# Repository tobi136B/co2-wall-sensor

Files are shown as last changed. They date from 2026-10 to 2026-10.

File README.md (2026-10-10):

<div align="center">

# CO2 Wall Sensor

**A compact CO2, temperature and humidity monitor for Home Assistant.<br>
It covers a flush wall box or stands on your desk.**










**English** | [Deutsch](README.de.md) | [Project page and browser installer](https://tobi136b.github.io/co2-wall-sensor/)

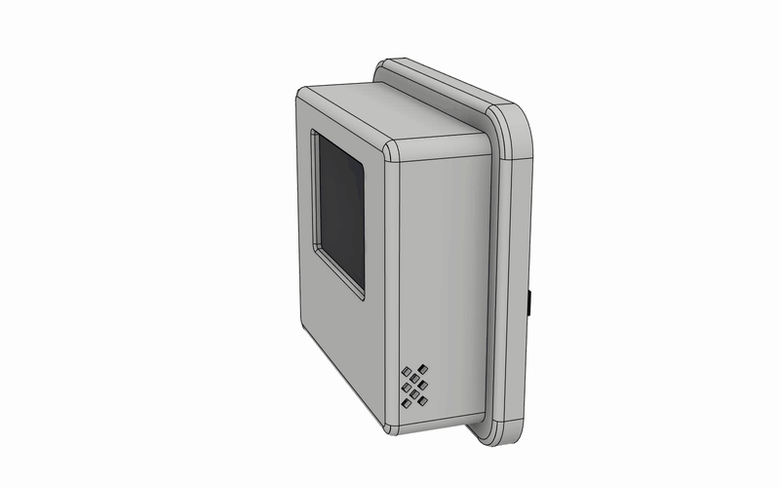
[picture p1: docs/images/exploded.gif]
The CO2 Wall Sensor takes itself apart part by part and assembles itself again


</div>

---

## Highlights

* **Flash it from your browser.** Connect the ESP32-C3 via USB, click *Install* on the [project page](https://tobi136b.github.io/co2-wall-sensor/), enter your WiFi. Home Assistant finds the device and offers new releases as a firmware update.
* **Real CO2 measurement** with the Sensirion SCD41 (photoacoustic NDIR), plus temperature and humidity.
* **2" IPS colour display** with everything at a glance: traffic light status, large CO2 value, 3 hour trend, clock, indoor and outdoor temperature and humidity.
* **Window hint.** The display tells you when opening the window cools the room or dries the air, using an outdoor sensor or simply your Home Assistant weather forecast.
* **Everything adjustable in Home Assistant.** Night schedule (dim or off), night brightness, warnings at night, temperature correction, altitude and hint thresholds, no reflashing needed.
* **One device, two mounts.** A dovetail rail slides onto the **wall plate** (two M4 screws with wall plugs, or the screws of a 68 mm flush wall box) or the **desk stand**.
* **Cable from the back or from below** with the same parts: a 90° USB-C adapter leads the cable straight into the wall, or a straight cable leaves through the window in the bottom.
* **One screw type, nothing glued.** 10 heat-set inserts M2 × 3 and 10 button head screws M2 × 4. The SCD41 and the ESP32-C3 slide into rails and click behind spring hooks, the display cable stays plugged in and runs under a printed bridge.
* **Thought-through thermals.** The sensor lives in its own chamber below the electronics, fresh air enters from below, the front stays closed.
* **Fully parametric CAD.** Every dimension is a Fusion user parameter. Change a value, run the script, get new STL, STEP, print plates and drawing.
* **Bilingual.** Firmware, documentation, drawings and project page in English and German.

<div align="center">
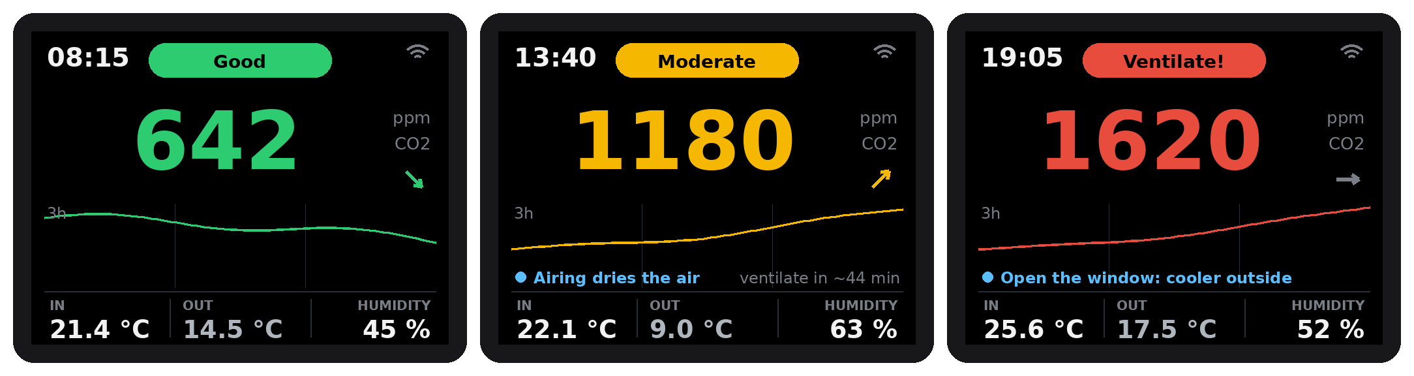
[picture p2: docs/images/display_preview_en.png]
Display layout in the three air quality states

<br><sub>Display layout in the three states (mock-up generated by <code>tools/display_preview.py</code>)</sub>
</div>

## How it works

```mermaid
flowchart LR
    SCD41["SCD41<br>CO2 / temp / humidity"] -- I2C --> ESP["ESP32-C3 SuperMini<br>ESPHome"]
    ESP -- SPI --> LCD["2&quot; IPS display<br>320 x 240"]
    ESP <-- "WiFi, native API" --> HA["Home Assistant"]
    USB["USB-C 5 V<br>(wall box or surface cable)"] --> ESP
    GH["GitHub releases"] -. "firmware update" .-> HA
```

Every 30 seconds the SCD41 delivers a new reading. The ESP32-C3 updates the display, classifies the air quality against two thresholds (default 1000 and 1400 ppm) and reports everything to Home Assistant.

## Specifications

| | |
|---|---|
| Device | 77 × 69.8 × 24 mm (+ 3 mm rail) |
| Wall plate | 89.2 × 82 × 7 mm, slots for M4 screws 60 mm apart, also fits flush wall boxes Ø 68 mm |
| Display window | 41.8 × 31.6 mm, 320 × 240 px IPS |
| Sensor | Sensirion SCD41, 400 to 5000 ppm, ±(50 ppm + 5 % of reading) |
| Room size | one sensor per room; in open spaces up to about 500 m² ([FAQ](docs/faq.md#how-large-a-room-can-one-sensor-monitor)) |
| Power | 5 V via USB-C, about 0.5 W |
| Cable exit | back (90° USB-C adapter) or bottom (straight plug), same parts |
| Fasteners | 10 heat-set inserts M2 × 3 (OD 3.0 to 3.2), 10 screws M2 × 4 ISO 7380, 2 screws M4 for the wall |
| Print material | PETG (PLA possible), about 120 g |

Technical drawing (A3, ISO first angle): [English PDF](docs/drawing/co2_wall_sensor_drawing_en.pdf) | [German PDF](docs/drawing/co2_wall_sensor_drawing_de.pdf)

<div align="center">
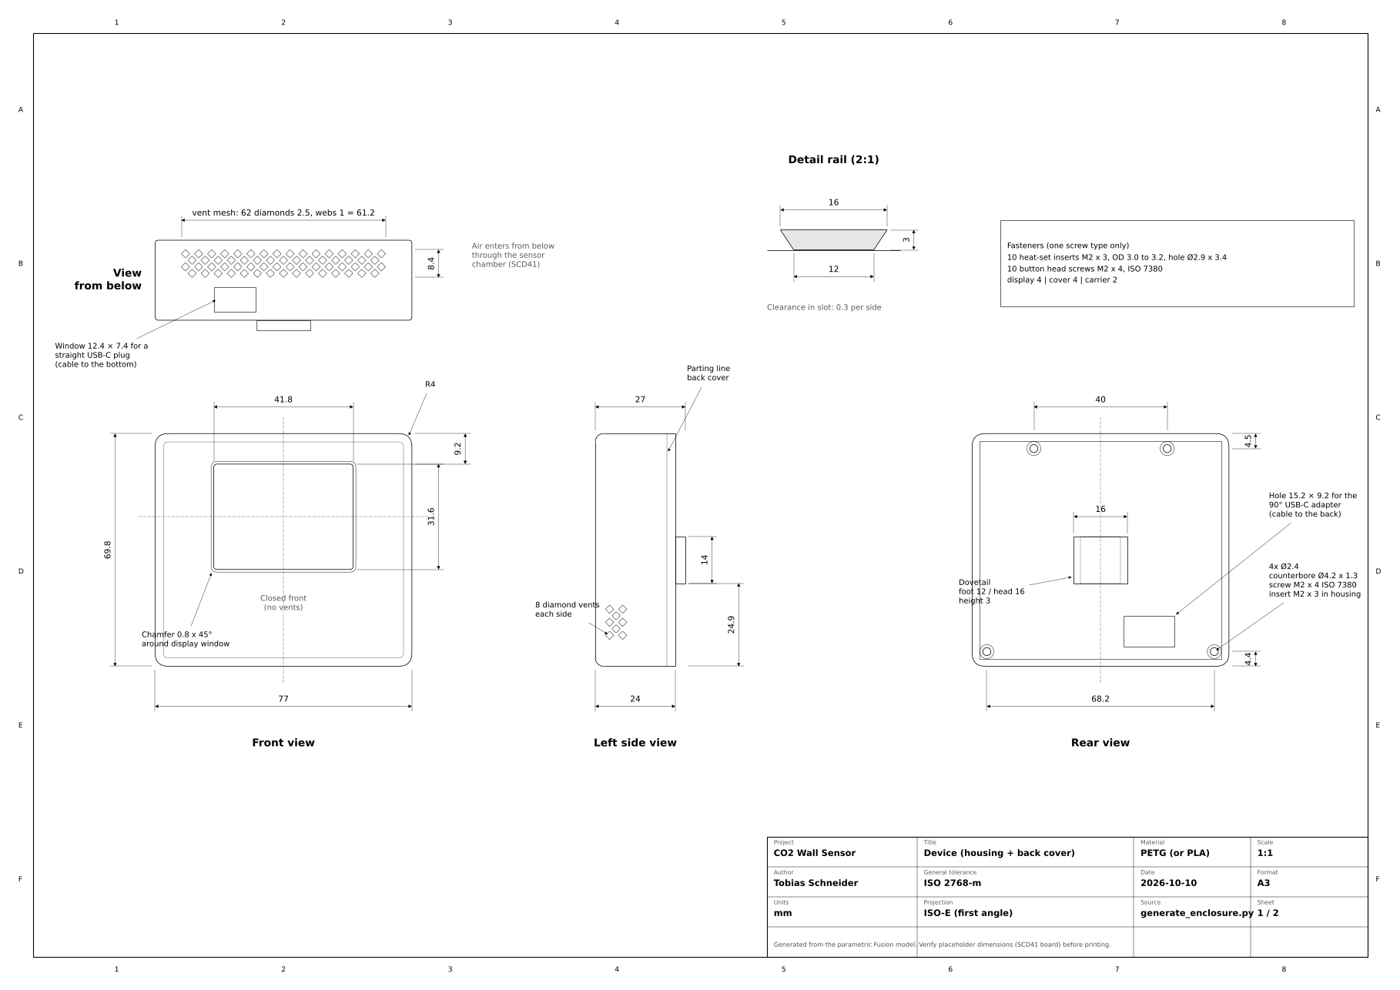
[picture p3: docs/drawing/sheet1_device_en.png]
Drawing sheet 1

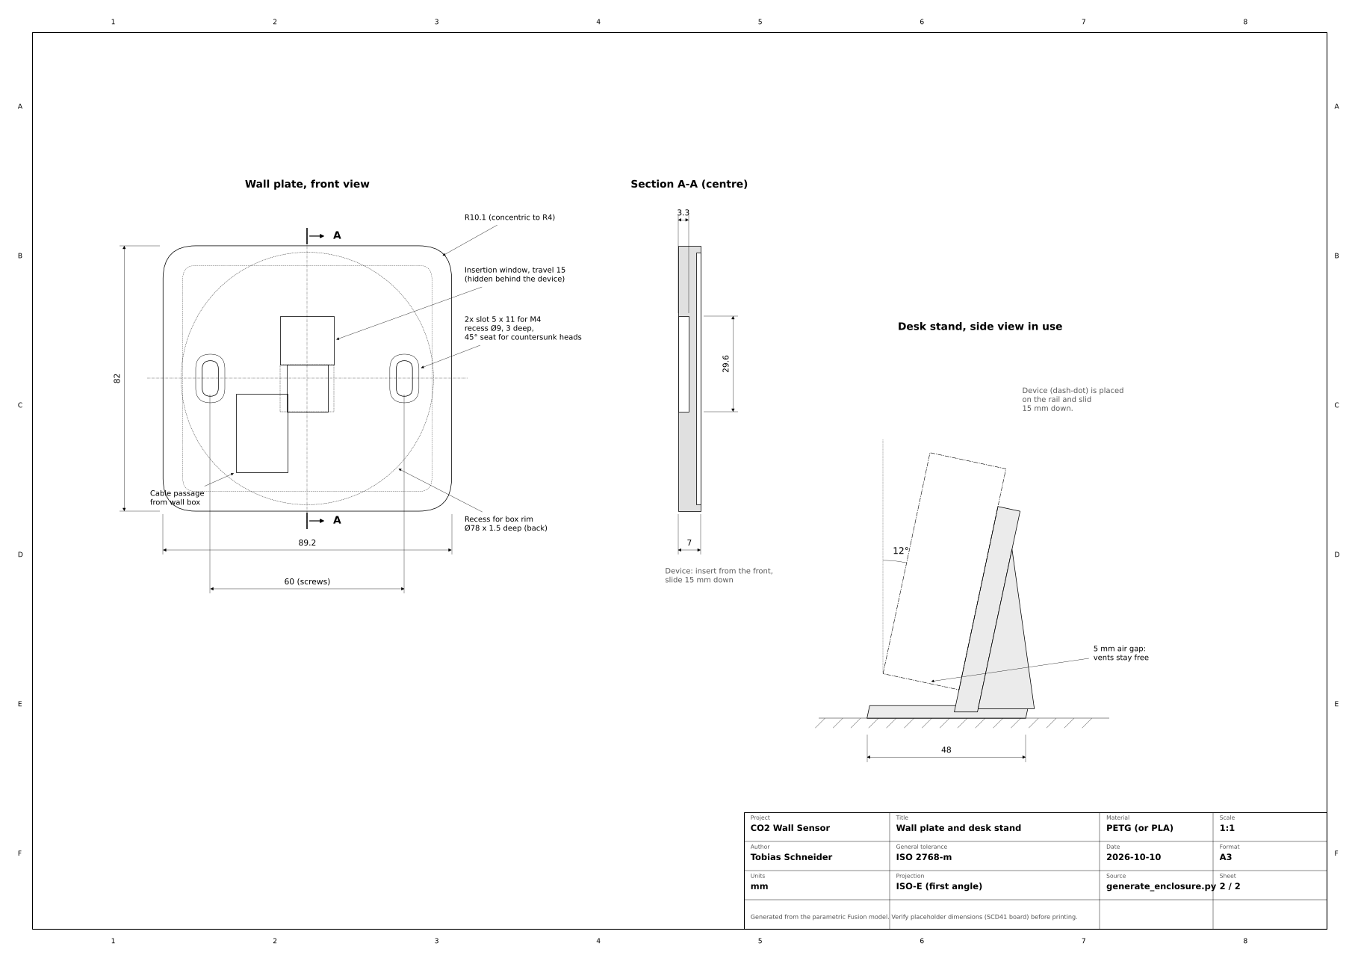
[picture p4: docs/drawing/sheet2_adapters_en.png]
Drawing sheet 2

</div>

## Bill of materials

The total for one device is in the last row of the table. The links are suggestions, checked in October 2026; prices change often.

<!-- bom:start (generated from hardware/bom.yaml) -->
| Qty | Part | AliExpress | Amazon.de |
|----:|---|---:|---:|
| 1 | Sensirion **SCD41** breakout, **13.5 × 21.75 mm** or **15 × 20 mm** ² | [21.19 €](https://de.aliexpress.com/item/1005009740863220.html) | *AliExpress only* |
| 1 | **ESP32-C3 SuperMini** | [2.79 €](https://de.aliexpress.com/item/1005007479144456.html) | [4.30 € (2 pcs: 8.59 €)](https://www.amazon.de/dp/B0HDCHXHMT) |
| 1 | **Waveshare 2inch LCD Module** (ST7789V, 240 × 320) | [12.49 €](https://de.aliexpress.com/item/1005008772378337.html) | [16.31 €](https://www.amazon.de/dp/B081Q79X2F) |
| 10 | Heat-set insert **M2 × 3**, outer diameter 3.0 or 3.2 mm, length 3 mm | [2.39 € (50 pcs, OD 3.2)](https://de.aliexpress.com/item/1005008575446687.html) | [4.69 € (205 pcs, OD 3.0)](https://www.amazon.de/dp/B0GYPH7X6W) |
| 10 | Button head screw **M2 × 4**, ISO 7380 | *Amazon only* | [4.79 € (60 pcs)](https://www.amazon.de/dp/B0FVT11R5L) |
| 1 | **USB-C 90° adapter** (plug to socket) for the cable to the back | *Amazon only* | [4.49 €](https://www.amazon.de/dp/B0CVQ8LV5W) |
| 1 | USB power module for the flush wall box (installation by a qualified electrician), or any USB charger | *Amazon only* | [4.80 € (2 pcs: 9.59 €)](https://www.amazon.de/dp/B0GVWPHKJM) |
|  | Silicone wire AWG 30 | *Amazon only* | [15.49 € (8 colours)](https://www.amazon.de/dp/B0DH2FBWH7) |
| | **Total** (one device, each part from this shop if it has it, otherwise from the other; without wire and filament) | **52.94 €** | **60.57 €** |
<!-- bom:end -->

² Shops often show a different board than the one they send. Measure it on arrival and print the matching carrier.
SCD41 boards come in different sizes. Only the small sensor carrier depends on the board: there is one for the **13.5 × 21.75 mm** and one for the **15 × 20 mm** board, for others enter six measurements in the [online configurator](https://tobi136b.github.io/co2-wall-sensor/configurator.html) and download the carrier. See [measure your sensor](docs/measure-sensor.md).
Machine-readable: [`hardware/bom.yaml`](hardware/bom.yaml). This file is the only place for parts, prices and shop links; the table above and the project page are generated from it.

## Quick start

1. **Print** the two ready plates [`co2_wall_sensor_device.3mf`](cad/3mf/co2_wall_sensor_device.3mf) and [`co2_wall_sensor_mounts.3mf`](cad/3mf/co2_wall_sensor_mounts.3mf) (every part already in its print orientation, the device plate includes the desk stand: delete it for a wall mount) or the single files from [`cad/stl`](cad/stl). Settings: [docs/assembly.md](docs/assembly.md).
2. **Wire** the modules according to [docs/wiring.md](docs/wiring.md) and **assemble** them as described in [docs/assembly.md](docs/assembly.md). The [3D assembly guide](https://tobi136b.github.io/co2-wall-sensor/assembly.html) shows every step: turn the device, take it apart and see which part comes next.

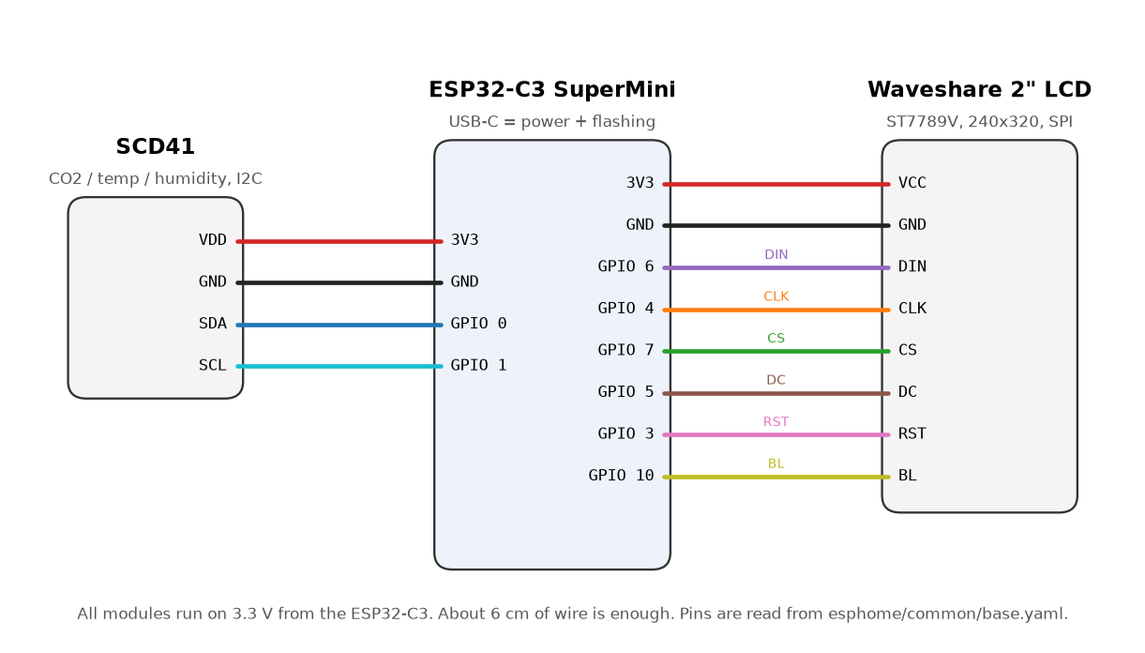
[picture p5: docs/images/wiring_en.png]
Wiring diagram
   

3. **Flash** the firmware from your browser on the [project page](https://tobi136b.github.io/co2-wall-sensor/). To build it yourself: copy `esphome/secrets.yaml.example` to `secrets.yaml`, fill it in and install [`esphome/co2-wall-sensor.yaml`](esphome/co2-wall-sensor.yaml) with the ESPHome Builder (German interface: [`co2-wall-sensor-de.yaml`](esphome/co2-wall-sensor-de.yaml)).
4. **Home Assistant** discovers the device automatically.

<div align="center">
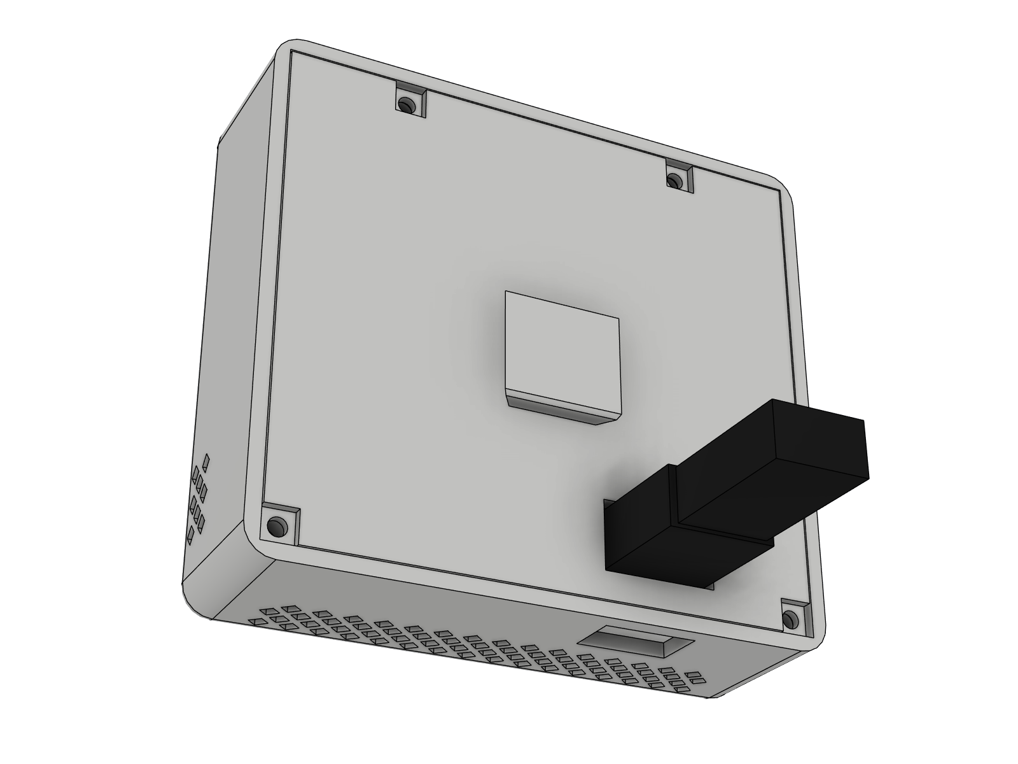
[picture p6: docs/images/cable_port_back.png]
Cable to the back

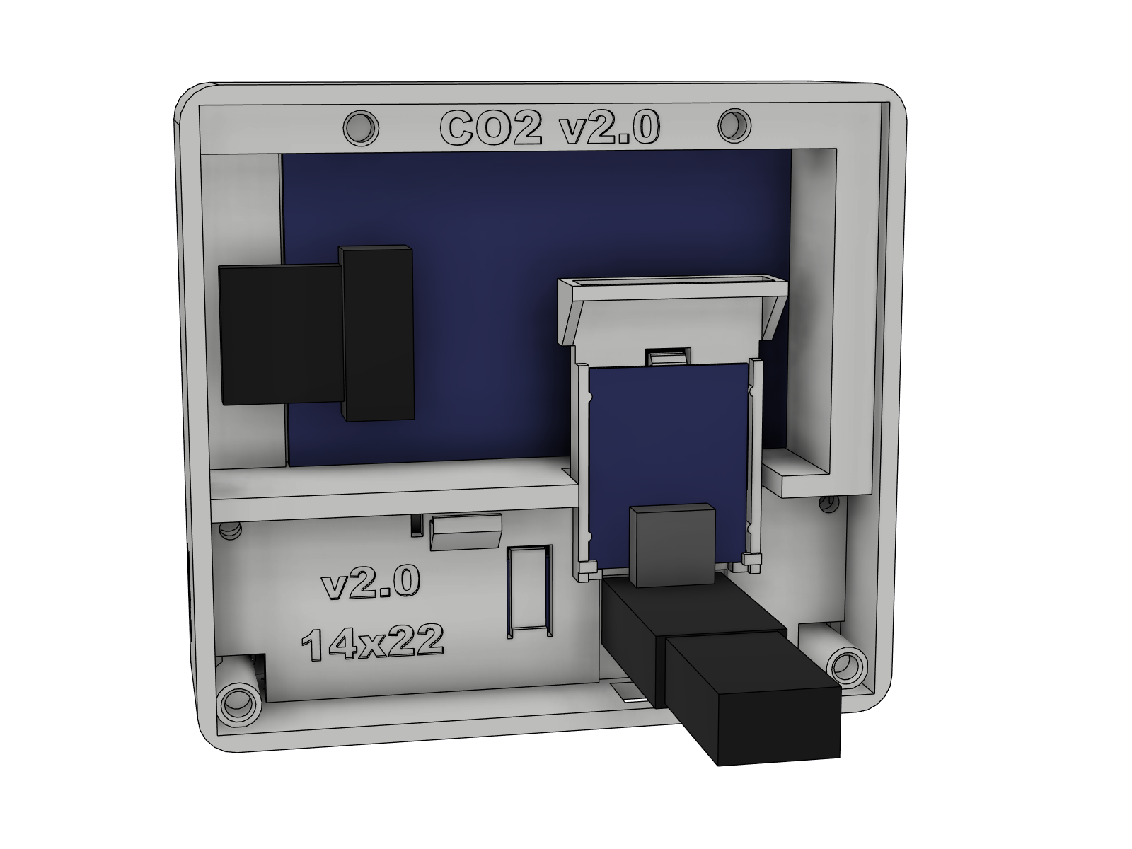
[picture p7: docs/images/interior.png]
Interior

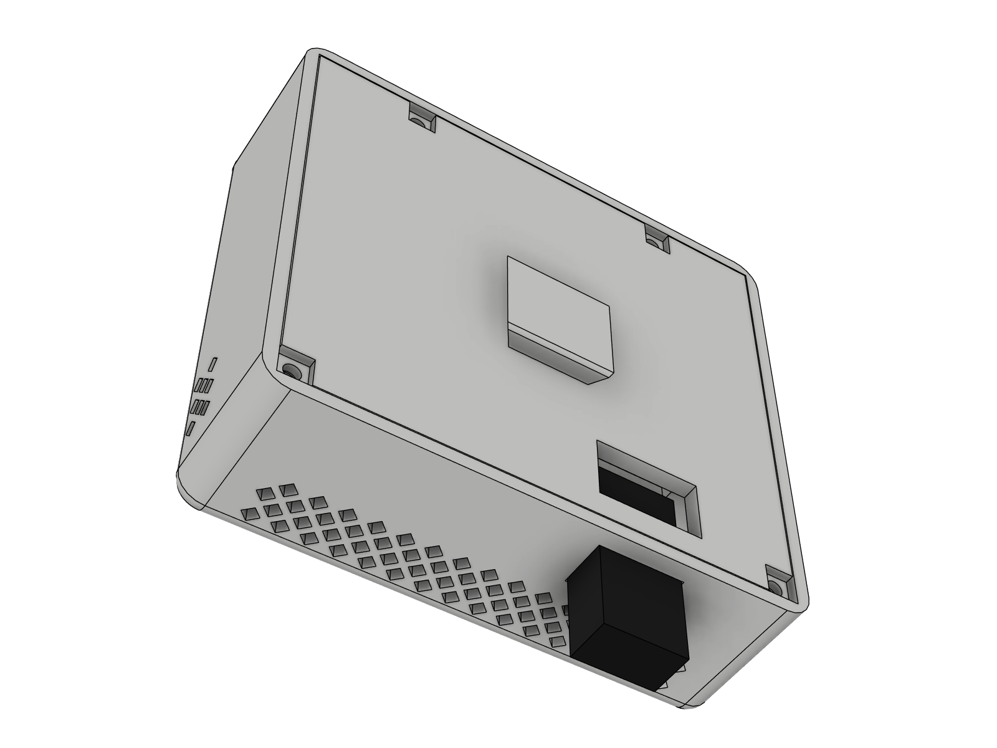
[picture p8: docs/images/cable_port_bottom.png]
Cable to the bottom

<br><sub>Cable to the back, the interior, cable to the bottom</sub>
</div>

## Home Assistant

| Entity | Type | Purpose |
|---|---|---|
| CO2, Temperature, Humidity | sensor | measurements every 30 s |
| CO2 trend, Ventilate in | sensor | ppm per hour, minutes until the red level |
| Air quality | text | Good, Moderate, Ventilate! |
| Outdoor temperature, Outdoor humidity | sensor | from Home Assistant, see [outdoor values](#outdoor-values) |
| Window hint | text | Open the window, Airing dries the air, Keep it shut, None |
| CO2 threshold yellow / red | number | traffic light limits (default 1000 / 1400 ppm) |
| Display brightness | light | dim or switch off the display by hand |
| Night mode, Night from, Night until | switch, time | night schedule (default 22:00 to 06:00) |
| Display at night, Night brightness | select, number | dim (default 8 %) or switch off |
| Red warning at night | switch | the display wakes up while the CO2 level is red |
| Window hint on the display, Outdoor value on the display | switch | show or hide them |
| Display upside down | switch | turns the picture by 180° if it stands on its head |
| Window hint from indoor temperature, Window hint: cooler outside by | number | default 24 °C and 3 °C |
| Temperature correction | number | self-heating at your wall: compare with a reference thermometer |
| Altitude above sea level | number | pressure compensation of the CO2 value (default 300 m) |
| Calibrate SCD41 (fresh air 420 ppm) | button | forced recalibration in fresh air |
| Firmware | update | new releases (browser installer firmware) |
| WiFi signal, Uptime, Restart | diagnostic | |

All settings are kept after a power cut. Nothing has to be built yourself: the browser installer firmware has every setting.

### Outdoor values

The display shows the outdoor temperature under **OUT**, and the window hint compares inside and outside.

* **Without anything to set up** the device takes `weather.forecast_home`, the weather entity Home Assistant creates for your home location (integration *Meteorologisk institutt (Met.no)*).
* **A real outdoor sensor wins.** Pair it as usual (Zigbee, Homematic IP, Shelly, ...), open it under *Settings > Devices & services > Entities*, click the gear and set the **entity ID** to `sensor.outdoor_temperature` (humidity: `sensor.outdoor_humidity`). A few seconds later the display shows it. No new firmware needed.

**Ventilation reminder:** a ready blueprint notifies your phone when the CO2 level stays high and again when the air is good.



More examples (automations, dashboard card) are in [`homeassistant/`](homeassistant).

## Repository structure

```text
co2-wall-sensor/
├── cad/
│   ├── fusion/generate_enclosure/   Fusion script, the single source of truth for all geometry
│   ├── fusion/co2_wall_sensor.f3d   Fusion archive of the assembly (with slider joint)
│   ├── 3mf/                         print-ready plates
│   ├── step/                        STEP of the full assembly
│   ├── stl/                         single print files
│   └── build_info.json              fingerprint of the parameters the print files were made from
├── docs/                            assembly, wiring, design notes, FAQ (German in docs/de)
│   ├── drawing/                     technical drawing, PDF + PNG, EN and DE
│   └── images/                      renders, animation, wiring diagram, display preview
├── esphome/
│   ├── co2-wall-sensor*.yaml        device files: own build and browser installer, EN and DE
│   └── common/                      shared firmware logic and network variants
├── hardware/bom.yaml                bill of materials with shop links
├── homeassistant/                   blueprint, automations and dashboard card (German in homeassistant/de)
├── site/                            template of the project page
└── tools/                           generators for drawing, wiring, preview, print plates, project page, checks
```

## Customising the enclosure

Every dimension is a **Fusion user parameter**.

1. In Fusion open *Utilities > Scripts and Add-Ins*, click **+** and add the folder `cad/fusion/generate_enclosure`. Run the script once.
2. Open *Modify > Change Parameters* and adjust values, for example `FIT` for tighter or looser fits, the `SCD_*` values for a different sensor board ([measure your sensor](docs/measure-sensor.md)) or `INSERT_HOLE_D` for other inserts.
3. Run the script again. It takes over your parameters, rebuilds every part and checks wall and desk assembly for interference. With `EXPORT = True` it writes new STL and STEP files and `cad/build_info.json`.
4. Regenerate drawing, print plates and the other generated files:

```bash
pip install -r requirements.txt
python tools/drawing.py && python tools/build_3mf.py
python tools/wiring.py && python tools/display_preview.py
python tools/check_repo.py
```

The CI repeats all of this, compiles four firmware variants and checks that the print files belong to the committed parameters. More background: [design notes](docs/design.md) and [FAQ](docs/faq.md).

## Before your first print

* **Versions:** the release number (e.g. 1.9.0) counts every change, firmware and docs included. The **enclosure version** (badge at the top, engraved on every printed part) only changes when the printed parts change. Parts with the same enclosure version fit together, whatever release they came from.
* **SCD41 board:** measure it and print the matching sensor carrier, see [measure your sensor](docs/measure-sensor.md). Other boards: [online configurator](https://tobi136b.github.io/co2-wall-sensor/configurator.html).
* **Display:** all dimensions of the Waveshare 2inch LCD Module are measured with a caliper (PCB 58.2 × 35.3 × 1.62 mm, glass 47.7 × 34.6 mm, PCB and glass 4.43 mm thick). Other batches may differ slightly: check `LCD_*` and `GLASS_*`.
* **Hardware status:** enclosure 2.0 contains the lessons of the first printed device and is verified in CAD and CI. The 90° USB-C adapter is not measured yet, its hole is generous. Photos and measurements of a printed device are welcome.

## Roadmap

* [x] Sensor carrier profiles for different SCD41 boards ([#7](https://github.com/tobi136B/co2-wall-sensor/issues/7), v1.4)
* [x] Interactive 3D assembly guide ([open it](https://tobi136b.github.io/co2-wall-sensor/assembly.html), v1.6)
* [x] ESP32-C3 holder from the measured board, tolerant to other batches (v1.7)
* [x] Collision check of every assembly path in the CI (v1.7)
* [x] Outdoor temperature on the display, with a hint when opening the window helps (v1.8)
* [x] Clean cable routing without glue: wire slot and wire clip on the sensor carrier, free cable path behind the display (v1.9)
* [x] [Online configurator](https://tobi136b.github.io/co2-wall-sensor/configurator.html): sensor carrier STL from the dimensions of the board ([#8](https://github.com/tobi136B/co2-wall-sensor/issues/8), v1.9)
* [x] Enclosure 2.0 after the first print: display cable stays plugged, ESP32-C3 on a sled with a spring hook, 90° adapter instead of the loose port module, wall plate for M4 screws (v2.0)
* [ ] Verify display layout and thermals on real hardware, add photos

## Contributing

Issues, ideas and pull requests are welcome, see [CONTRIBUTING.md](CONTRIBUTING.md). Questions and photos of your build go to [Discussions](https://github.com/tobi136B/co2-wall-sensor/discussions). Security issues: [SECURITY.md](SECURITY.md).

## License

Software and firmware: [MIT](LICENSE). Hardware (enclosure, print files, drawing, bill of materials): [CERN-OHL-P-2.0](LICENSE-HARDWARE). © 2026 Tobias Schneider. Build it, adapt it, share it.

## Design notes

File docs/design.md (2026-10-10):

# Design notes

**English** | [Deutsch](de/design.md)

This page explains why the device looks and works the way it does.

## Goals

1. Show air quality, temperature, humidity and time **on one screen**, readable from across the room.
2. **No visible cable** on the wall, but also usable on a desk.
3. Measurements that are **trustworthy**, not distorted by the device itself.
4. Everything reproducible and adjustable: **parametric CAD, generated documentation**.

## Why a SCD41?

Cheap "CO2" sensors such as the SGP30 or CCS811 only estimate an equivalent CO2 value from volatile organic compounds. The SCD41 measures CO2 directly (photoacoustic NDIR) with ±(50 ppm + 5 % of reading) and also provides temperature and humidity. It needs free air exchange, which drives the whole enclosure layout.

## Thermal concept

Every electronic device heats itself up. An ESP32 with WiFi and an LCD backlight easily lift an internal sensor by several kelvin. Countermeasures:

* **Separate sensor chamber** in the chin of the housing, closed towards the display bay by a divider and towards the ESP bay by the screwed sensor carrier. The carrier is a separate part, so the SCD41 is easy to mount and to replace.
* **Air enters from below** through a diamond mesh in the bottom and on both sides of the sensor chamber. Warm air from the electronics rises upwards behind the display, away from the sensor.
* **ESP32-C3 instead of a classic ESP32:** single core, no USB-UART chip, no charger. Less waste heat.
* **Narrow wire slot instead of a notch:** the four SCD41 wires lie side by side in the 1.3 mm slot and fill it. So no warm air is drawn from the ESP bay into the chamber, without glue. On the back a printed wire clip holds them.
* **Night mode** dims the backlight, which also reduces heat.
* The remaining offset is compensated by `temperature_offset` in the firmware (default 2.0 °C, verify against a reference).

## Closed front

The front has no openings. Dust settles mostly on openings that face up or forward, and an unbroken front simply looks calmer. All vents face down or sideways.

## Mounting: dovetail rail

A short dovetail rail on the back cover fits two adapters:

* **Wall plate 89.2 × 82 mm.** It is 6.1 mm larger than the device on every side and has corners concentric to the device, which creates an even frame like a light switch. Two M4 screws with wall plugs hold it, 60 mm apart in slots with 3 mm play up and down and a 45° seat for countersunk heads. The same slots take the screws of a German flush wall box (68 mm hole, rim about 75 mm), which the plate covers.
* **Desk stand.** Same rail, device leans back by 12° for better readability, with a 5 mm air gap below so the vents stay free.

The insertion window above the slot is hidden behind the device. You insert the device from the front and slide it 15 mm down. Nothing is visible from outside and the device can be removed without tools.

## Fastening: one screw type, all metal threads

Plastic threads wear out after a few cycles and self-tapping screws crack thin bosses. Every screw connection therefore uses a brass heat-set insert, and all of them use the same parts:

* **10 × heat-set insert M2 × 3** (outer diameter 3.0 or 3.2 mm, hole Ø 2.9 × 3.4 mm fits both): 4 for the display, 4 for the back cover, 2 for the sensor carrier.
* **10 × button head screw M2 × 4, ISO 7380.** One hex key for the whole device.
* **2 × screw M4** with wall plugs for the wall plate, the only other screws.

The back cover is held at four points: two bosses in the bottom corners and two inserts in a solid 5 mm band above the display bay. The button heads sit in 1.3 mm counterbores, so the cover surface stays flat and slides cleanly onto the wall plate and desk stand. The cover has no pins or hooks on its inside and prints flat without supports.

## Nothing is glued

* **SCD41:** the breakout has no mounting holes. It slides from the top into two rails with a groove on the front of the sensor carrier and stands on an end stop. A tongue cut out of the carrier carries a 45° hook that springs over the upper edge and presses the board onto the stop, so tolerances of ±0.4 mm are taken up without play. Only this carrier depends on the board: there is one per board profile, see [measure your sensor](measure-sensor.md).
* **ESP32-C3:** it has no mounting holes either. It slides down on a sled that carries it over its whole length, between side guides with crush ribs, until it stands on two end stops and slips into a short groove at its lower edge. Then a hook on a spring tongue clicks behind its upper edge, with a straight face, so the plug force cannot push the board up. The sled reaches over the divider into the display bay, 0.3 mm above the display connector. The groove sits where the board has no solder pads, so wires can be soldered along both edges.
* **Display cable:** it stays plugged into the display. The display bay is longer on one side, so the display only fits with its connector there and the electronics strip of the glass always sits behind the frame; the device is 77 mm wide for this, the window stays centred. The flat cable runs under a printed bridge on the sled, the back cover closes it from behind.
* **Sensor carrier:** two screws. It is the removable floor of the sensor chamber, so the sensor can be replaced without touching the display.

## Cable exit: the same parts for both ways

The ESP32-C3 sits with its USB-C socket pointing **down**, with 12.5 mm of free space below it.

* **To the back:** a 90° USB-C adapter (plug to socket) in the socket, its body points to the wall. It leaves through a hole in the back cover, and any USB-C cable goes straight into the flush wall box or through the desk stand. The carrier is open below the socket, so the adapter goes in with the board, before the carrier.
* **To the bottom:** a straight plug in the window of the bottom wall, which holds its overmould with 0.2 mm play.

Up to version 1.8 a small loose port module closed the opening, in two versions. It was hard to insert and fell out before the cover was on, and right-angle plugs differ in which way they bend. The adapter fixes the direction, and the window and the hole need no extra part. Thin knock-out membranes were tried before (v1.2), but they cannot be closed again once broken out.

## Printing details

* **45° foot on bed edges.** A fillet that starts tangent to the print bed prints badly: the lowest layers are almost horizontal and the first layer squeezes out (elephant foot). The soft front edge therefore ends in a short 45° chamfer that is tangent to the fillet. It looks round, but prints clean.
* **Entry chamfers** on all insert holes centre the insert and give the displaced plastic room.
* **Fillets at the root of the bosses** make them stronger, they do not crack while pressing inserts.
* **Lead-in chamfer** on the rail, so the device finds the slot easily.
* **Engraved labels** on hidden faces: the enclosure version in heavy letters, 0.6 mm deep and at least 2.4 mm high, so every stroke prints as at least one clean line of a 0.4 mm nozzle. The generator shrinks each text until it fits its field.
* **One fit value** (`FIT`) for every sliding or plugged fit.
* **Made for a 0.4 mm nozzle.** No wall is thinner than `MIN_WALL` (0.8 mm, two lines). Where a screw head recess would leave a thinner skin at the edge of a part, the recess is opened towards the edge; the housing wall closes it from outside. The CI measures the wall thickness of every STL file all over (`tools/print_check.py`) and fails below 0.8 mm.
* **Diamond vent mesh** instead of slots: the 45° edges print on the vertical walls without support, the webs are 1 mm wide and the open area is about 40 % larger than with the old slots.

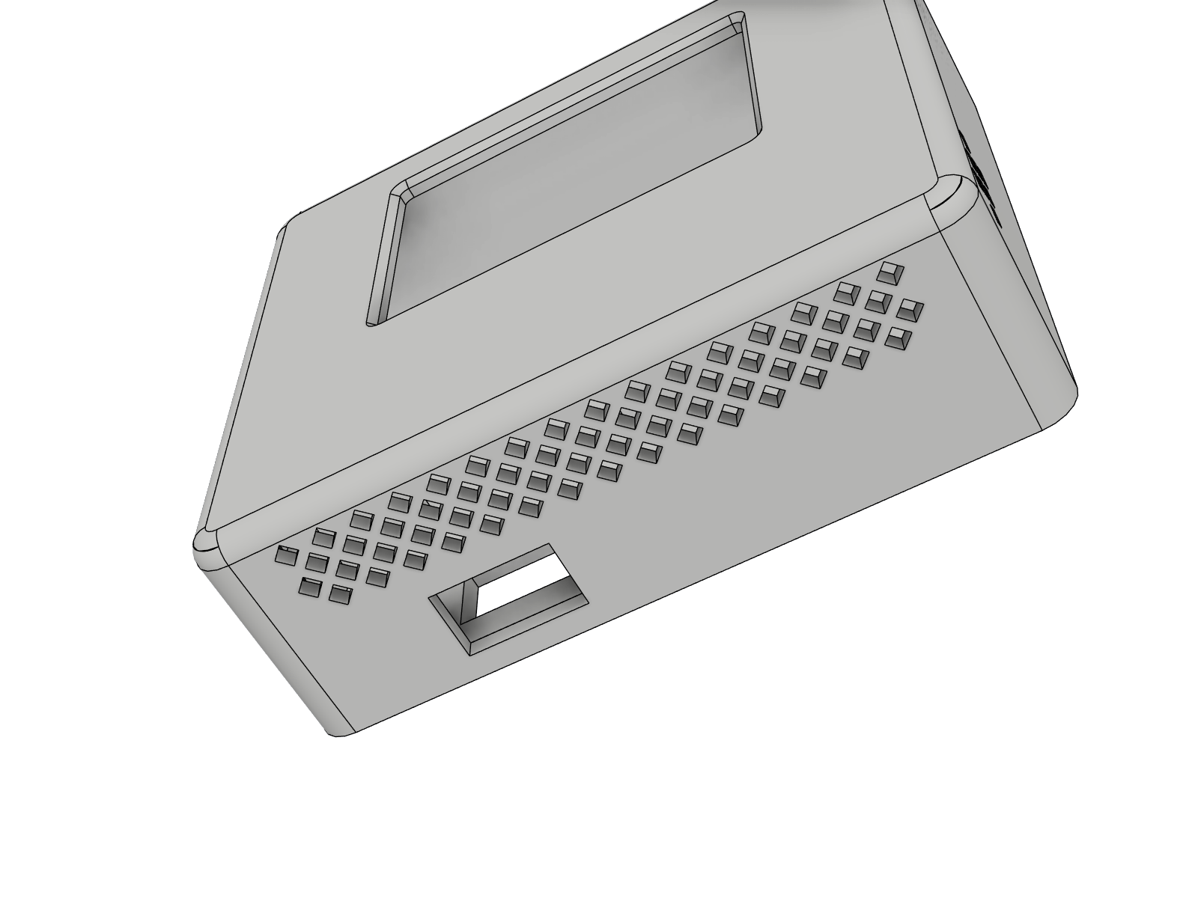
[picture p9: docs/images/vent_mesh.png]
Vent mesh in the bottom of the housing
  

## Parameters in Fusion

Every value of the parameter block becomes a Fusion user parameter (*Modify > Change Parameters*), with its explanation as comment. To change the enclosure, edit the values there and run the script again: it reads the parameters of the open design and rebuilds every part with them, including the interference check. The model is generated by a script and is not a hand-built history, so a changed value takes effect when the script runs, not live in the timeline.

The assembly has a slider joint ("RailSlider"): the device can be pushed up the rail by 15 mm, exactly as it is removed from the wall plate.

## Power

The device is permanently powered via USB-C (about 0.5 W, roughly 4 to 5 kWh per year). A battery version was considered and rejected: a colour display needs constant power, and lithium cells inside a closed housing on the wall are an unnecessary risk.

## Parametric CAD and generated documentation

The enclosure is not modelled by hand. [`generate_enclosure.py`](../cad/fusion/generate_enclosure/generate_enclosure.py) builds every part from a single block of parameters, checks wall and desk assembly for interference and can export STL and STEP files. The [technical drawing](../tools/drawing.py), the [wiring diagram](../tools/wiring.py) and the [display preview](../tools/display_preview.py) are generated from the same sources. Changing one dimension keeps model, drawing and documentation consistent.

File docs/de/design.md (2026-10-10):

# Designnotizen

[English](../design.md) | **Deutsch**

Hier steht, warum das Gerät so aussieht und so funktioniert, wie es ist.

## Ziele

1. Luftqualität, Temperatur, Luftfeuchte und Uhrzeit **auf einem Bildschirm**, lesbar quer durch den Raum.
2. **Kein sichtbares Kabel** an der Wand, aber auch auf dem Schreibtisch nutzbar.
3. **Vertrauenswürdige Messwerte**, die nicht vom Gerät selbst verfälscht werden.
4. Alles nachbaubar und anpassbar: **parametrisches CAD, generierte Doku**.

## Warum ein SCD41?

Günstige „CO2“-Sensoren wie SGP30 oder CCS811 schätzen nur einen CO2-Äquivalenzwert aus flüchtigen organischen Verbindungen. Der SCD41 misst CO2 direkt (photoakustisch, NDIR) mit ±(50 ppm + 5 % vom Messwert) und liefert dazu Temperatur und Luftfeuchte. Er braucht freien Luftaustausch, und genau das bestimmt den Aufbau des Gehäuses.

## Thermik

Jedes elektronische Gerät heizt sich selbst auf. Ein ESP32 mit WLAN und ein Display-Hintergrundlicht heben einen eingebauten Sensor schnell um mehrere Kelvin an. Gegenmaßnahmen:

* **Eigene Sensorkammer** im Kinn des Gehäuses, zum Display durch eine Trennwand und zum ESP durch den verschraubten Sensorträger abgeschlossen. Der Träger ist ein eigenes Teil, dadurch lässt sich der SCD41 leicht einbauen und tauschen.
* **Luft kommt von unten** durch ein Rautengitter im Boden und an beiden Seiten der Sensorkammer. Warme Luft der Elektronik steigt hinter dem Display nach oben, weg vom Sensor.
* **ESP32-C3 statt klassischem ESP32:** ein Kern, kein USB-UART-Chip, kein Laderegler. Weniger Abwärme.
* **Schmaler Kabelschlitz statt Kerbe:** Die vier SCD41-Litzen liegen nebeneinander im 1,3 mm breiten Schlitz und füllen ihn aus. So wird ohne Kleber keine warme Luft vom ESP in die Kammer gezogen. Auf der Rückseite hält ein mitgedruckter Kabelclip die Litzen.
* **Nachtmodus** dimmt das Hintergrundlicht und reduziert dabei auch die Wärme.
* Der Rest wird mit `temperature_offset` in der Firmware ausgeglichen (Standard 2,0 °C, mit Referenz prüfen).

## Geschlossene Front

Die Front hat keine Öffnungen. Staub setzt sich vor allem auf Öffnungen, die nach oben oder vorne zeigen, und eine durchgehende Front wirkt einfach ruhiger. Alle Lüftungsschlitze zeigen nach unten oder zur Seite.

## Montage: Schwalbenschwanzschiene

Eine kurze Schwalbenschwanzschiene am Rückdeckel passt in zwei Adapter:

* **Wandplatte 89,2 × 82 mm.** Sie ist rundum 6,1 mm größer als das Gerät und hat zum Gerät konzentrische Ecken. So entsteht ein gleichmäßiger Rahmen wie bei einem Lichtschalter. Zwei Schrauben M4 mit Dübeln halten sie, 60 mm auseinander in Langlöchern mit 3 mm Spiel nach oben und unten und einer 45°-Senkung für Senkköpfe. Dieselben Langlöcher nehmen die Schrauben einer Hohlwanddose (68 mm Bohrung, Rand ca. 75 mm), die die Platte verdeckt.
* **Tischständer.** Gleiche Schiene, das Gerät lehnt für bessere Lesbarkeit 12° nach hinten, mit 5 mm Luftspalt unten, damit die Lüftung frei bleibt.

Das Einsetzfenster über der Nut liegt verdeckt hinter dem Gerät. Gerät von vorne einsetzen und 15 mm nach unten schieben. Von außen ist nichts zu sehen, abnehmen geht ohne Werkzeug.

## Verschraubung: eine Schraubensorte, nur Metallgewinde

Kunststoffgewinde nutzen sich nach wenigen Zyklen ab, und selbstschneidende Schrauben sprengen dünne Dome. Deshalb sitzt an jeder Schraubstelle eine Einschmelzmutter aus Messing, überall mit denselben Teilen:

* **10 × Einschmelzmutter M2 × 3** (Außendurchmesser 3,0 oder 3,2 mm, Bohrung Ø 2,9 × 3,4 mm passt für beide): 4 für das Display, 4 für den Rückdeckel, 2 für den Sensorträger.
* **10 × Linsenkopfschraube (Halbrundkopf) M2 × 4, ISO 7380.** Ein Innensechskantschlüssel für das ganze Gerät.
* **2 × Schraube M4** mit Dübeln für die Wandplatte, die einzigen anderen Schrauben.

Der Rückdeckel wird an vier Punkten gehalten: zwei Dome in den unteren Ecken und zwei Einschmelzmuttern in einem massiven 5 mm Band über dem Displayschacht. Die Linsenköpfe sitzen in 1,3 mm tiefen Senkungen, die Deckelfläche bleibt plan und gleitet sauber auf Wandplatte und Tischständer. Der Deckel hat innen weder Stifte noch Haken und druckt flach ohne Stützmaterial.

## Nichts ist geklebt

* **SCD41:** Die Platine hat keine Befestigungslöcher. Sie wird von oben in zwei Schienen mit Nut auf der Frontseite des Sensorträgers geschoben und steht auf einem Anschlag. Eine aus dem Träger ausgeschnittene Zunge trägt einen 45° Haken, der über die Oberkante schnappt und die Platine auf den Anschlag drückt. So werden Toleranzen von ±0,4 mm spielfrei ausgeglichen. Nur dieser Träger hängt von der Platine ab: Es gibt einen pro Platinenprofil, siehe [Sensor ausmessen](sensor-ausmessen.md).
* **ESP32-C3:** Auch er hat keine Befestigungslöcher. Er gleitet auf einem Schlitten, der ihn auf ganzer Länge trägt, zwischen Seitenführungen mit Quetschrippen nach unten, bis er auf zwei Anschlägen steht und in eine kurze Nut an seiner Unterkante rutscht. Dann schnappt ein Haken auf einer Federzunge hinter seine Oberkante, mit gerader Fläche, damit die Steckkraft die Platine nicht nach oben drückt. Der Schlitten reicht über die Trennwand in den Displayschacht, 0,3 mm über dem Displaystecker. Die Nut sitzt dort, wo die Platine keine Lötpunkte hat, an beiden Längsseiten können also Litzen angelötet werden.
* **Displaykabel:** Es bleibt im Display stecken. Der Displayschacht ist auf einer Seite länger, das Display passt also nur mit dem Stecker dort hinein, und der Elektronikstreifen des Glases liegt immer hinter dem Rahmen; dafür ist das Gerät 77 mm breit, das Fenster bleibt mittig. Das Flachkabel läuft unter einer mitgedruckten Brücke auf dem Schlitten, der Rückdeckel schließt sie von hinten.
* **Sensorträger:** zwei Schrauben. Er ist der herausnehmbare Boden der Sensorkammer, der Sensor lässt sich tauschen, ohne das Display anzufassen.

## Kabelaustritt: dieselben Teile für beide Wege

Der ESP32-C3 sitzt mit der USB-C-Buchse **nach unten**, darunter sind 12,5 mm frei.

* **Nach hinten:** ein USB-C-Winkeladapter 90° (Stecker auf Buchse) in der Buchse, sein Körper zeigt zur Wand. Er geht durch ein Loch im Rückdeckel, und ein beliebiges USB-C-Kabel läuft gerade in die Hohlwanddose oder durch den Tischständer. Der Träger ist unter der Buchse offen, der Adapter kommt also mit der Platine, vor dem Träger.
* **Nach unten:** ein gerader Stecker im Fenster der Bodenwand, das seinen Steckerkörper mit 0,2 mm Spiel hält.

Bis Version 1.8 schloss ein kleines loses Port-Modul in zwei Versionen die Öffnung. Es ließ sich schlecht einsetzen und fiel heraus, bevor der Deckel drauf war, und Winkelstecker unterscheiden sich darin, in welche Richtung sie abknicken. Der Adapter legt die Richtung fest, und Fenster und Loch brauchen kein Zusatzteil. Dünne Ausbrechmembranen wurden vorher ausprobiert (v1.2), lassen sich nach dem Ausbrechen aber nicht wieder schließen.

## Details für den Druck

* **45° Fuß an Kanten auf dem Druckbett.** Eine Rundung, die tangential auf dem Druckbett beginnt, druckt schlecht: Die untersten Schichten sind fast waagrecht, und die erste Schicht quillt seitlich heraus (Elefantenfuß). Die weiche Frontkante endet deshalb in einer kurzen 45° Schräge, die tangential in die Rundung übergeht. Sie sieht rund aus, druckt aber sauber.
* **Einführschrägen** an allen Mutterlöchern zentrieren die Mutter und geben dem verdrängten Kunststoff Platz.
* **Verrundungen am Fuß der Dome** machen sie stabiler, sie brechen beim Eindrücken der Muttern nicht ab.
* **Einführschräge an der Schiene**, damit das Gerät die Nut leicht findet.
* **Eingeprägte Beschriftung** auf verdeckten Flächen: die Gehäuseversion in kräftiger Schrift, 0,6 mm tief und mindestens 2,4 mm hoch, damit jeder Strich mindestens eine saubere Linie einer 0,4 mm Düse ergibt. Der Generator verkleinert jeden Text, bis er in sein Feld passt.
* **Ein Passungswert** (`FIT`) für alle Schiebe- und Steckpassungen.
* **Ausgelegt für eine 0,4 mm Düse.** Keine Wand ist dünner als `MIN_WALL` (0,8 mm, zwei Linien). Wo eine Senkung für einen Schraubenkopf am Rand eines Teils eine dünnere Haut lassen würde, ist die Senkung zum Rand hin offen; die Gehäusewand schließt sie von außen. Die CI misst die Wandstärke jeder STL-Datei flächendeckend (`tools/print_check.py`) und schlägt unter 0,8 mm fehl.
* **Rautengitter** statt Schlitzen: Die 45° Kanten drucken an den senkrechten Wänden ohne Stützmaterial, die Stege sind 1 mm breit und die offene Fläche ist rund 40 % größer als mit den alten Schlitzen.

  Rautengitter im Boden des Gehäuses

## Parameter in Fusion

Jeder Wert des Parameterblocks wird ein Fusion-Benutzerparameter (*Ändern > Parameter ändern*), mit seiner Erklärung als Kommentar. Zum Ändern die Werte dort anpassen und das Skript erneut starten: Es liest die Parameter der offenen Konstruktion und baut alle Teile damit neu, inklusive Kollisionsprüfung. Das Modell entsteht per Skript und hat keine von Hand aufgebaute Zeitleiste, ein geänderter Wert wirkt also beim Skriptlauf und nicht sofort in der Zeitleiste.

Die Baugruppe hat ein Schiebegelenk ("RailSlider"): Das Gerät lässt sich 15 mm auf der Schiene nach oben schieben, genau wie beim Abnehmen von der Wandplatte.

## Stromversorgung

Das Gerät hängt dauerhaft an USB-C (ca. 0,5 W, grob 4 bis 5 kWh im Jahr). Eine Akkuversion wurde geprüft und verworfen: Ein Farbdisplay braucht dauerhaft Strom, und Lithiumzellen in einem geschlossenen Gehäuse an der Wand sind ein unnötiges Risiko.

## Parametrisches CAD und generierte Doku

Das Gehäuse wird nicht von Hand modelliert. [`generate_enclosure.py`](../../cad/fusion/generate_enclosure/generate_enclosure.py) baut alle Teile aus einem einzigen Parameterblock, prüft Wand- und Tischaufbau auf Kollisionen und exportiert auf Wunsch STL und STEP. [Technische Zeichnung](../../tools/drawing.py), [Verdrahtungsplan](../../tools/wiring.py) und [Displayvorschau](../../tools/display_preview.py) entstehen aus denselben Quellen. Wer ein Maß ändert, hält Modell, Zeichnung und Doku automatisch gleich.

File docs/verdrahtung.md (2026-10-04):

# Verdrahtung

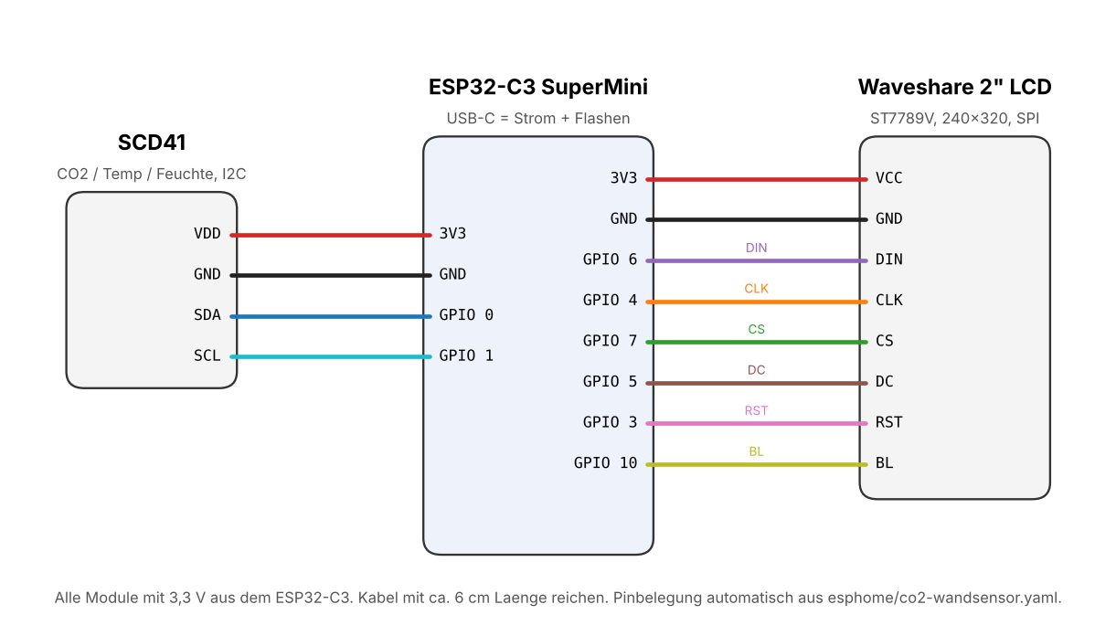
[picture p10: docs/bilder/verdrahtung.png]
Verdrahtungsplan


Alle Module laufen mit 3,3 V direkt aus dem ESP32-C3 SuperMini. Strom kommt über die USB-C-Buchse des ESP.

## ESP32-C3 SuperMini zu Waveshare 2inch LCD (SPI)

| LCD | ESP32-C3 | Funktion |
|-----|---|---|
| VCC | 3V3 | Versorgung 3,3 V |
| GND | GND | Masse |
| DIN | GPIO6 | SPI MOSI |
| CLK | GPIO4 | SPI Takt |
| CS  | GPIO7 | Chip Select |
| DC  | GPIO5 | Daten/Kommando |
| RST | GPIO3 | Reset |
| BL  | GPIO10 | Hintergrundlicht (PWM, dimmbar) |

## ESP32-C3 SuperMini zu SCD41 (I²C)

| SCD41 | ESP32-C3 | Funktion |
|---|---|---|
| VDD | 3V3 | Versorgung 3,3 V |
| GND | GND | Masse |
| SDA | GPIO0 | I²C Daten |
| SCL | GPIO1 | I²C Takt |

## Warum genau diese Pins?

* **GPIO2, GPIO8 und GPIO9** sind Strapping-Pins des ESP32-C3 (GPIO8 hängt zusätzlich an der blauen LED, GPIO9 am BOOT-Taster). Sie bleiben frei, damit das Board immer sauber startet.
* **GPIO18 und GPIO19** sind die USB-Datenleitungen und bleiben ebenfalls frei.
* **GPIO10** ist PWM-fähig und steuert die Displayhelligkeit, damit der Nachtmodus funktioniert.

Der Verdrahtungsplan wird mit `python tools/verdrahtung.py` direkt aus `esphome/co2-wandsensor.yaml` erzeugt. Wer Pins in der YAML ändert, erzeugt den Plan einfach neu.

## Tipps

* Kabellänge etwa 6 cm, dünne Litze (AWG 28 bis 30) passt gut durch die Kabeldurchführungen.
* Die SCD41-Leitungen durch die Kerbe im Zwischenboden führen und die Kerbe danach mit etwas Heißkleber abdichten. So zieht keine warme Luft vom ESP in die Sensorkammer.
* Vor dem Einbau einmal komplett auf dem Tisch testen.

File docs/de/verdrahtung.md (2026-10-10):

# Verdrahtung

[English](../wiring.md) | **Deutsch**

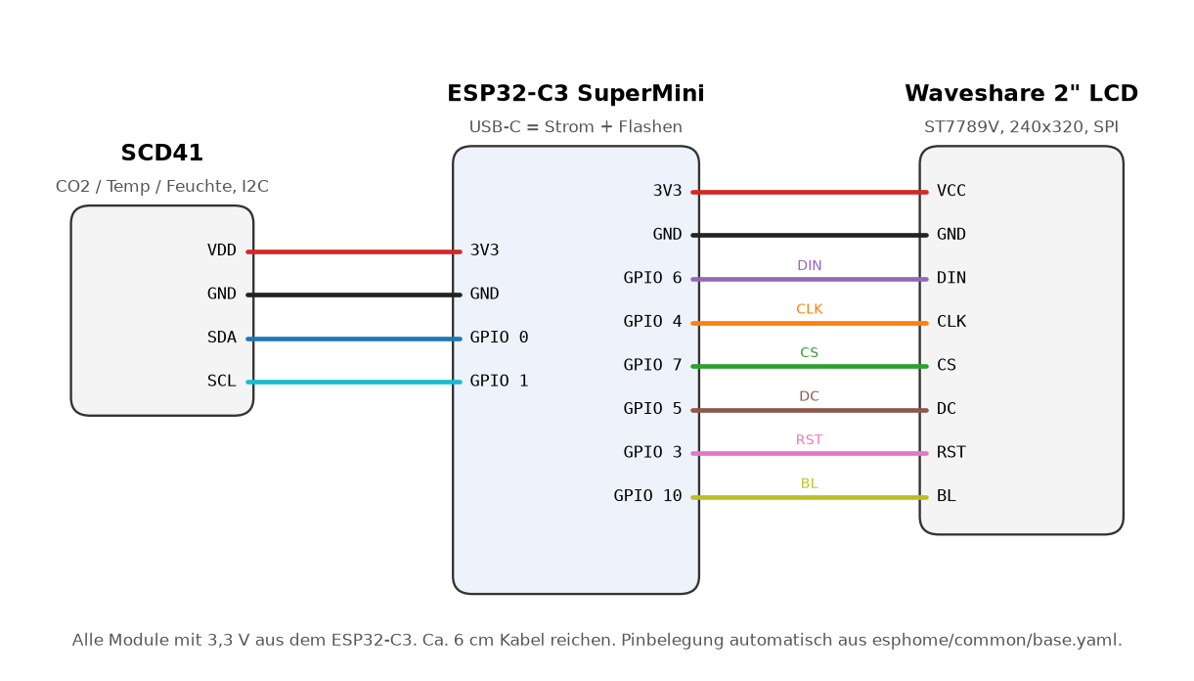
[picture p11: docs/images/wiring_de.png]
Verdrahtungsplan


Alle Module laufen mit 3,3 V direkt aus dem ESP32-C3 SuperMini. Strom kommt über die USB-C-Buchse des ESP.

## ESP32-C3 SuperMini zu Waveshare 2inch LCD (SPI)

| LCD | ESP32-C3 | Funktion |
|-----|---|---|
| VCC | 3V3 | Versorgung 3,3 V |
| GND | GND | Masse |
| DIN | GPIO6 | SPI MOSI |
| CLK | GPIO4 | SPI Takt |
| CS  | GPIO7 | Chip Select |
| DC  | GPIO5 | Daten / Kommando |
| RST | GPIO3 | Reset |
| BL  | GPIO10 | Hintergrundlicht (PWM, dimmbar) |

## ESP32-C3 SuperMini zu SCD41 (I2C)

| SCD41 | ESP32-C3 | Funktion |
|---|---|---|
| VDD | 3V3 | Versorgung 3,3 V |
| GND | GND | Masse |
| SDA | GPIO0 | I2C Daten |
| SCL | GPIO1 | I2C Takt |

## Warum genau diese Pins?

* **GPIO2, GPIO8 und GPIO9** sind Strapping-Pins des ESP32-C3 (GPIO8 hängt zusätzlich an der blauen LED, GPIO9 am BOOT-Taster). Sie bleiben frei, damit das Board immer sauber startet.
* **GPIO18 und GPIO19** sind die USB-Datenleitungen und bleiben ebenfalls frei.
* **GPIO10** ist PWM-fähig und dimmt das Hintergrundlicht, damit funktioniert der Nachtmodus.

Der Plan wird mit `python tools/wiring.py` direkt aus `esphome/common/base.yaml` erzeugt. Wer Pins in der YAML ändert, erzeugt den Plan einfach neu.

## Tipps

* **Display:** Das beiliegende PH2.0-Kabel bleibt im Display stecken. Es faltet sich an der linken Wand zurück (von hinten gesehen) und läuft hinter dem Display hinüber zum Schlitten und unter der Brücke durch, dann geht jede Ader zu ihrem Lötpunkt am ESP32-C3. Zuerst einlegen, die Längen an den Lötpunkten anzeichnen, dann kürzen und löten. Zum Ausbauen des Displays nur den Stecker ziehen.
* **SCD41:** 4 Litzen AWG 30 von ca. 8 cm. Sie liegen nebeneinander im schmalen Kabelschlitz des Sensorträgers und auf der Rückseite unter der Lippe des Kabelclips. Kleber ist nicht nötig.
* Der SCD41 zieht für wenige Millisekunden bis ca. 200 mA. Der 3,3-V-Regler des SuperMini schafft das, die Versorgungsleitungen trotzdem kurz halten.
* Alles zuerst auf dem Tisch testen, dann einbauen.

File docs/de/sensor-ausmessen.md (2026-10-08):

# SCD41-Platine ausmessen

[English](../measure-sensor.md) | **Deutsch**

SCD41-Platinen gibt es in mehreren Größen, und das Foto im Shop zeigt oft eine andere Platine als die, die ankommt. Das Gehäuse löst das mit **einem kleinen Teil**: dem Sensorträger. Gehäuse, Rückdeckel, Kabelports, Wandplatte und Tischständer sind für jede Platine gleich.

## 1. Mit den bekannten Platinen vergleichen

Länge und Breite der Platine ohne Bauteile mit dem Messschieber messen.

| Platine | Größe | Träger | Hinweise |
|---|---|---|---|
| **14x22** | 13,5 × 21,75 mm, Platine 1,5 mm | [`sensor_carrier_14x22.stl`](../../cad/stl/sensor_carrier_14x22.stl) | Lötpunkte GND, VDD, SCL, SDA an einer kurzen Kante. Liegt quer im Träger. 2026 die häufigste Platine. |
| **15x20** | 15 × 20 mm, Platine 1,6 mm | [`sensor_carrier_15x20.stl`](../../cad/stl/sensor_carrier_15x20.stl) | Steht hochkant im Träger. |

Abweichungen von ein paar Zehnteln sind kein Problem: Die **Federzunge** drückt die Platine auf ihren Anschlag und gleicht ±0,4 mm in Schieberichtung aus. Passt deine Platine, druckst du diesen Träger und bist fertig.

## 2. Andere Platine: sechs Werte messen

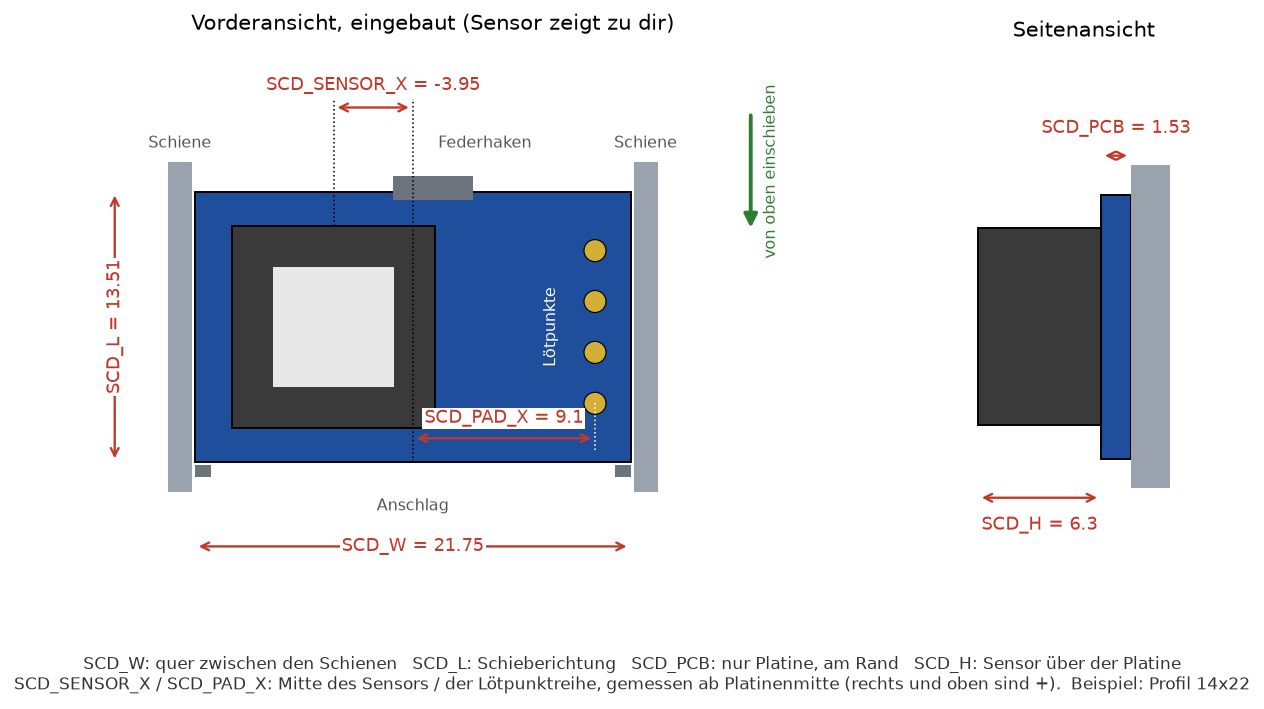
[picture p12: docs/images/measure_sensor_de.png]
Messskizze


Die Platine so halten, **wie sie eingebaut wird**: Sensor zeigt zu dir, Lötpunkte auf der Seite des Kabelschlitzes (von vorne gesehen oben rechts).

| Parameter | Was messen |
|---|---|
| `SCD_W` | Breite quer zwischen den Schienen, von Kante zu Kante |
| `SCD_L` | Länge in Schieberichtung |
| `SCD_PCB` | Dicke der Platine am Rand, ohne Bauteile |
| `SCD_H` | Gesamthöhe mit Sensor minus `SCD_PCB` |
| `SCD_SENSOR_X` | Mitte des Sensors ab Platinenmitte, rechts ist positiv |
| `SCD_PAD_X` | Mitte der Lötpunktreihe ab Platinenmitte, rechts ist positiv. `0`, wenn die Lötpunkte nicht an einer Schiene liegen |

In die Kammer passen Platinen bis 20 mm in Schieberichtung und rund 40 mm quer, fast jede Platine passt also in der einen oder anderen Lage.

## 3. Träger erzeugen

**Im Browser (am einfachsten):** den [Sensorträger-Konfigurator](https://tobi136b.github.io/co2-wall-sensor/de/configurator.html) öffnen, die sechs Werte eintragen und die STL herunterladen. Er erzeugt denselben Träger wie Fusion, die CI vergleicht beide für jede bekannte Platine.

**In Fusion:**

1. Das Skript in Fusion einmal ausführen (siehe [Gehäuse anpassen](../../README.de.md#gehäuse-anpassen)).
2. Die sechs Werte unter *Ändern > Parameter ändern* eintragen.
3. Das Skript mit `EXPORT = True` erneut ausführen. Es schreibt `cad/stl/sensor_carrier_custom.stl` und prüft, dass nichts kollidiert.
4. Nur den Träger drucken.

Bitte [ein Issue anlegen](https://github.com/tobi136B/co2-wall-sensor/issues/new/choose) mit deinen Werten und einem Foto der Platine. Sie wird als Profil aufgenommen, dann kann der Nächste den Träger einfach herunterladen.

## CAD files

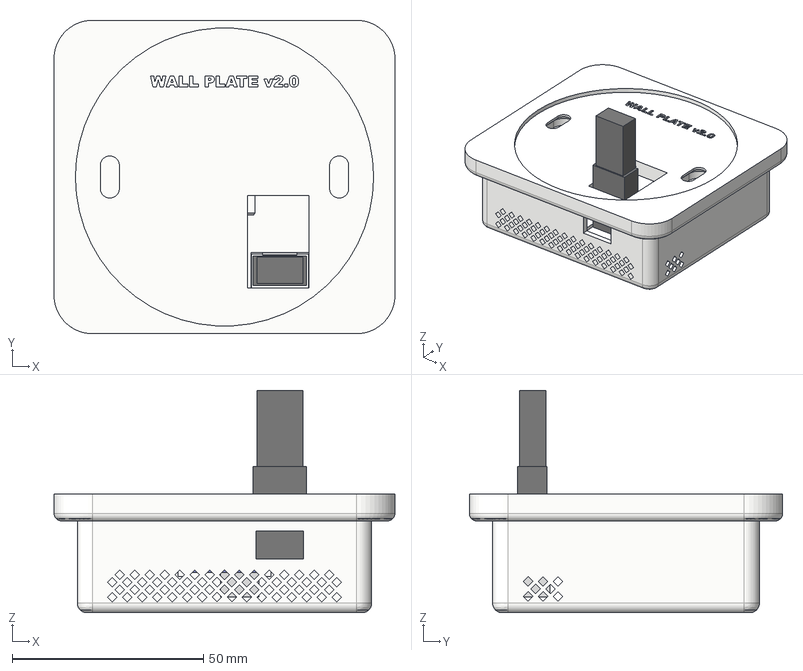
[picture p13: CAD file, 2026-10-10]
cad/step/co2_wall_sensor_assembly.step
89.2 x 82.0 x 58.2 mm

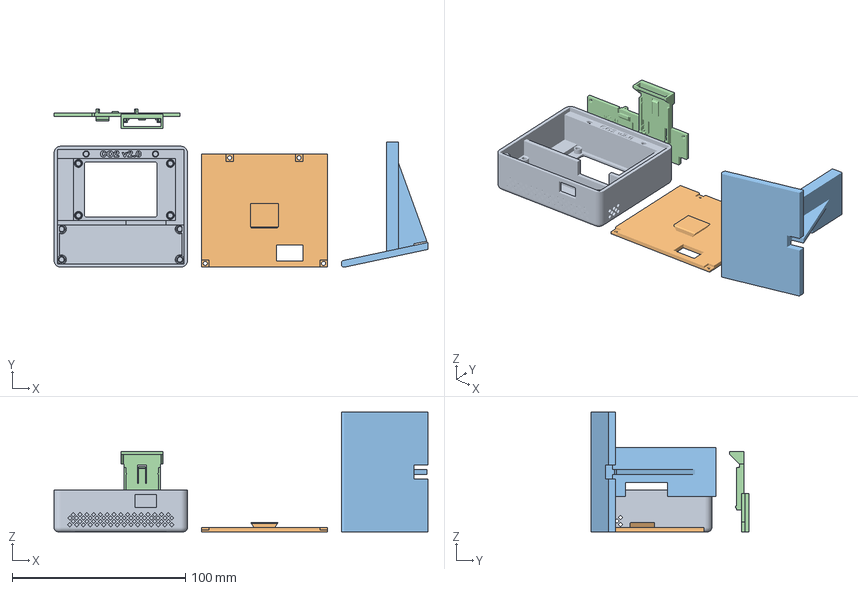
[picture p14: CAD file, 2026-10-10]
cad/3mf/co2_wall_sensor_device.3mf
215.6 x 91.4 x 69.0 mm
housing
back_cover
desk_stand
sensor_carrier_14x22

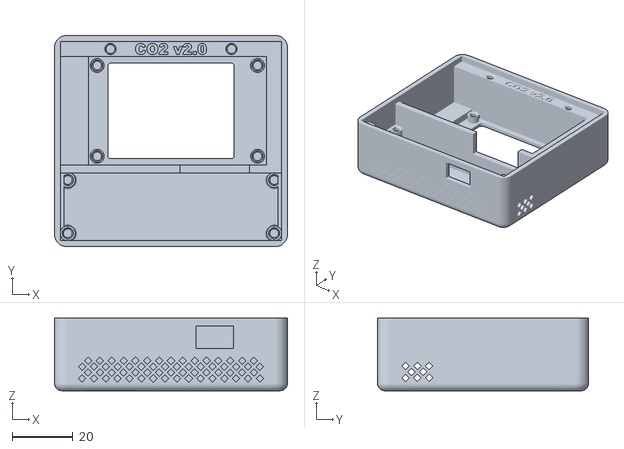
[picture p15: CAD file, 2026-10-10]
cad/stl/housing.stl
77.0 x 69.8 x 24.0

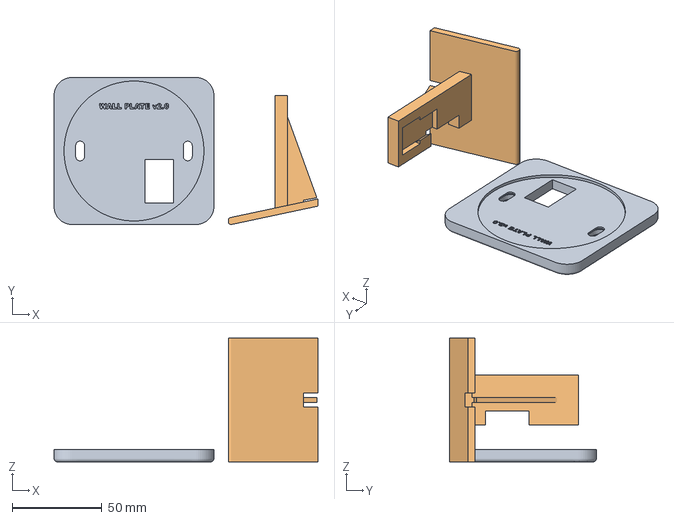
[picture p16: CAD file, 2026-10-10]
cad/3mf/co2_wall_sensor_mounts.3mf
147.2 x 82.0 x 69.0 mm
wall_plate
desk_stand

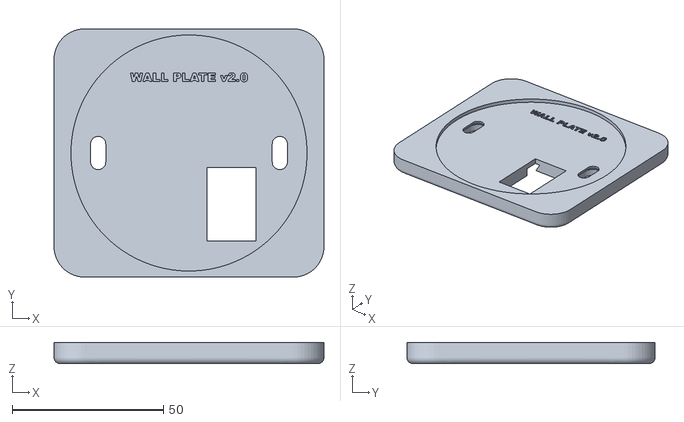
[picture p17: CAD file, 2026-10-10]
cad/stl/wall_plate.stl
89.2 x 82.0 x 7.00

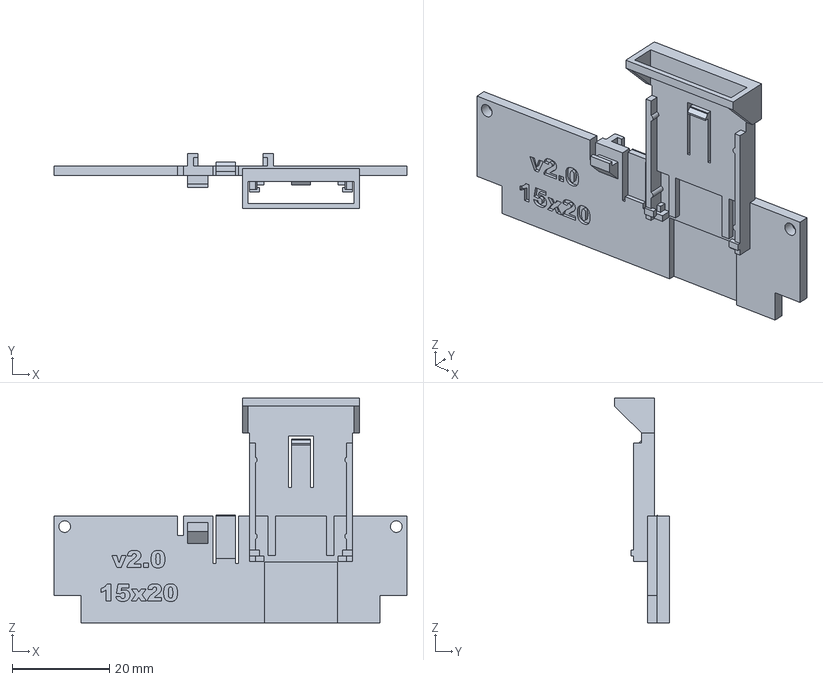
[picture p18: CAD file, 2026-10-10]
cad/3mf/sensor_carrier_15x20.3mf
72.6 x 11.3 x 46.2 mm

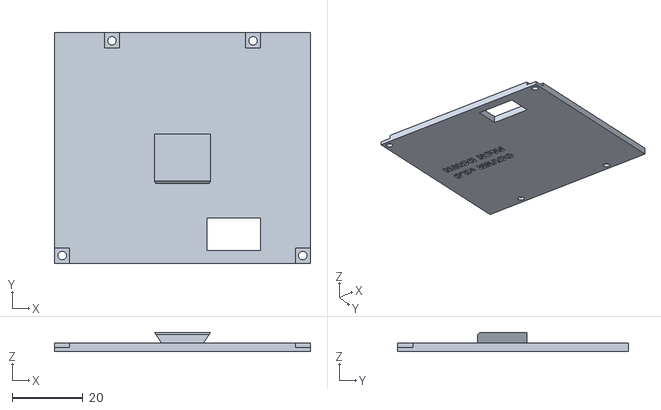
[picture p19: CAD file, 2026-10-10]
cad/stl/back_cover.stl
72.6 x 65.4 x 5.50

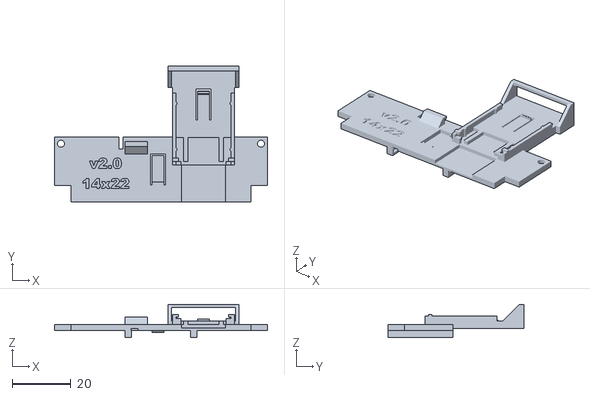
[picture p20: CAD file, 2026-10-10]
cad/stl/sensor_carrier_14x22.stl
72.6 x 46.2 x 11.3

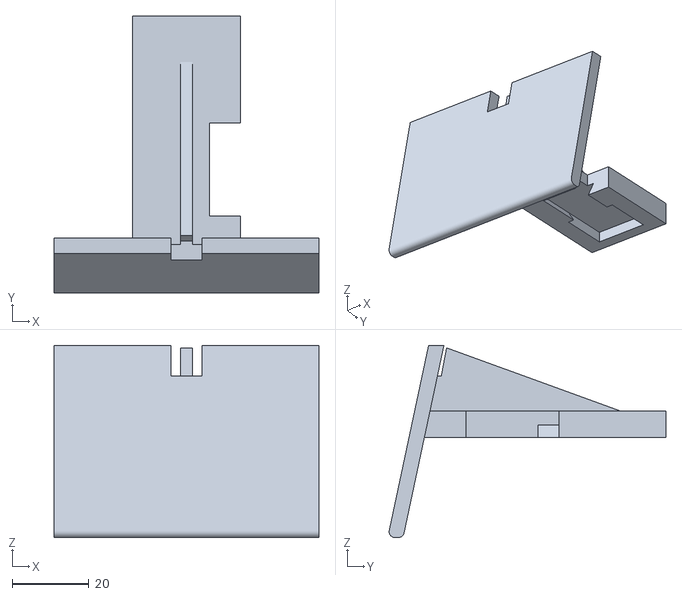
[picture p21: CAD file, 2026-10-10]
cad/stl/desk_stand.stl
69.0 x 72.1 x 50.0

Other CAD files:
cad/fusion/co2_wall_sensor.f3d
cad/stl/sensor_carrier_15x20.stl

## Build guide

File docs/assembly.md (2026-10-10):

# Printing and assembly

**English** | [Deutsch](de/aufbau.md)

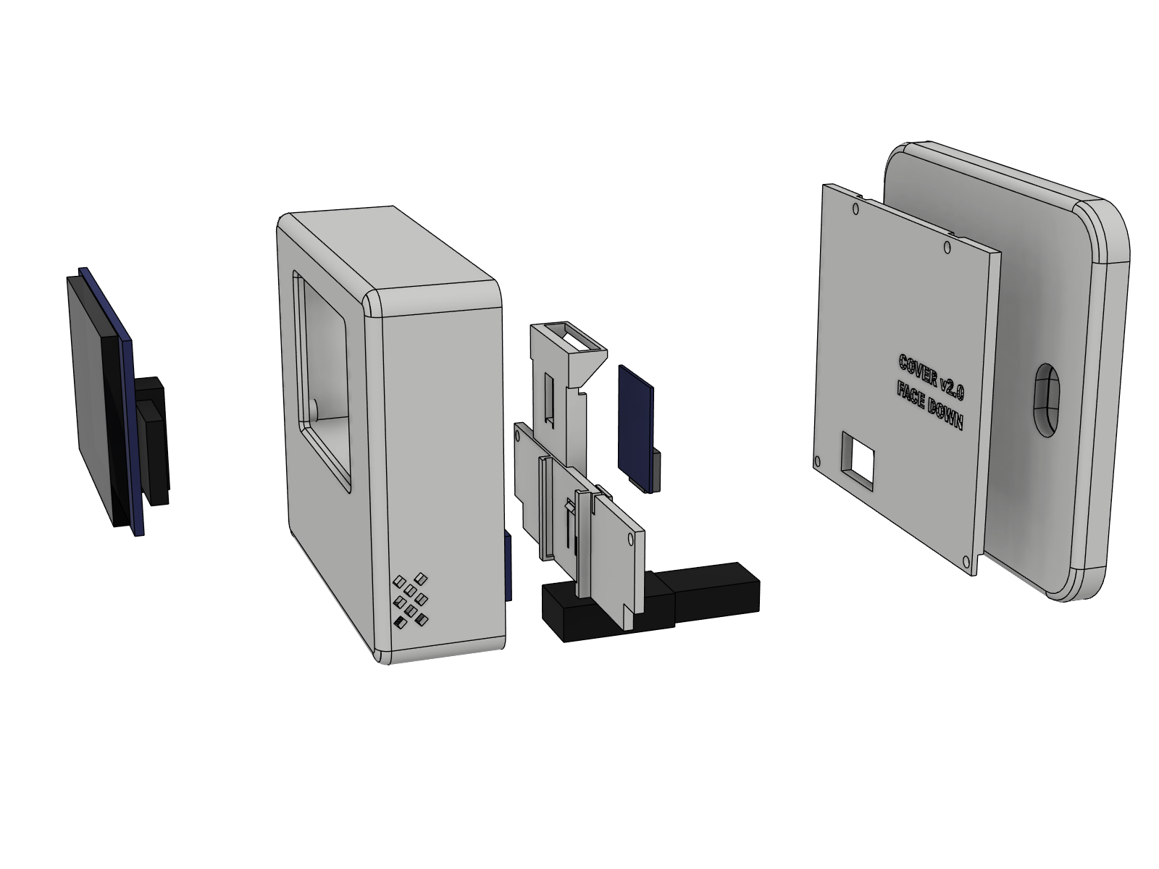
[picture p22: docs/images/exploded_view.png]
Exploded view


**Prefer it in 3D?** The [interactive assembly guide](https://tobi136b.github.io/co2-wall-sensor/assembly.html) walks through all 12 steps. Turn the device, take it apart with the slider, look through the housing and see which part comes next.

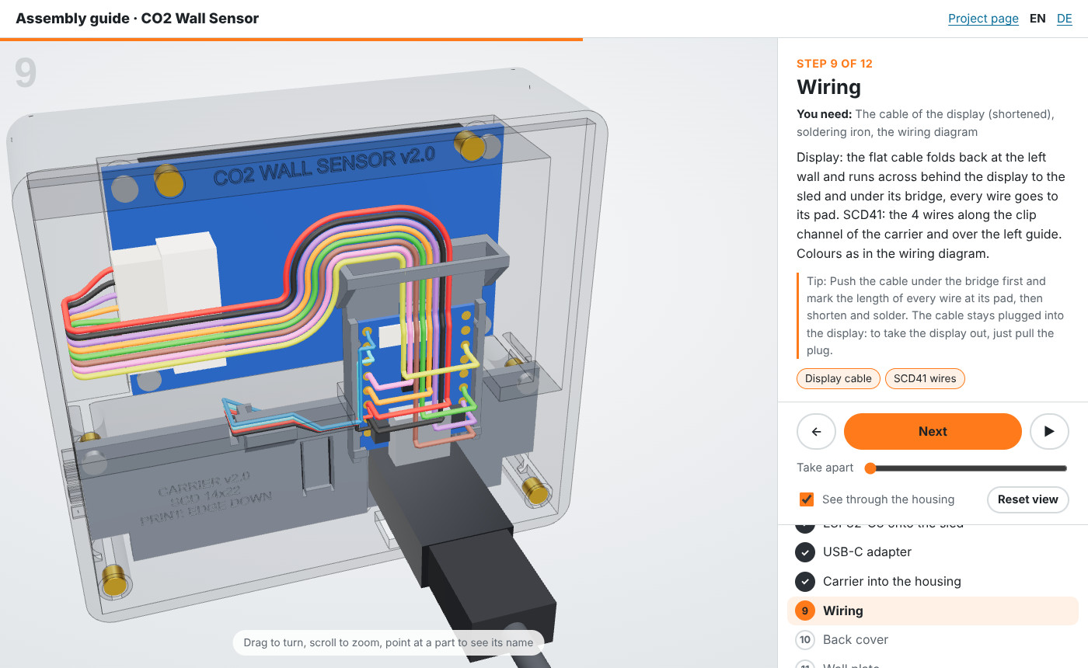
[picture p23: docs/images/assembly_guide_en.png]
3D assembly guide


## 1. 3D printing

Every part carries the enclosure version as a bold engraved label on a hidden face (the carrier also its sensor profile), large enough to print cleanly with a 0.4 mm nozzle.

| Part | File | Orientation | Notes |
|---|---|---|---|
| Housing | [`housing.stl`](../cad/stl/housing.stl) | front face down | The front lies on the bed (a textured PEI sheet looks great). A 45° foot on the front edge prevents elephant foot. No supports. |
| Sensor carrier | [`sensor_carrier_14x22.stl`](../cad/stl/sensor_carrier_14x22.stl) or [`sensor_carrier_15x20.stl`](../cad/stl/sensor_carrier_15x20.stl) | standing on its lower edge | **Matching your SCD41 board**, see [measure your sensor](measure-sensor.md). Printed on edge the rails become vertical channels, both spring tongues grow upwards and the cable bridge prints without support. Use a 5 mm brim. |
| Back cover | [`back_cover.stl`](../cad/stl/back_cover.stl) | inside face down | Label "FACE DOWN". Rail points up, no supports. The same cover for both cable exits. |
| Wall plate | [`wall_plate.stl`](../cad/stl/wall_plate.stl) | **front face down** | The front gets the bed surface. Printed the other way round, the 78 mm recess for the box rim would have to be bridged. |
| Desk stand | [`desk_stand.stl`](../cad/stl/desk_stand.stl) | on its side | Printed on its side the rail is strongest. |

**Recommended settings:** PETG, 0.2 mm layers, 3 walls, 20 % gyroid infill, seam position "rear" or "aligned". PLA works too but may soften in summer behind a sunny window.

**Two colours:** housing in matte black or anthracite, wall plate in the colour of your light switches (usually pure white). The result looks like a switch insert in its frame.

**Fit too tight or too loose?** All sliding and plugged fits depend on one value, `FIT` (0.3 mm per side). Change it in Fusion under *Modify > Change Parameters*, run the script again and print the affected part. See [design notes](design.md#parameters-in-fusion).

## 2. Fasteners: one screw type for everything

| Qty | Part | Where |
|----:|---|---|
| 10 | Heat-set insert **M2 × 3**, outer diameter 3.0 or 3.2 mm (hole Ø 2.9 × 3.4 mm fits both) | 4 display, 4 back cover, 2 sensor carrier |
| 10 | Button head screw **M2 × 4**, ISO 7380, hex socket 1.3 mm | same positions |
| 2 | Screw **M4** with 6 mm wall plug, pan head or countersunk | wall plate |

The wall plate has slots 5 mm wide with 3 mm play up and down and a 45° seat, so pan heads and countersunk heads both sit below its face. The two screws of a flush wall box (60 mm apart) fit the same slots. Nothing in the device is glued.

## 3. Choose the cable exit

Both ways work with the same printed parts:

| Cable | What you need | Use |
|---|---|-----|
| **To the back** | 90° USB-C adapter (plug to socket) in the socket of the ESP32-C3, any USB-C cable plugged into it | flush wall box and **always on the desk stand** |
| **To the bottom** | straight USB-C plug, overmould at most 12 × 7 mm | cable on the wall surface, power bank below the device |

Cable to the back Cable to the bottom

The adapter points to the wall and leaves through the hole in the back cover, the cable goes straight through the passage of the wall plate into the box. A straight plug goes into the window in the bottom wall, which holds it with a snug fit. With the plug at the bottom, the hole in the back cover simply stays empty, it faces the wall.

The hole is generous (adapter body 14 × 8 mm plus 0.6 mm play). For a bulkier adapter change `ADAPTER_W`, `ADAPTER_T` and `ADAPTER_L` in Fusion, see [design notes](design.md#parameters-in-fusion).

## 4. Step by step

**Before you start, have at hand:** soldering iron with a fine tip, hex key 1.3 mm, small flat screwdriver, side cutter. All 12 steps are also in the [3D assembly guide](https://tobi136b.github.io/co2-wall-sensor/assembly.html), where you can turn every step and take the device apart.

<!-- steps:start (generated from site/assembly_steps.yaml) -->

### Step 1 of 12: The housing

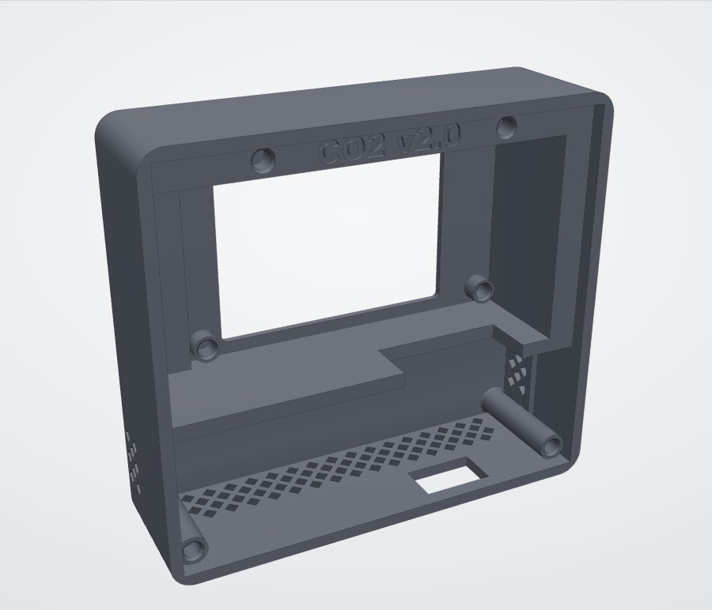
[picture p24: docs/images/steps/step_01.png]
The housing


**You need:** Printed housing

Printed front face down. You look at it from the back, the side that later faces the wall. Right and left in this guide are always seen from the back, like here. ([see it in 3D](https://tobi136b.github.io/co2-wall-sensor/assembly.html#step-1))

> **Tip:** No supports needed. Remove the brim and check that the four cover seats in the corners are clean.

### Step 2 of 12: 10 heat-set inserts

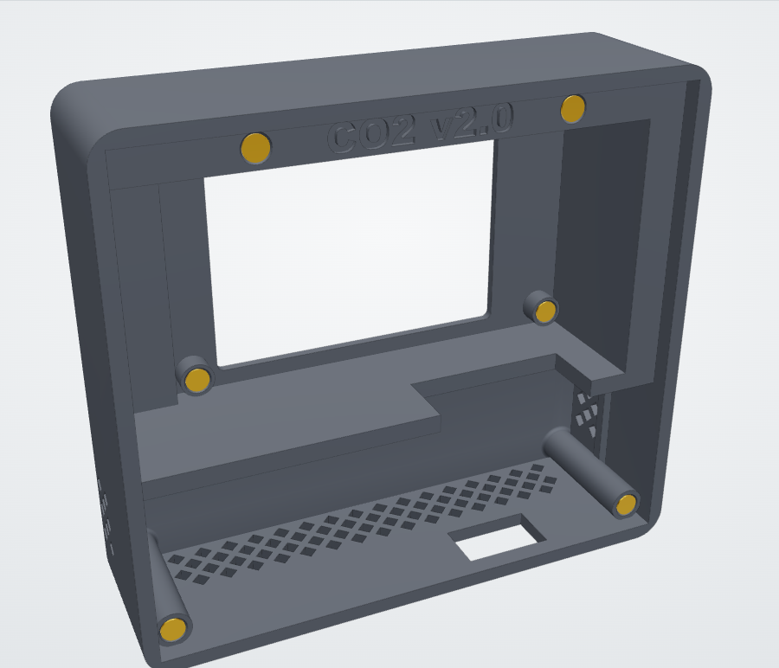
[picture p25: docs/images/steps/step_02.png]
10 heat-set inserts


**You need:** 10 heat-set inserts M2 × 3, soldering iron at 200 to 220 °C

Press the M2 inserts in with the soldering iron (about 200 to 220 °C). 4 around the display bay, 4 for the back cover, 2 for the sensor carrier. The entry chamfer centres them. ([see it in 3D](https://tobi136b.github.io/co2-wall-sensor/assembly.html#step-2))

> **Tip:** Set the insert on the hole, touch it with the iron and let it sink under its own weight until it is flush. Do not push. The front behind the 4 display domes is only 1.1 mm thick: little heat, no pressure.

### Step 3 of 12: Display

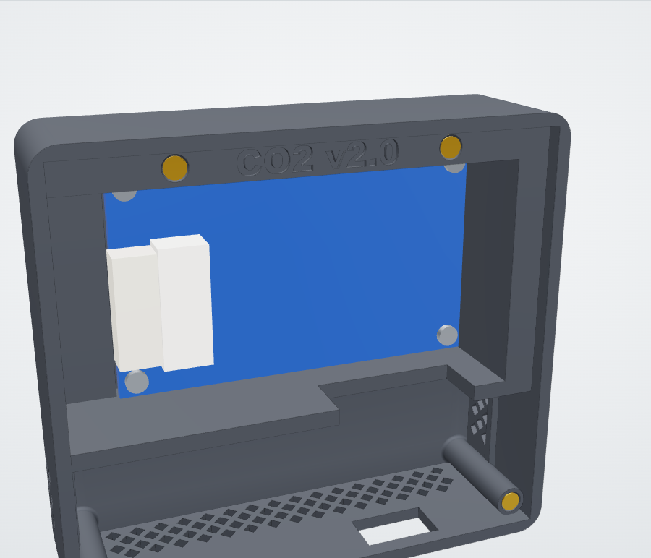
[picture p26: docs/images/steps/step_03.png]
Display


**You need:** Display with its cable plugged in, 4 screws M2 × 4, hex key 1.3 mm

Plug the supplied cable into the display first. Then glass first into the display bay, connector to the left, and 4 screws M2 × 4 through the corner holes. ([see it in 3D](https://tobi136b.github.io/co2-wall-sensor/assembly.html#step-3))

> **Tip:** It fits only one way: the connector on the left, where the bay is longer. Then the picture stands upright and the strip with the electronics hides behind the frame. Keep the protective film on the glass until the end.

### Step 4 of 12: Sensor carrier

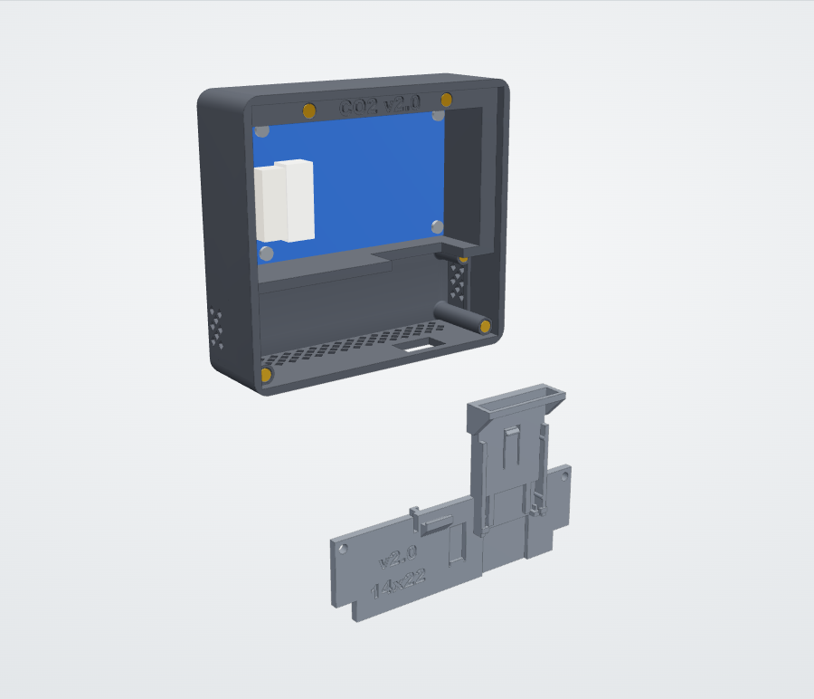
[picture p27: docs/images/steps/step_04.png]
Sensor carrier


**You need:** Sensor carrier for your SCD41 board

The carrier is the removable floor of the sensor chamber and holds the ESP32-C3 on its back. Print the one that matches your SCD41 board, here the 13.5 × 21.75 mm version. ([see it in 3D](https://tobi136b.github.io/co2-wall-sensor/assembly.html#step-4))

> **Tip:** Not sure which board you have? See [measure your sensor](measure-sensor.md).

### Step 5 of 12: SCD41 into the rails

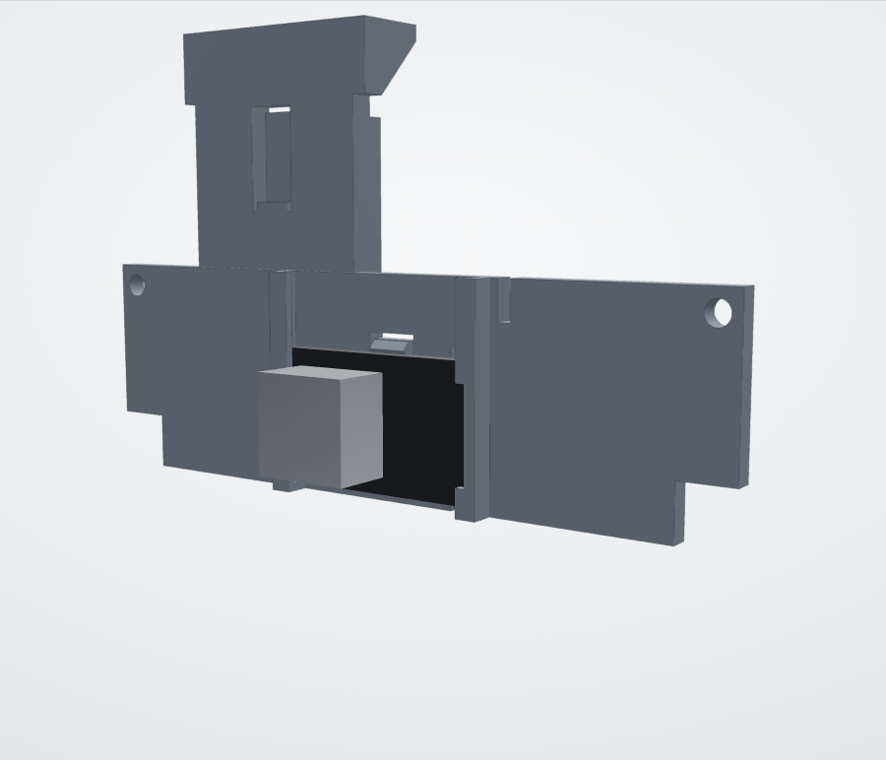
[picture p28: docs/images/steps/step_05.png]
SCD41 into the rails


**You need:** SCD41, 4 wires of about 8 cm, soldering iron

Solder four wires of about 8 cm to the pads first. Then slide the board in from the top, sensor towards you, pads towards the wire slot, until the spring tongue clicks over the upper edge. ([see it in 3D](https://tobi136b.github.io/co2-wall-sensor/assembly.html#step-5))

> **Tip:** To take the board out again, push the spring tongue back with a small screwdriver.

### Step 6 of 12: ESP32-C3 onto the sled

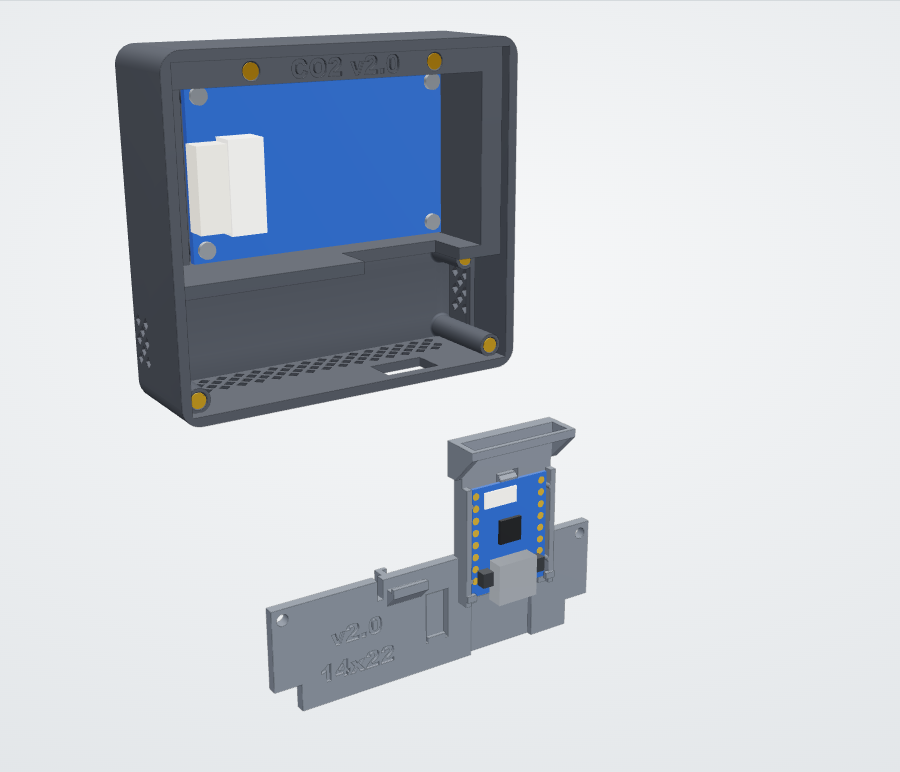
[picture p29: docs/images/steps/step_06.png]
ESP32-C3 onto the sled


**You need:** ESP32-C3 SuperMini

Chip side up, USB-C socket down. Put it on the top of the sled and slide it down between the guides until it stands on the end stops. The hook clicks behind its upper edge. ([see it in 3D](https://tobi136b.github.io/co2-wall-sensor/assembly.html#step-6))

> **Tip:** To take it out again, press the hook down with a small screwdriver and slide the board up.

### Step 7 of 12: USB-C adapter

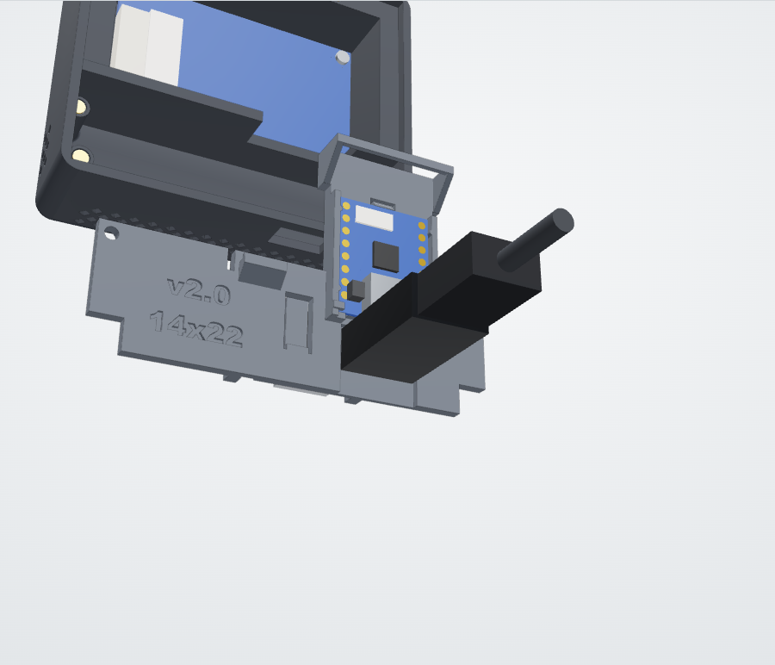
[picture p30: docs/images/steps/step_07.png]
USB-C adapter


**You need:** USB-C 90° adapter (plug to socket)

Push the adapter up into the socket of the ESP32-C3, its body points to the back. The carrier is open below the socket. Later the cable goes straight back into the wall box. ([see it in 3D](https://tobi136b.github.io/co2-wall-sensor/assembly.html#step-7))

> **Tip:** Cable on the wall instead? Leave the adapter out and later plug a straight cable in from below through the window in the bottom of the housing.

### Step 8 of 12: Carrier into the housing

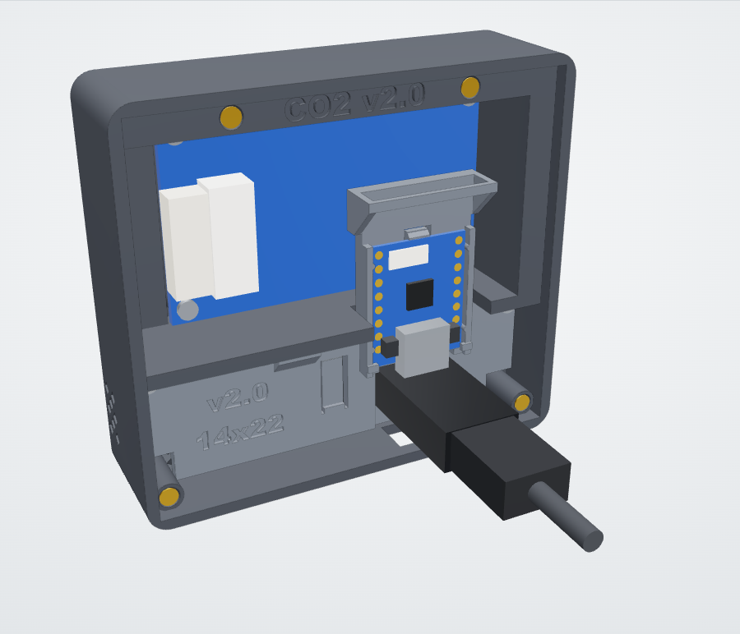
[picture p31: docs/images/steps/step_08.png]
Carrier into the housing


**You need:** 2 screws M2 × 4

Put the carrier onto the ledges in the chin, the sled slides over the display connector. Fix it with 2 screws M2 × 4. ([see it in 3D](https://tobi136b.github.io/co2-wall-sensor/assembly.html#step-8))

> **Tip:** Lay the four SCD41 wires into the narrow wire slot from its open end before, then the sensor chamber stays apart from the warm electronics without glue.

### Step 9 of 12: Wiring

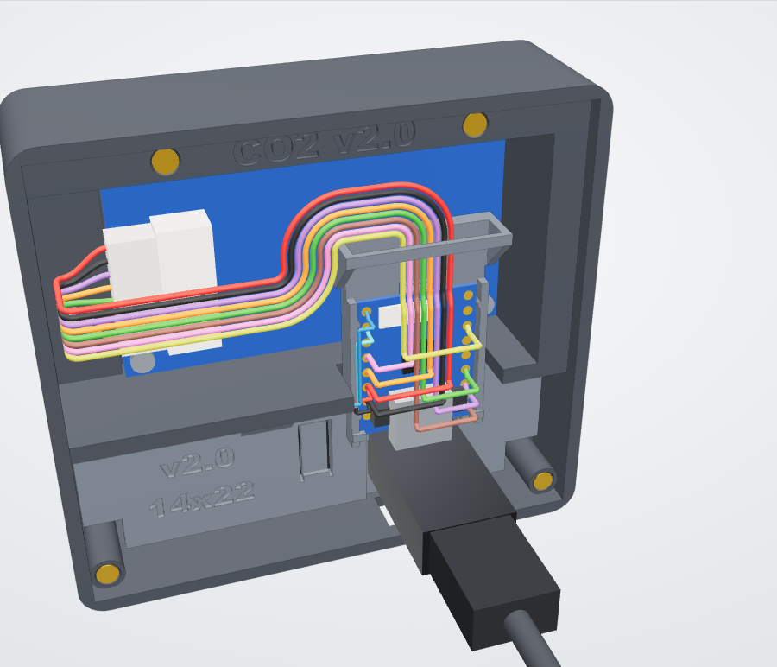
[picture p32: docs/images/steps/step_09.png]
Wiring


**You need:** The cable of the display (shortened), soldering iron, the [wiring diagram](wiring.md)

Display: the flat cable folds back at the left wall and runs across behind the display to the sled and under its bridge, every wire goes to its pad. SCD41: the 4 wires along the clip channel of the carrier and over the left guide. Colours as in the wiring diagram. ([see it in 3D](https://tobi136b.github.io/co2-wall-sensor/assembly.html#step-9))

> **Tip:** Push the cable under the bridge first and mark the length of every wire at its pad, then shorten and solder. The cable stays plugged into the display: to take the display out, just pull the plug.

### Step 10 of 12: Back cover

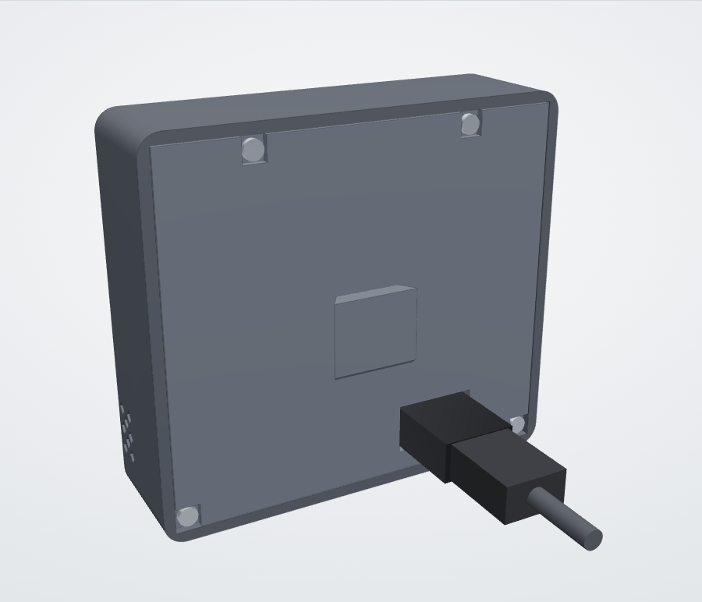
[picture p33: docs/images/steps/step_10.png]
Back cover


**You need:** Back cover, 4 screws M2 × 4

Put the cover into its seat, the adapter passes through its hole. Fix it with 4 screws M2 × 4. ([see it in 3D](https://tobi136b.github.io/co2-wall-sensor/assembly.html#step-10))

> **Tip:** Nothing may stick out of the back except the adapter: the heads sit below the surface, otherwise the device does not slide onto the wall plate.

### Step 11 of 12: Wall plate

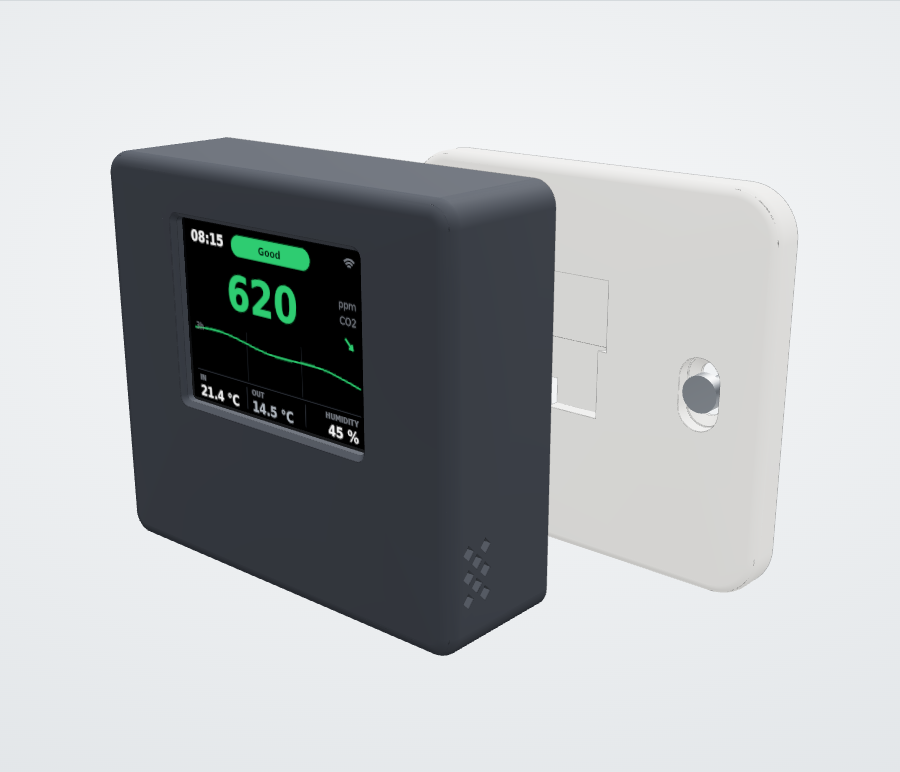
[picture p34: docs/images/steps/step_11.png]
Wall plate


**You need:** Wall plate, 2 screws M4 with 6 mm wall plugs (or the 2 screws of a flush box)

Screw the plate to the wall, label to the wall, 60 mm between the screws. The slots give 3 mm play up and down, the recesses take pan heads and countersunk heads. ([see it in 3D](https://tobi136b.github.io/co2-wall-sensor/assembly.html#step-11))

> **Tip:** Power in a flush box: a USB power module (work on 230 V only by a qualified electrician) or a USB cable in the wall. Lead the cable through the passage of the plate.

### Step 12 of 12: Slide the device on

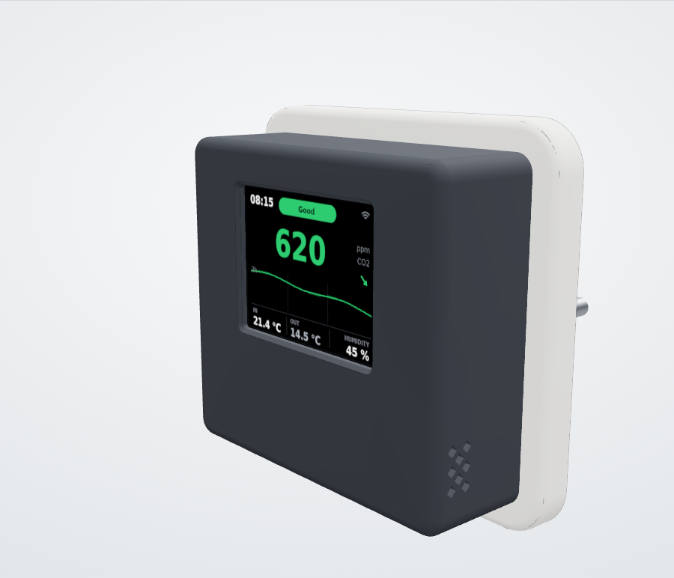
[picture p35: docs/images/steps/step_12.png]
Slide the device on


**You need:** Nothing

Hold the device in front of the plate, put the rail into the hidden window and slide it 15 mm down. Done. To remove it, slide it up and pull it off. ([see it in 3D](https://tobi136b.github.io/co2-wall-sensor/assembly.html#step-12))

> **Tip:** Plug the cable into the adapter before you put the device on the rail.

<!-- steps:end -->

## 5. Desk stand

Use the 90° adapter, the cable leaves to the back. Place the device on the rail from above and slide it down. The device leans back by 12°, a 5 mm air gap below keeps the vents free. The cable runs out through the notch at the back of the foot.

## 6. Commissioning

**The easy way:** flash the firmware from the browser on the [project page](https://tobi136b.github.io/co2-wall-sensor/), enter your WiFi in the same window and adopt the device in Home Assistant. Firmware updates then appear in Home Assistant.

**Build it yourself:**

1. Copy `esphome/secrets.yaml.example` to `esphome/secrets.yaml` and fill it in.
2. Open the ESPHome Builder in Home Assistant and add `esphome/co2-wall-sensor.yaml` (English) or `esphome/co2-wall-sensor-de.yaml` (German) together with the `common` folder.
3. Flash via USB the first time, afterwards updates go over WiFi (OTA).

**After that, in both cases:**

1. **Calibration:** put the device next to an open window for 15 minutes, then press *Calibrate SCD41 (fresh air 420 ppm)* in Home Assistant. Automatic self calibration is enabled in addition.
2. **Temperature:** after 24 hours compare with a reference thermometer and set the difference as *Temperature correction* in Home Assistant. The humidity is corrected with it.
3. **Altitude:** set *Altitude above sea level* for your place, it makes the CO2 value more exact.
4. **Night and outdoor values:** night times, dimming or switching off, the window hint and the outdoor sensor are all set in Home Assistant, see [Home Assistant](../README.md#home-assistant).

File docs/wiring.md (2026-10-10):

# Wiring

**English** | [Deutsch](de/verdrahtung.md)

Wiring diagram

All modules run on 3.3 V directly from the ESP32-C3 SuperMini. Power comes in through the USB-C socket of the ESP.

## ESP32-C3 SuperMini to Waveshare 2inch LCD (SPI)

| LCD | ESP32-C3 | Function |
|-----|---|---|
| VCC | 3V3 | 3.3 V supply |
| GND | GND | ground |
| DIN | GPIO6 | SPI MOSI |
| CLK | GPIO4 | SPI clock |
| CS  | GPIO7 | chip select |
| DC  | GPIO5 | data / command |
| RST | GPIO3 | reset |
| BL  | GPIO10 | backlight (PWM, dimmable) |

## ESP32-C3 SuperMini to SCD41 (I2C)

| SCD41 | ESP32-C3 | Function |
|---|---|---|
| VDD | 3V3 | 3.3 V supply |
| GND | GND | ground |
| SDA | GPIO0 | I2C data |
| SCL | GPIO1 | I2C clock |

## Why these pins?

* **GPIO2, GPIO8 and GPIO9** are strapping pins of the ESP32-C3 (GPIO8 also drives the blue LED, GPIO9 the BOOT button). They stay free so the board always boots cleanly.
* **GPIO18 and GPIO19** are the USB data lines and stay free as well.
* **GPIO10** is PWM capable and dims the backlight, which enables the night mode.

The diagram is generated by `python tools/wiring.py` directly from `esphome/common/base.yaml`. If you change pins in the YAML, regenerate the diagram.

## Tips

* **Display:** the supplied PH2.0 cable stays plugged into the display. It folds back at the left wall (seen from the back) and runs across behind the display to the sled and under the bridge, then every wire goes to its pad on the ESP32-C3. Lay it in first, mark the lengths at the pads, then shorten and solder. To take the display out, just pull the plug.
* **SCD41:** 4 wires AWG 30 of about 8 cm. They lie side by side in the narrow wire slot of the sensor carrier and on the back under the lip of the wire clip. No glue needed.
* Peak current of the SCD41 is about 200 mA for a few milliseconds. The 3.3 V regulator of the SuperMini handles this, keep the supply wires short.
* Test everything on the desk before building it in.

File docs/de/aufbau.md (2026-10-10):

# Druck und Aufbau

[English](../assembly.md) | **Deutsch**

Explosionsansicht

**Lieber in 3D?** Die [interaktive Aufbauanleitung](https://tobi136b.github.io/co2-wall-sensor/de/assembly.html) geht alle 12 Schritte durch. Gerät drehen, mit dem Schieberegler zerlegen, durch das Gehäuse schauen und sehen, welches Teil als Nächstes kommt.

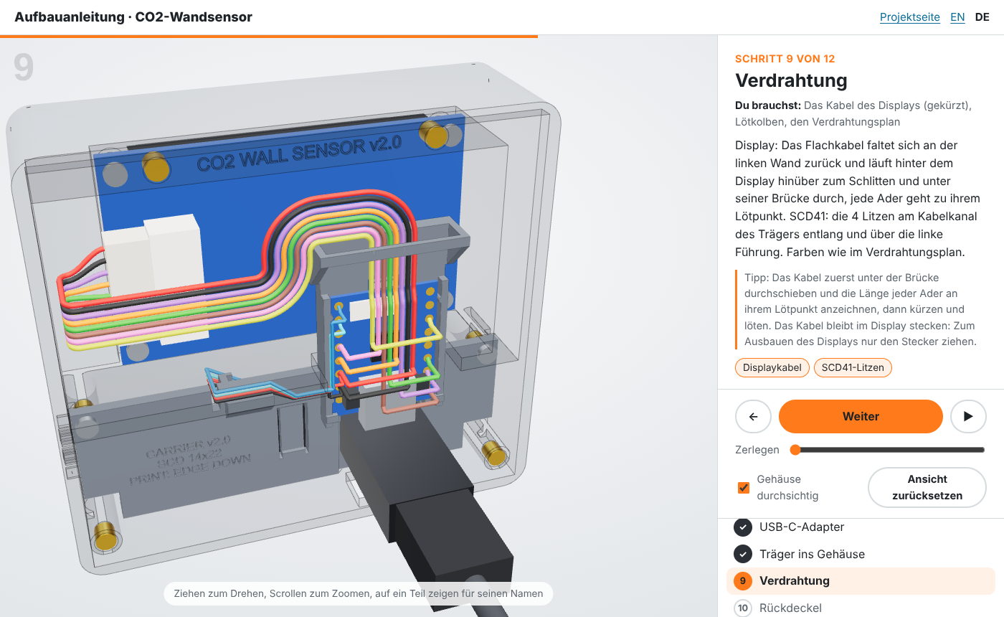
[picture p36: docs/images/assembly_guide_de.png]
3D-Aufbauanleitung


## 1. 3D-Druck

Jedes Teil trägt auf einer verdeckten Fläche die Gehäuseversion als kräftige eingeprägte Beschriftung (der Träger zusätzlich sein Sensorprofil), groß genug für eine saubere Schrift mit 0,4 mm Düse.

| Teil | Datei | Ausrichtung | Hinweise |
|---|---|---|---|
| Gehäuse | [`housing.stl`](../../cad/stl/housing.stl) | Front nach unten | Die Front liegt auf dem Druckbett (eine strukturierte PEI-Platte sieht super aus). Ein 45° Fuß an der Frontkante verhindert den Elefantenfuß. Kein Stützmaterial. |
| Sensorträger | [`sensor_carrier_14x22.stl`](../../cad/stl/sensor_carrier_14x22.stl) oder [`sensor_carrier_15x20.stl`](../../cad/stl/sensor_carrier_15x20.stl) | stehend auf der Unterkante | **Passend zu deiner SCD41-Platine**, siehe [Sensor ausmessen](sensor-ausmessen.md). Stehend gedruckt werden die Schienen zu senkrechten Kanälen, beide Federzungen wachsen nach oben und die Kabelbrücke druckt ohne Stützmaterial. 5 mm Brim verwenden. |
| Rückdeckel | [`back_cover.stl`](../../cad/stl/back_cover.stl) | Innenseite nach unten | Beschriftung "FACE DOWN". Schiene zeigt nach oben, kein Stützmaterial. Derselbe Deckel für beide Kabelausgänge. |
| Wandplatte | [`wall_plate.stl`](../../cad/stl/wall_plate.stl) | **Sichtseite nach unten** | Die Front bekommt die Oberfläche des Druckbetts. Andersherum müsste die 78 mm große Aussparung für den Dosenrand frei überbrückt werden. |
| Tischständer | [`desk_stand.stl`](../../cad/stl/desk_stand.stl) | auf der Seite | Auf der Seite gedruckt ist die Schiene am stabilsten. |

**Empfohlene Einstellungen:** PETG, 0,2 mm Schichthöhe, 3 Wände, 20 % Gyroid, Nahtposition "hinten" oder "ausgerichtet". PLA geht auch, kann aber im Sommer hinter einem sonnigen Fenster weich werden.

**Zwei Farben:** Gehäuse in Mattschwarz oder Anthrazit, Wandplatte in der Farbe der Lichtschalter (meist Reinweiß). Das Ergebnis wirkt wie ein Schaltereinsatz im Rahmen.

**Passung zu stramm oder zu locker?** Alle Schiebe- und Steckpassungen hängen an einem Wert, `FIT` (0,3 mm je Seite). In Fusion unter *Ändern > Parameter ändern* anpassen, Skript erneut starten und das betroffene Teil neu drucken. Siehe [Designnotizen](design.md#parameter-in-fusion).

## 2. Verbindungselemente: eine Schraubensorte für alles

| Anz. | Teil | Wo |
|----:|---|----|
| 10 | Einschmelzmutter **M2 × 3**, Außendurchmesser 3,0 oder 3,2 mm (Bohrung Ø 2,9 × 3,4 mm passt für beide) | 4 Display, 4 Rückdeckel, 2 Sensorträger |
| 10 | Linsenkopfschraube (Halbrundkopf) **M2 × 4**, ISO 7380, Innensechskant 1,3 mm | gleiche Stellen |
| 2 | Schraube **M4** mit 6er Dübel, Linsen- oder Senkkopf | Wandplatte |

Die Wandplatte hat 5 mm breite Langlöcher mit 3 mm Spiel nach oben und unten und einer 45°-Senkung, so liegen Linsen- und Senkköpfe unter ihrer Oberfläche. Die beiden Schrauben einer Hohlwanddose (60 mm Abstand) passen in dieselben Langlöcher. Im Gerät ist nichts geklebt.

## 3. Kabelaustritt wählen

Beide Wege gehen mit denselben gedruckten Teilen:

| Kabel | Was du brauchst | Einsatz |
|---|---|---|
| **Nach hinten** | USB-C-Winkeladapter 90° (Stecker auf Buchse) in der Buchse des ESP32-C3, darin ein beliebiges USB-C-Kabel | Hohlwanddose und **immer auf dem Tischständer** |
| **Nach unten** | gerader USB-C-Stecker, Steckerkörper höchstens 12 × 7 mm | Kabel auf Putz, Powerbank unter dem Gerät |

Kabel nach hinten Kabel nach unten

Der Adapter zeigt zur Wand und geht durch das Loch im Rückdeckel, das Kabel läuft gerade durch den Durchlass der Wandplatte in die Dose. Ein gerader Stecker sitzt im Fenster in der Bodenwand, das ihn stramm hält. Mit dem Stecker unten bleibt das Loch im Rückdeckel einfach leer, es zeigt ja zur Wand.

Das Loch ist großzügig (Adapterkörper 14 × 8 mm plus 0,6 mm Spiel). Für einen größeren Adapter `ADAPTER_W`, `ADAPTER_T` und `ADAPTER_L` in Fusion ändern, siehe [Designnotizen](design.md#parameter-in-fusion).

## 4. Schritt für Schritt

**Bevor du anfängst, leg dir bereit:** Lötkolben mit feiner Spitze, Innensechskant 1,3 mm, kleiner Schlitzschraubendreher, Seitenschneider. Alle 12 Schritte gibt es auch in der [3D-Aufbauanleitung](https://tobi136b.github.io/co2-wall-sensor/de/assembly.html), dort kannst du jeden Schritt drehen und das Gerät zerlegen.

<!-- steps:start (generated from site/assembly_steps.yaml) -->

### Schritt 1 von 12: Das Gehäuse

Das Gehäuse

**Du brauchst:** Gedrucktes Gehäuse

Mit der Front nach unten gedruckt. Du schaust von hinten darauf, auf die Seite, die später zur Wand zeigt. Rechts und links sind in dieser Anleitung immer von hinten gesehen, so wie hier. ([in 3D ansehen](https://tobi136b.github.io/co2-wall-sensor/de/assembly.html#step-1))

> **Tipp:** Kein Stützmaterial nötig. Den Rand (Brim) entfernen und prüfen, dass die vier Deckelsitze in den Ecken sauber sind.

### Schritt 2 von 12: 10 Einschmelzmuttern

10 Einschmelzmuttern

**Du brauchst:** 10 Einschmelzmuttern M2 × 3, Lötkolben auf 200 bis 220 °C

Die M2-Muttern mit dem Lötkolben eindrücken (ca. 200 bis 220 °C). 4 rund um den Displayschacht, 4 für den Rückdeckel, 2 für den Sensorträger. Die Einführschräge zentriert sie. ([in 3D ansehen](https://tobi136b.github.io/co2-wall-sensor/de/assembly.html#step-2))

> **Tipp:** Mutter auf das Loch setzen, mit dem Lötkolben antippen und unter Eigengewicht einsinken lassen, bis sie bündig ist. Nicht drücken. Hinter den 4 Displaydomen ist die Front nur 1,1 mm dick: wenig Hitze, kein Druck.

### Schritt 3 von 12: Display

Display

**Du brauchst:** Display mit eingestecktem Kabel, 4 Schrauben M2 × 4, Innensechskant 1,3 mm

Zuerst das mitgelieferte Kabel ins Display stecken. Dann mit dem Glas voran in den Displayschacht, Stecker nach links, und 4 Schrauben M2 × 4 durch die Ecklöcher. ([in 3D ansehen](https://tobi136b.github.io/co2-wall-sensor/de/assembly.html#step-3))

> **Tipp:** Es passt nur in einer Richtung: Stecker nach links, wo der Schacht länger ist. Dann steht das Bild aufrecht und der Elektronikstreifen verschwindet hinter dem Rahmen. Die Schutzfolie auf dem Glas bis zum Schluss drauflassen.

### Schritt 4 von 12: Sensorträger

Sensorträger

**Du brauchst:** Sensorträger für deine SCD41-Platine

Der Träger ist der herausnehmbare Boden der Sensorkammer und hält auf seiner Rückseite den ESP32-C3. Drucke den, der zu deiner SCD41-Platine passt, hier die Version 13,5 × 21,75 mm. ([in 3D ansehen](https://tobi136b.github.io/co2-wall-sensor/de/assembly.html#step-4))

> **Tipp:** Unsicher, welche Platine du hast? Siehe [Sensor ausmessen](sensor-ausmessen.md).

### Schritt 5 von 12: SCD41 in die Schienen

SCD41 in die Schienen

**Du brauchst:** SCD41, 4 Litzen von ca. 8 cm, Lötkolben

Zuerst vier Litzen von ca. 8 cm an die Lötpunkte löten. Dann die Platine von oben einschieben, Sensor zeigt zu dir, Lötpunkte zum Kabelschlitz, bis die Federzunge über die Oberkante schnappt. ([in 3D ansehen](https://tobi136b.github.io/co2-wall-sensor/de/assembly.html#step-5))

> **Tipp:** Zum Herausnehmen die Federzunge mit einem kleinen Schraubendreher zurückdrücken.

### Schritt 6 von 12: ESP32-C3 auf den Schlitten

ESP32-C3 auf den Schlitten

**Du brauchst:** ESP32-C3 SuperMini

Bauteile nach oben, USB-C-Buchse nach unten. Oben auf den Schlitten legen und zwischen den Führungen nach unten schieben, bis er auf den Anschlägen steht. Der Haken schnappt hinter seine Oberkante. ([in 3D ansehen](https://tobi136b.github.io/co2-wall-sensor/de/assembly.html#step-6))

> **Tipp:** Zum Herausnehmen den Haken mit einem kleinen Schraubendreher nach unten drücken und die Platine nach oben schieben.

### Schritt 7 von 12: USB-C-Adapter

USB-C-Adapter

**Du brauchst:** USB-C-Winkeladapter 90° (Stecker auf Buchse)

Den Adapter von unten in die Buchse des ESP32-C3 stecken, sein Körper zeigt nach hinten. Der Träger ist unter der Buchse offen. Später geht das Kabel gerade nach hinten in die Wanddose. ([in 3D ansehen](https://tobi136b.github.io/co2-wall-sensor/de/assembly.html#step-7))

> **Tipp:** Lieber ein Kabel auf Putz? Den Adapter weglassen und später ein gerades Kabel von unten durch das Fenster im Gehäuseboden einstecken.

### Schritt 8 von 12: Träger ins Gehäuse

Träger ins Gehäuse

**Du brauchst:** 2 Schrauben M2 × 4

Den Träger auf die Leisten im Kinn legen, der Schlitten gleitet über den Displaystecker. Mit 2 Schrauben M2 × 4 festschrauben. ([in 3D ansehen](https://tobi136b.github.io/co2-wall-sensor/de/assembly.html#step-8))

> **Tipp:** Die vier SCD41-Litzen vorher von der offenen Seite in den schmalen Kabelschlitz legen, dann bleibt die Sensorkammer ohne Kleber von der warmen Elektronik getrennt.

### Schritt 9 von 12: Verdrahtung

Verdrahtung

**Du brauchst:** Das Kabel des Displays (gekürzt), Lötkolben, den [Verdrahtungsplan](verdrahtung.md)

Display: Das Flachkabel faltet sich an der linken Wand zurück und läuft hinter dem Display hinüber zum Schlitten und unter seiner Brücke durch, jede Ader geht zu ihrem Lötpunkt. SCD41: die 4 Litzen am Kabelkanal des Trägers entlang und über die linke Führung. Farben wie im Verdrahtungsplan. ([in 3D ansehen](https://tobi136b.github.io/co2-wall-sensor/de/assembly.html#step-9))

> **Tipp:** Das Kabel zuerst unter der Brücke durchschieben und die Länge jeder Ader an ihrem Lötpunkt anzeichnen, dann kürzen und löten. Das Kabel bleibt im Display stecken: Zum Ausbauen des Displays nur den Stecker ziehen.

### Schritt 10 von 12: Rückdeckel

Rückdeckel

**Du brauchst:** Rückdeckel, 4 Schrauben M2 × 4

Den Deckel in seinen Sitz legen, der Adapter geht durch sein Loch. Mit 4 Schrauben M2 × 4 festschrauben. ([in 3D ansehen](https://tobi136b.github.io/co2-wall-sensor/de/assembly.html#step-10))

> **Tipp:** Hinten darf außer dem Adapter nichts überstehen: Die Köpfe liegen versenkt, sonst lässt sich das Gerät nicht auf die Wandplatte schieben.

### Schritt 11 von 12: Wandplatte

Wandplatte

**Du brauchst:** Wandplatte, 2 Schrauben M4 mit 6er Dübeln (oder die 2 Schrauben einer Hohlwanddose)

Die Platte an die Wand schrauben, Beschriftung zur Wand, 60 mm Abstand zwischen den Schrauben. Die Langlöcher geben 3 mm Spiel nach oben und unten, die Senkungen nehmen Linsen- und Senkköpfe. ([in 3D ansehen](https://tobi136b.github.io/co2-wall-sensor/de/assembly.html#step-11))

> **Tipp:** Strom in einer Unterputzdose: ein USB-Netzteil (Arbeiten an 230 V nur durch eine Elektrofachkraft) oder ein USB-Kabel in der Wand. Das Kabel durch den Durchlass der Platte führen.

### Schritt 12 von 12: Gerät aufsetzen

Gerät aufsetzen

**Du brauchst:** Nichts

Gerät vor die Platte halten, die Schiene in das verdeckte Fenster stecken und 15 mm nach unten schieben. Fertig. Zum Abnehmen nach oben schieben und abziehen. ([in 3D ansehen](https://tobi136b.github.io/co2-wall-sensor/de/assembly.html#step-12))

> **Tipp:** Das Kabel in den Adapter stecken, bevor du das Gerät auf die Schiene setzt.

<!-- steps:end -->

## 5. Tischständer

Den Winkeladapter verwenden, das Kabel geht nach hinten. Gerät von oben auf die Schiene setzen und nach unten schieben. Das Gerät lehnt 12° nach hinten, 5 mm Luftspalt unten halten die Lüftung frei. Das Kabel läuft durch die Kerbe hinten am Fuß hinaus.

## 6. Inbetriebnahme

**Der einfache Weg:** Firmware auf der [Projektseite](https://tobi136b.github.io/co2-wall-sensor/) direkt aus dem Browser flashen, im selben Fenster das WLAN eintragen und das Gerät in Home Assistant übernehmen. Firmware-Updates erscheinen danach in Home Assistant.

**Selbst bauen:**

1. `esphome/secrets.yaml.example` nach `esphome/secrets.yaml` kopieren und ausfüllen.
2. Im ESPHome Builder in Home Assistant `esphome/co2-wall-sensor-de.yaml` (deutsche Oberfläche) zusammen mit dem Ordner `common` anlegen.
3. Das erste Mal per USB flashen, danach kommen Updates über WLAN (OTA).

**Danach in beiden Fällen:**

1. **Kalibrierung:** Gerät 15 Minuten neben ein offenes Fenster legen, dann in Home Assistant *SCD41 kalibrieren (Frischluft 420 ppm)* drücken. Die automatische Selbstkalibrierung ist zusätzlich aktiv.
2. **Temperatur:** nach 24 Stunden mit einem Referenzthermometer vergleichen und den Unterschied in Home Assistant als *Temperaturkorrektur* eintragen. Die Luftfeuchte wird damit mitkorrigiert.
3. **Höhe:** *Höhe über dem Meer* für deinen Ort einstellen, das macht den CO2-Wert genauer.
4. **Nacht und Außenwerte:** Nachtzeit, Dimmen oder Ausschalten, Fensterhinweis und Außenfühler stellst du alles in Home Assistant ein, siehe [Home Assistant](../../README.de.md#home-assistant).

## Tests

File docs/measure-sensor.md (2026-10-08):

# Measure your SCD41 board

**English** | [Deutsch](de/sensor-ausmessen.md)

SCD41 breakout boards are sold in several sizes, and the photo in a shop often shows a different board than the one that arrives. The enclosure handles this with **one small part**: the sensor carrier. Housing, back cover, cable ports, wall plate and desk stand are the same for every board.

## 1. Compare with the known boards

Measure length and width of the bare board with a caliper.

| Board | Size | Carrier | Notes |
|---|---|---|---|
| **14x22** | 13.5 × 21.75 mm, board 1.5 mm | [`sensor_carrier_14x22.stl`](../cad/stl/sensor_carrier_14x22.stl) | Pads GND, VDD, SCL, SDA on a short edge. Lies crosswise in the carrier. The most common board in 2026. |
| **15x20** | 15 × 20 mm, board 1.6 mm | [`sensor_carrier_15x20.stl`](../cad/stl/sensor_carrier_15x20.stl) | Stands upright in the carrier. |

Deviations of a few tenths of a millimetre are fine: the **spring tongue** presses the board onto its end stop and takes up ±0.4 mm in the slide direction. If your board matches, print that carrier and you are done.

## 2. Another board: measure six values

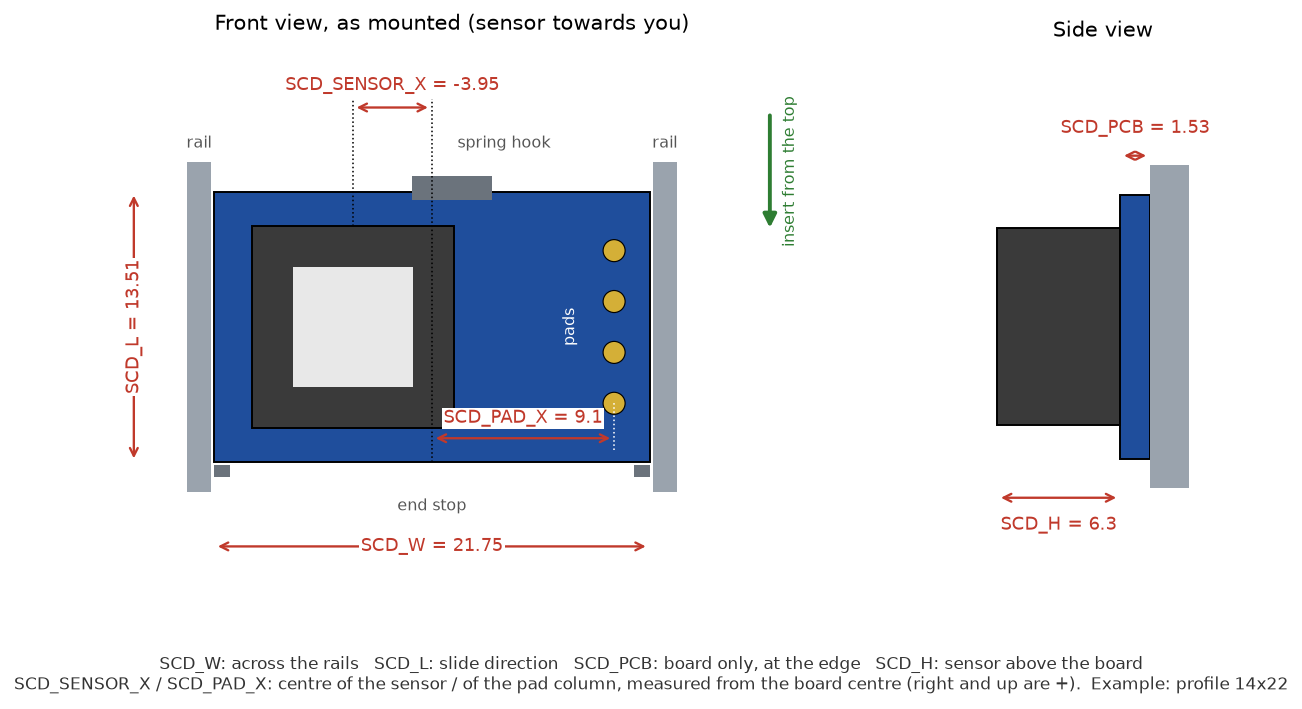
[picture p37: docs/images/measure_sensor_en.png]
Measuring sketch


Hold the board **as it will be mounted**: sensor towards you, the pads on the side where the wire slot is (top right seen from the front).

| Parameter | What to measure |
|---|---|
| `SCD_W` | Width across the rails, from edge to edge |
| `SCD_L` | Length in the slide direction |
| `SCD_PCB` | Thickness of the bare board at the edge, without components |
| `SCD_H` | Total height including the sensor minus `SCD_PCB` |
| `SCD_SENSOR_X` | Centre of the sensor from the centre of the board, right is positive |
| `SCD_PAD_X` | Centre of the pad column from the centre of the board, right is positive. `0` if the pads are not along a rail |

The chamber takes boards up to 20 mm in the slide direction and about 40 mm across, so almost every board fits one way or the other.

## 3. Create the carrier

**In the browser (easiest):** open the [sensor carrier configurator](https://tobi136b.github.io/co2-wall-sensor/configurator.html), enter the six values and download the STL. It builds the same carrier as Fusion, the CI compares both for every known board.

**In Fusion:**

1. Run the generator in Fusion once (see [Customising the enclosure](../README.md#customising-the-enclosure)).
2. Enter your six values under *Modify > Change Parameters*.
3. Run the script again with `EXPORT = True`. It writes `cad/stl/sensor_carrier_custom.stl` and checks that nothing collides.
4. Print only the carrier.

Please [open an issue](https://github.com/tobi136B/co2-wall-sensor/issues/new/choose) with your values and a photo of the board. It will be added as a profile so the next person can simply download the carrier.

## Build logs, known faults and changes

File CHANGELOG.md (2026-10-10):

# Changelog

All notable changes to this project. Format based on [Keep a Changelog](https://keepachangelog.com), versioning follows [SemVer](https://semver.org).

## [2.0.2](https://github.com/tobi136B/co2-wall-sensor/compare/v2.0.1...v2.0.2) (2026-10-10)

### Fixed

* **enclosure:** bold engraved labels that print cleanly ([#31](https://github.com/tobi136B/co2-wall-sensor/issues/31)) ([1c55805](https://github.com/tobi136B/co2-wall-sensor/commit/1c558058be6b3e5ff1c02678ae90e8c0092569f5))

## [2.0.1](https://github.com/tobi136B/co2-wall-sensor/compare/v2.0.0...v2.0.1) (2026-10-10)

### Fixed

* **enclosure:** display upright, connector on the left ([#29](https://github.com/tobi136B/co2-wall-sensor/issues/29)) ([e591637](https://github.com/tobi136B/co2-wall-sensor/commit/e591637dd768fa35e4f41f24d67eabfb728befc0))

## [2.0.0](https://github.com/tobi136B/co2-wall-sensor/compare/v1.9.0...v2.0.0) (2026-10-10)

### ⚠ BREAKING CHANGES

* **enclosure:** enclosure 2.0, the printed parts of 1.x do not fit together with the new ones. Print all parts again.

### Added

* **enclosure:** enclosure 2.0 after the first print ([#27](https://github.com/tobi136B/co2-wall-sensor/issues/27)) ([6cd6e30](https://github.com/tobi136B/co2-wall-sensor/commit/6cd6e30358b1eb852a6e26aa7ea46cfd626e1465))

## [1.9.0](https://github.com/tobi136B/co2-wall-sensor/compare/v1.8.1...v1.9.0) (2026-10-08)

### Added

* cable routing without glue, sensor carrier configurator, smarter window hint ([#25](https://github.com/tobi136B/co2-wall-sensor/issues/25)) ([0bba271](https://github.com/tobi136B/co2-wall-sensor/commit/0bba27104b0521be16eefd1cf8ddc44e6eb2b700))

## [1.8.1](https://github.com/tobi136B/co2-wall-sensor/compare/v1.8.0...v1.8.1) (2026-10-08)

### Fixed

* **cad:** measured display dimensions, enclosure version in README and releases ([#23](https://github.com/tobi136B/co2-wall-sensor/issues/23)) ([1508daf](https://github.com/tobi136B/co2-wall-sensor/commit/1508daf660b60382c9f27564ec78d0dec3c2818f))

## [1.8.0](https://github.com/tobi136B/co2-wall-sensor/compare/v1.7.2...v1.8.0) (2026-10-07)

### Added

* **firmware:** outdoor values, window hint and settings in Home Assistant ([#21](https://github.com/tobi136B/co2-wall-sensor/issues/21)) ([9c6789e](https://github.com/tobi136B/co2-wall-sensor/commit/9c6789ecc3ec2cc87e6c7034e68d26a26aef3755))

## [1.7.2](https://github.com/tobi136B/co2-wall-sensor/compare/v1.7.1...v1.7.2) (2026-10-07)

### Fixed

* shop links, prices and pictures match the current state ([#18](https://github.com/tobi136B/co2-wall-sensor/issues/18)) ([16f6d1d](https://github.com/tobi136B/co2-wall-sensor/commit/16f6d1dd997285e862691753d4c995153b6d7b4e))

## [1.7.1](https://github.com/tobi136B/co2-wall-sensor/compare/v1.7.0...v1.7.1) (2026-10-07)

### Fixed

* **cad:** measured right-angle plug and inserts of both diameters ([#16](https://github.com/tobi136B/co2-wall-sensor/issues/16)) ([be7c70b](https://github.com/tobi136B/co2-wall-sensor/commit/be7c70b7b6148175292aeee8a550067edc6a8dce))

## [1.7.0](https://github.com/tobi136B/co2-wall-sensor/compare/v1.6.0...v1.7.0) (2026-10-07)

### Added

* measured ESP32-C3 holder, collision-free assembly and new animation ([#14](https://github.com/tobi136B/co2-wall-sensor/issues/14)) ([0e9e9ed](https://github.com/tobi136B/co2-wall-sensor/commit/0e9e9ed84a7108affdd0960e28bb1d37ff0fe281))

## [1.6.0](https://github.com/tobi136B/co2-wall-sensor/compare/v1.5.0...v1.6.0) (2026-10-06)

### Added

* **firmware:** CO2 trend arrow and ventilation forecast ([#11](https://github.com/tobi136B/co2-wall-sensor/issues/11)) ([b7deac4](https://github.com/tobi136B/co2-wall-sensor/commit/b7deac44cd859aff8ef96658c97d00f933d838d5))
* interactive 3D assembly guide and new README animation ([#13](https://github.com/tobi136B/co2-wall-sensor/issues/13)) ([0c56e3d](https://github.com/tobi136B/co2-wall-sensor/commit/0c56e3df885308c8588ff31f40f612a8a9c0e9aa))

## [1.5.0](https://github.com/tobi136B/co2-wall-sensor/compare/v1.4.0...v1.5.0) (2026-10-06)

### Added

* **cad:** printability for 0.4 mm nozzles and diamond vent mesh ([#9](https://github.com/tobi136B/co2-wall-sensor/issues/9)) ([80bae21](https://github.com/tobi136B/co2-wall-sensor/commit/80bae21d80c4b81d086d13308233caf516e13bbc))

### Documentation

* room size and placement of the sensor ([8ed4240](https://github.com/tobi136B/co2-wall-sensor/commit/8ed4240ff7e65f8ec842e42d2965d60d6d796678))

## [1.4.0](https://github.com/tobi136B/co2-wall-sensor/compare/v1.3.0...v1.4.0) (2026-10-05)

### Added

* **cad:** sensor carrier profiles for different SCD41 boards with spring tongue ([4884566](https://github.com/tobi136B/co2-wall-sensor/commit/4884566fa0200700a9ffd2bd03d331de52491c9b)), closes [#7](https://github.com/tobi136B/co2-wall-sensor/issues/7)
* generate shop link tables from hardware/bom.csv ([27f08ae](https://github.com/tobi136B/co2-wall-sensor/commit/27f08ae2e01583154e715adda9edb1a230080099))
* readable bill of materials in hardware/bom.yaml ([4d5691e](https://github.com/tobi136B/co2-wall-sensor/commit/4d5691edf74087e0b451b58f861e5ddc2cf3e3b5))

### Documentation

* add sensor carrier profiles and online configurator to the roadmap ([f5e4023](https://github.com/tobi136B/co2-wall-sensor/commit/f5e4023f99dcf99ea56c6cae3dcb68d4f661ada3))

## [1.3.0] - 2026-10-05

### Added
* **Cable port modules:** a small swappable part at the lower back edge decides the cable exit. `PortBack` for a right-angle plug (the plug body is caught behind the module, strain relief), `PortBottom` for a straight plug. Print both, swap with four screws.
* **SCD41 slides into rails** with end stop and snap bump on the sensor carrier, sized for the common 15 × 20 mm breakout.
* **ESP32-C3 is held by guides, end stops and a short groove**, nothing in the device is glued any more.
* **Optional lock tab** ties the device to the wall plate with two more M2 screws.
* **All dimensions are Fusion user parameters** (*Modify > Change Parameters*); the script takes them over when it runs again.
* Slider joint in the assembly: the device can be pushed up the rail in Fusion.
* Engraved labels with part name, version and print orientation.
* 45° foot on all rounded bed edges, entry chamfers on insert holes, fillets at boss roots, lead-in chamfer on the rail.
* Renders of cable ports, sensor carrier and lock tab.

### Changed
* Device depth 24 mm (was 22) to fit a straight USB-C overmould and to give the SCD41 1.4 mm of air in front of its opening.
* Wall plate is printed front face down (no 78 mm bridge on the wall side any more).
* Sensor carrier is printed standing on its lower edge.
* One fit value `FIT` for all sliding and plugged fits.

### Removed
* Knock-out membranes of v1.2, replaced by the cable port modules.

## [1.2.0] - 2026-10-04

### Added
* **Sensor carrier:** removable, screwed floor of the sensor chamber. Carries the SCD41 on the front and the ESP32-C3 on the back, so the sensor is easy to mount and to replace.
* **Selectable cable exit:** two flush knock-outs (0.6 mm), back cover for a right-angle plug, bottom wall for a straight plug. Decide after printing.
* Renders of the interior and the back view.
* Fastener summary on the technical drawing.

### Changed
* **One fastener type for everything:** 10 heat-set inserts M2 × 3 (OD 3.2) and 10 button head screws M2 × 4, ISO 7380. Display, back cover (4 points) and sensor carrier are all screwed into inserts. M3 inserts, countersunk screws and self-tapping plastic screws are gone.
* Back cover without hooks or pins: four counterbored screws, prints flat without supports.
* ESP32-C3 turned by 180°, USB-C socket now points down with 13 mm of space for the plug.
* Device grows to 69.8 × 69.8 × 22 mm to make room for the insert bosses (wall plate stays 82 × 82 mm).
* Firmware: WiFi transmit power limited to 8.5 dB, a known fix for unstable ESP32-C3 SuperMini boards.
* Drawing, assembly guide, design notes, FAQ and bill of materials updated in English and German.

## [1.1.0] - 2026-10-04

### Added
* English as primary language with full German translation (README, docs, firmware, drawing, wiring diagram).
* Firmware split into `common/base.yaml` plus device files for English and German.
* Display preview generator and rendered previews of all three air quality states.
* Exploded view and coloured renders.
* Design notes, FAQ, machine-readable bill of materials.
* GitHub Actions: firmware compile for both languages, tool checks, release builds with firmware and print files.
* Issue and pull request templates, contributing guide.
* Fusion generator can export STL and STEP directly (`EXPORT = True`).

### Changed
* CAD generator rewritten with English identifiers and component names; file names of STL and STEP are English now.
* Secrets use English keys (`wifi_ssid`, `wifi_password`, `api_encryption_key`, ...).

## [1.0.0] - 2026-10-04

### Added
* First release: compact 66.8 × 66.8 × 20 mm enclosure with dovetail rail.
* Wall plate for German flush wall boxes and desk stand with 12° tilt.
* ESPHome firmware for ESP32-C3 SuperMini, SCD41 and Waveshare 2inch LCD.

---

**Deutsch:** Die Änderungshistorie wird auf Englisch geführt. Kurz zusammengefasst: 1.3.0 bringt tauschbare Kabelport-Module (Kabel hinten oder unten), Schienen für den SCD41, eine optionale Sicherungslasche, alle Maße als Fusion-Parameter und viele Details für einen sauberen Druck; im Gerät ist nichts mehr geklebt. 1.2.0 verschraubt alles mit nur einer Schraubensorte (10 Einschmelzmuttern M2 × 3 und 10 Linsenkopfschrauben M2 × 4), bringt den verschraubten Sensorträger und lässt den Kabelaustritt nach dem Druck wählen (unten oder hinten). 1.1.0 brachte die vollständige Zweisprachigkeit, eine aufgeteilte Firmware, CI mit Firmware-Builds, Displayvorschau und Explosionsansicht.

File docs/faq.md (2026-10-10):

# FAQ

**English** | [Deutsch](de/faq.md)

### How accurate is the CO2 reading?
The SCD41 is specified for ±(50 ppm + 5 % of reading) between 400 and 5000 ppm. Automatic self calibration assumes the device sees fresh air (about 420 ppm) at least once a week, which is normal in ventilated rooms. If the room is never aired properly, disable `automatic_self_calibration` and use the calibration button instead.

### How large a room can one sensor monitor?
**One sensor per room.** CO2 spreads evenly within a room in a few minutes, but walls and closed doors separate the air, so a sensor in the living room says little about the bedroom.

The size of the room is rarely the limit. Building guidelines put one sensor per 500 m² of open floor space ([Arc/GBCI](https://arc.gbci.org/sites/default/files/Arc-CO2Guide.pdf)), the sensor manufacturer BAPI gives at most 725 m² in still air ([BAPI](https://www.bapihvac.com/application_note/air-quality-sensor-coverage-area-and-mounting/)). Every living room, bedroom, office or classroom is therefore covered by one device; only open spaces with several zones need more.

Placement matters more than size:
* **Height 1 to 1.5 m**, the breathing zone of seated people. The wall plate on a flush box at switch height (about 1.05 m) is ideal.
* **At least 1 to 2 m away from people**, so nobody breathes directly at the sensor (not right beside the bed or the desk).
* **Not next to windows, doors, radiators or ventilation outlets**, and not in direct sunlight.

### What is the window in the bottom of the housing for?
It takes a straight USB-C plug when the cable runs down the wall. With the 90° adapter and the cable to the back it stays empty; it lies next to the vent mesh and is only visible from below. See [assembly](assembly.md#3-choose-the-cable-exit).

### Which thresholds are sensible?
The defaults are 1000 ppm (yellow) and 1400 ppm (red). Values below 1000 ppm are generally considered harmless, above 2000 ppm ventilation is clearly needed. Both thresholds can be changed in Home Assistant at any time.

### The temperature reads too high.
Compare with a reference thermometer after 24 hours and adjust `temperature_offset` in the device file. Make sure all four SCD41 wires lie side by side in the wire slot, so it seals the sensor chamber against the ESP bay.

### Can I use a different ESP32 board?
Yes. Any ESP32 supported by ESPHome works, but you must adjust the pins in `esphome/common/base.yaml` and the bay for the board in the generator. The ESP32-C3 SuperMini was chosen for its size, native USB-C and low heat.

### Can I use a different display?
Any ST7789 based 240 × 320 SPI display works with small changes. Different outer dimensions require new values for `LCD_W`, `LCD_H`, `GLASS_*`, `ACTIVE_*` and `LCD_HOLE_*` in the generator.

### Can it run on batteries?
Not in a useful way. The colour display needs constant power. For a battery device an e-paper display and deep sleep would be required, which is a different design.

### Wall plugs or flush wall box?
Both. The wall plate takes two M4 screws with 6 mm wall plugs, 60 mm apart, or the two horizontal screws of a German flush wall box. The slots give 3 mm play up and down. If your box only has vertical screw positions, use wall plugs.

### Browser installer or my own build?
Both are first class. The **browser installer** on the [project page](https://tobi136b.github.io/co2-wall-sensor/) flashes a ready firmware without any WiFi credentials inside. After flashing you enter your WiFi in the same browser window (or via the hotspot "CO2 Wall Sensor" that the device opens when it has no WiFi), Home Assistant discovers it, and new releases appear as firmware updates in Home Assistant. If you want to change the configuration, click "Adopt" in the ESPHome dashboard: it pulls the matching YAML from this repository. The **own build** with your `secrets.yaml` gives you API encryption and full control from the start.

### Does the device phone home?
No. The firmware only checks the release manifest on the project page for updates, and only if you look at the update entity or once per day. Measurements never leave your network.

### Which inserts and screws exactly?
Generic M2 × 3 heat-set inserts with 3.0 or 3.2 mm outer diameter (the common "M2 x 3 x 3" or "M2 x 3 x 3.2" packs) and M2 × 4 button head screws ISO 7380, 10 of each. Inserts with a different size work if you change `INSERT_HOLE_D` and `INSERT_HOLE_L`.

### Cable from below or from the back?
Both, with the same printed parts. To the back: a 90° USB-C adapter (plug to socket) in the ESP32-C3, the cable goes straight into the flush wall box; always use it on the desk stand. To the bottom: a straight cable through the window in the bottom. See [assembly](assembly.md#3-choose-the-cable-exit).

### My straight USB-C plug does not fit.
The window in the bottom takes plugs with an overmould of up to 12 × 7 mm. For bulkier plugs change `PLUG_W` and `PLUG_H` (the device gets deeper if `PLUG_H` grows) or lead the cable to the back with the 90° adapter.

### The picture on the display is upside down.
Switch on *Display upside down* in Home Assistant, the picture turns by 180° at once. The housing decides how the display sits: its connector is on the left, seen from the back, and the picture stands upright. The switch is only a fallback.

### My SCD41 board looks different.
Measure it and compare it with the known profiles. Only the small sensor carrier depends on the board, everything else stays the same. See [measure your sensor](measure-sensor.md).

### My ESP32-C3 SuperMini is a little different.
The holder is designed for boards from other batches. The board lies on a sled over its whole length, crush ribs in the side guides centre it, the guides take boards up to 1.2 mm thick, and a spring hook clicks behind its upper edge. Measured board: 18.2 × 22.71 × 0.74 mm, USB-C socket 9.0 mm wide, 3.5 mm high, 1.5 mm over the lower edge.

| Dimension | fits without a new print |
|---|---|
| Width | 18.0 to 18.6 mm |
| Thickness | up to 1.2 mm |
| Length | 22.0 to 22.8 mm (a shorter board has some play) |
| USB-C socket over the lower edge | 0.5 to 2.5 mm |

Outside these ranges change `C3_W`, `C3_H`, `C3_PCB` or `C3_USB_OUT` in the generator and print a new sensor carrier.

### How do I change a dimension?
Open the generated design in Fusion, go to *Modify > Change Parameters*, change the value and run the script again. It takes over all parameters of the open design, rebuilds every part and checks for interference. With `EXPORT = True` it also writes new STL and STEP files. See [design notes](design.md#parameters-in-fusion).

### Why are the drawing and images generated?
Because they then always match the model. Change a parameter, run the tools, commit. The CI regenerates them, checks that the print files belong to the current parameters and that all links in the documentation work.

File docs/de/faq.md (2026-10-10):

# FAQ

[English](../faq.md) | **Deutsch**

### Wie genau ist der CO2-Wert?
Der SCD41 ist mit ±(50 ppm + 5 % vom Messwert) zwischen 400 und 5000 ppm spezifiziert. Die automatische Selbstkalibrierung geht davon aus, dass das Gerät mindestens einmal pro Woche Frischluft (ca. 420 ppm) sieht, was in gelüfteten Räumen normal ist. Wird der Raum nie richtig gelüftet, `automatic_self_calibration` abschalten und stattdessen die Kalibriertaste nutzen.

### Wie groß darf der Raum für einen Sensor sein?
**Ein Sensor pro Raum.** CO2 verteilt sich innerhalb eines Raumes in wenigen Minuten gleichmäßig, aber Wände und geschlossene Türen trennen die Luft. Ein Sensor im Wohnzimmer sagt also wenig über das Schlafzimmer.

Die Raumgröße ist selten die Grenze. Richtlinien für Gebäude rechnen mit einem Sensor pro 500 m² offener Fläche ([Arc/GBCI](https://arc.gbci.org/sites/default/files/Arc-CO2Guide.pdf)), der Sensorhersteller BAPI nennt höchstens 725 m² bei ruhiger Luft ([BAPI](https://www.bapihvac.com/application_note/air-quality-sensor-coverage-area-and-mounting/)). Jedes Wohnzimmer, Schlafzimmer, Büro oder Klassenzimmer deckt ein Gerät also ab; nur große offene Flächen mit mehreren Zonen brauchen mehr.

Wichtiger als die Größe ist der Platz:
* **Höhe 1 bis 1,5 m**, also im Atembereich sitzender Personen. Die Wandplatte auf einer Hohlwanddose in Schalterhöhe (ca. 1,05 m) ist ideal.
* **Mindestens 1 bis 2 m Abstand zu Personen**, damit niemand den Sensor direkt anatmet (nicht direkt neben Bett oder Schreibtisch).
* **Nicht neben Fenster, Tür, Heizkörper oder Lüftungsauslass** und nicht in direkte Sonne.

### Wofür ist das Fenster unten im Gehäuse?
Dort sitzt ein gerader USB-C-Stecker, wenn das Kabel auf Putz nach unten läuft. Mit dem Winkeladapter und dem Kabel nach hinten bleibt es leer; es liegt neben dem Lüftungsgitter und ist nur von unten sichtbar. Siehe [Aufbau](aufbau.md#3-kabelaustritt-wählen).

### Welche Schwellen sind sinnvoll?
Standard sind 1000 ppm (Gelb) und 1400 ppm (Rot). Werte unter 1000 ppm gelten allgemein als unbedenklich, über 2000 ppm sollte dringend gelüftet werden. Beide Schwellen lassen sich jederzeit in Home Assistant ändern.

### Die Temperatur ist zu hoch.
Nach 24 Stunden mit einem Referenzthermometer vergleichen und `temperature_offset` in der Gerätedatei anpassen. Prüfen, ob alle vier SCD41-Litzen nebeneinander im Kabelschlitz liegen, damit er zwischen ESP-Bereich und Sensorkammer dicht ist.

### Kann ich ein anderes ESP32-Board nehmen?
Ja. Jeder von ESPHome unterstützte ESP32 funktioniert, aber die Pins in `esphome/common/base.yaml` und die Aufnahme im Generator müssen angepasst werden. Der ESP32-C3 SuperMini wurde wegen Größe, USB-C und geringer Abwärme gewählt.

### Kann ich ein anderes Display nehmen?
Jedes ST7789-Display mit 240 × 320 und SPI funktioniert mit kleinen Änderungen. Andere Außenmaße brauchen neue Werte für `LCD_W`, `LCD_H`, `GLASS_*`, `ACTIVE_*` und `LCD_HOLE_*` im Generator.

### Geht Batteriebetrieb?
Nicht sinnvoll. Das Farbdisplay braucht dauerhaft Strom. Ein Akkugerät bräuchte E-Paper und Tiefschlaf, das wäre ein anderes Design.

### Dübel oder Hohlwanddose?
Beides. Die Wandplatte nimmt zwei Schrauben M4 mit 6er Dübeln im Abstand von 60 mm oder die beiden waagrechten Geräteschrauben einer Hohlwanddose. Die Langlöcher geben 3 mm Spiel nach oben und unten. Hat deine Dose nur senkrechte Schraubpositionen, nimm Dübel.

### Browser-Installer oder selbst bauen?
Beides ist vollwertig. Der **Browser-Installer** auf der [Projektseite](https://tobi136b.github.io/co2-wall-sensor/) flasht eine fertige Firmware, in der keine WLAN-Zugangsdaten stecken. Nach dem Flashen trägst du dein WLAN im selben Browserfenster ein (oder über den Hotspot "CO2 Wall Sensor", den das Gerät ohne WLAN öffnet), Home Assistant findet das Gerät, und neue Releases erscheinen in Home Assistant als Firmware-Update. Wer die Konfiguration ändern will, klickt im ESPHome Dashboard auf "Übernehmen": Es holt die passende YAML aus diesem Repository. Der **eigene Build** mit deiner `secrets.yaml` bringt von Anfang an API-Verschlüsselung und volle Kontrolle.

### Telefoniert das Gerät nach Hause?
Nein. Die Firmware prüft nur das Release-Manifest auf der Projektseite auf Updates, und zwar nur, wenn du die Update-Entität aufrufst, oder einmal am Tag. Messwerte verlassen dein Netzwerk nie.

### Welche Einschmelzmuttern und Schrauben genau?
Handelsübliche Einschmelzmuttern M2 × 3 mit 3,0 oder 3,2 mm Außendurchmesser (die verbreiteten Packungen „M2 x 3 x 3“ oder „M2 x 3 x 3,2“) und Linsenkopfschrauben M2 × 4 nach ISO 7380, je 10 Stück. Muttern in anderer Größe gehen, wenn `INSERT_HOLE_D` und `INSERT_HOLE_L` angepasst werden.

### Kabel von unten oder von hinten?
Beides, mit denselben gedruckten Teilen. Nach hinten: ein USB-C-Winkeladapter 90° (Stecker auf Buchse) im ESP32-C3, das Kabel geht gerade in die Hohlwanddose; auf dem Tischständer immer so. Nach unten: ein gerades Kabel durch das Fenster im Boden. Siehe [Aufbau](aufbau.md#3-kabelaustritt-wählen).

### Mein gerader USB-C-Stecker passt nicht.
Das Fenster im Boden nimmt Stecker mit einem Steckerkörper bis 12 × 7 mm. Für dickere Stecker `PLUG_W` und `PLUG_H` anpassen (wird `PLUG_H` größer, wird das Gerät tiefer) oder das Kabel mit dem Winkeladapter nach hinten führen.

### Das Bild auf dem Display steht auf dem Kopf.
In Home Assistant *Display auf dem Kopf* einschalten, das Bild dreht sich sofort um 180°. Wie das Display sitzt, gibt das Gehäuse vor: Sein Stecker ist links, von hinten gesehen, und das Bild steht aufrecht. Der Schalter ist nur eine Reserve.

### Meine SCD41-Platine sieht anders aus.
Ausmessen und mit den bekannten Profilen vergleichen. Nur der kleine Sensorträger hängt von der Platine ab, alles andere bleibt gleich. Siehe [Sensor ausmessen](sensor-ausmessen.md).

### Mein ESP32-C3 SuperMini ist etwas anders.
Der Halter ist für Platinen aus anderen Lieferungen ausgelegt. Die Platine liegt auf ganzer Länge auf einem Schlitten, Quetschrippen in den Seitenführungen zentrieren sie, die Führungen nehmen Platinen bis 1,2 mm Dicke, und ein Federhaken schnappt hinter ihre Oberkante. Gemessene Platine: 18,2 × 22,71 × 0,74 mm, USB-C-Buchse 9,0 mm breit, 3,5 mm hoch, 1,5 mm über der Unterkante.

| Maß | passt ohne neuen Druck |
|-----|---|
| Breite | 18,0 bis 18,6 mm |
| Dicke | bis 1,2 mm |
| Länge | 22,0 bis 22,8 mm (eine kürzere Platine hat etwas Spiel) |
| Überstand der USB-C-Buchse | 0,5 bis 2,5 mm |

Außerhalb davon `C3_W`, `C3_H`, `C3_PCB` oder `C3_USB_OUT` im Generator ändern und einen neuen Sensorträger drucken.

### Wie ändere ich ein Maß?
Die erzeugte Konstruktion in Fusion öffnen, *Ändern > Parameter ändern*, Wert anpassen und das Skript erneut starten. Es übernimmt alle Parameter der offenen Konstruktion, baut alle Teile neu und prüft auf Kollisionen. Mit `EXPORT = True` schreibt es auch neue STL- und STEP-Dateien. Siehe [Designnotizen](design.md#parameter-in-fusion).

### Warum werden Zeichnung und Bilder generiert?
Damit sie immer zum Modell passen. Parameter ändern, Tools starten, committen. Die CI erzeugt sie neu, prüft, ob die Druckdateien zu den aktuellen Parametern gehören und ob alle Links in der Doku funktionieren.

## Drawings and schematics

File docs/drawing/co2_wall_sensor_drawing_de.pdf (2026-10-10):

## Detail Schiene (2:1)

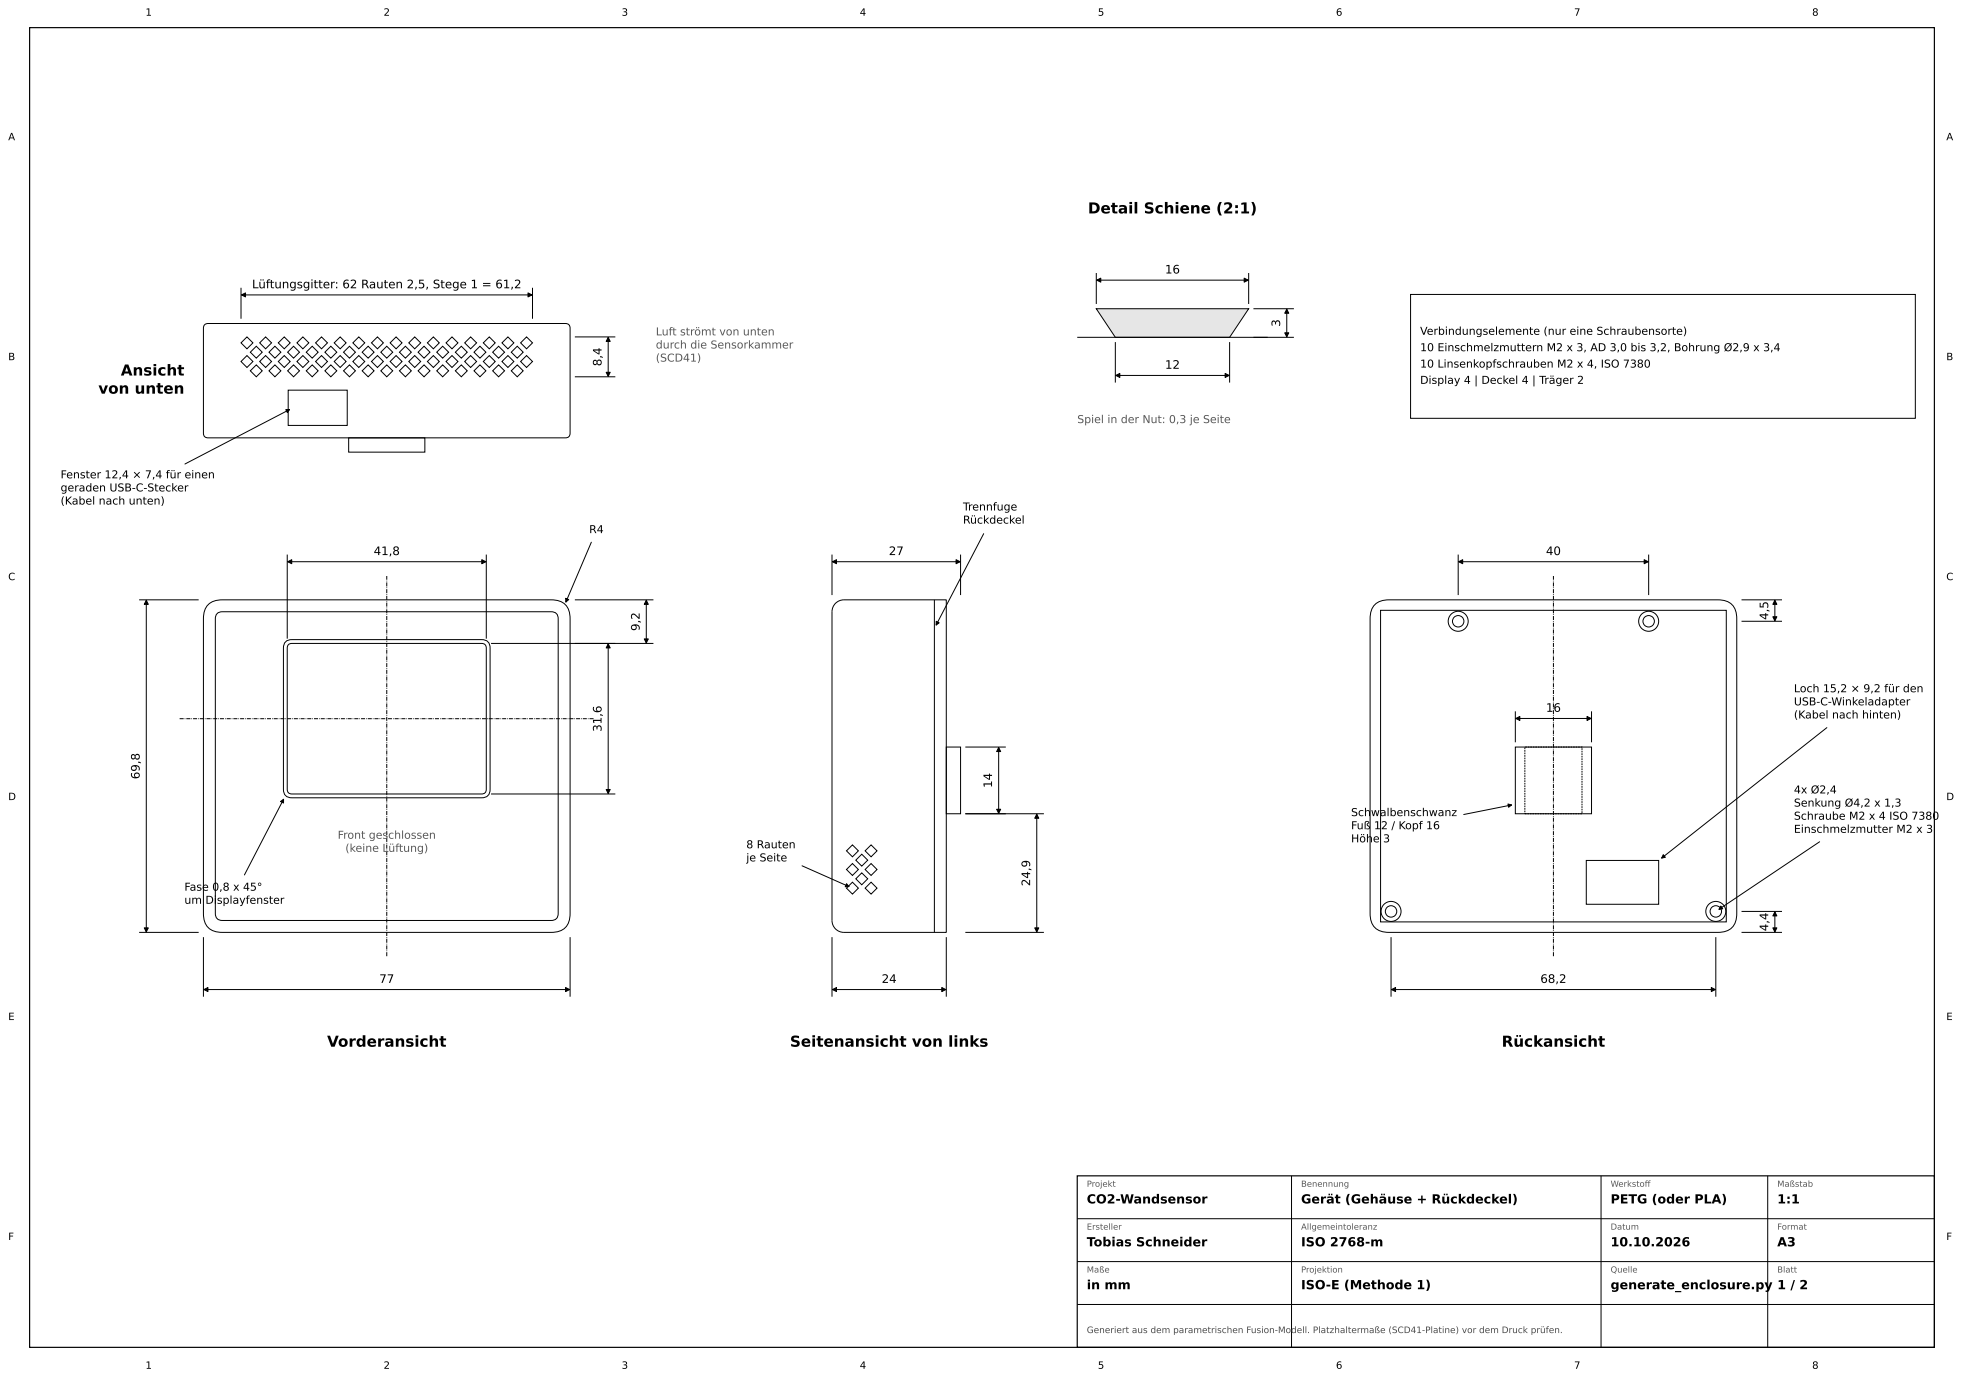
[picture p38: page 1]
Projekt CO2-Wandsensor; Maßstab 1:1; Ersteller Tobias Schneider; Allgemeintoleranz ISO 2768-m; Datum 10.10.2026; Format A3; Maße in mm; Projektion ISO-E (Methode 1); Quelle generate_enclosure.py; Blatt 1 / 2; Vorderansicht; Fase 0,8 x 45° um Displayfenster; Front geschlossen (keine Lüftung); 8 Rauten je Seite; Trennfuge Rückdeckel; Ansicht von unten; Rückansicht; 4x Ø2,4 Senkung Ø4,2 x 1,3 Schraube M2 x 4 ISO 7380 Einschmelzmutter M2 x 3; Schwalbenschwanz Fuß 12 / Kopf 16 Höhe 3

Lüftungsgitter: 62 Rauten 2,5, Stege 1 = 61,2

Luft strömt von unten
durch die Sensorkammer
(SCD41)

Verbindungselemente (nur eine Schraubensorte)
10 Einschmelzmuttern M2 x 3, AD 3,0 bis 3,2, Bohrung Ø2,9 x 3,4
10 Linsenkopfschrauben M2 x 4, ISO 7380
Display 4 | Deckel 4 | Träger 2

Spiel in der Nut: 0,3 je Seite

Fenster 12,4 × 7,4 für einen
geraden USB-C-Stecker
(Kabel nach unten)

Loch 15,2 × 9,2 für den
USB-C-Winkeladapter
(Kabel nach hinten)

Seitenansicht von links

Benennung
Gerät (Gehäuse + Rückdeckel)

Werkstoff
PETG (oder PLA)

Generiert aus dem parametrischen Fusion-Modell. Platzhaltermaße (SCD41-Platine) vor dem Druck prüfen.

## Wandplatte, Vorderansicht

A

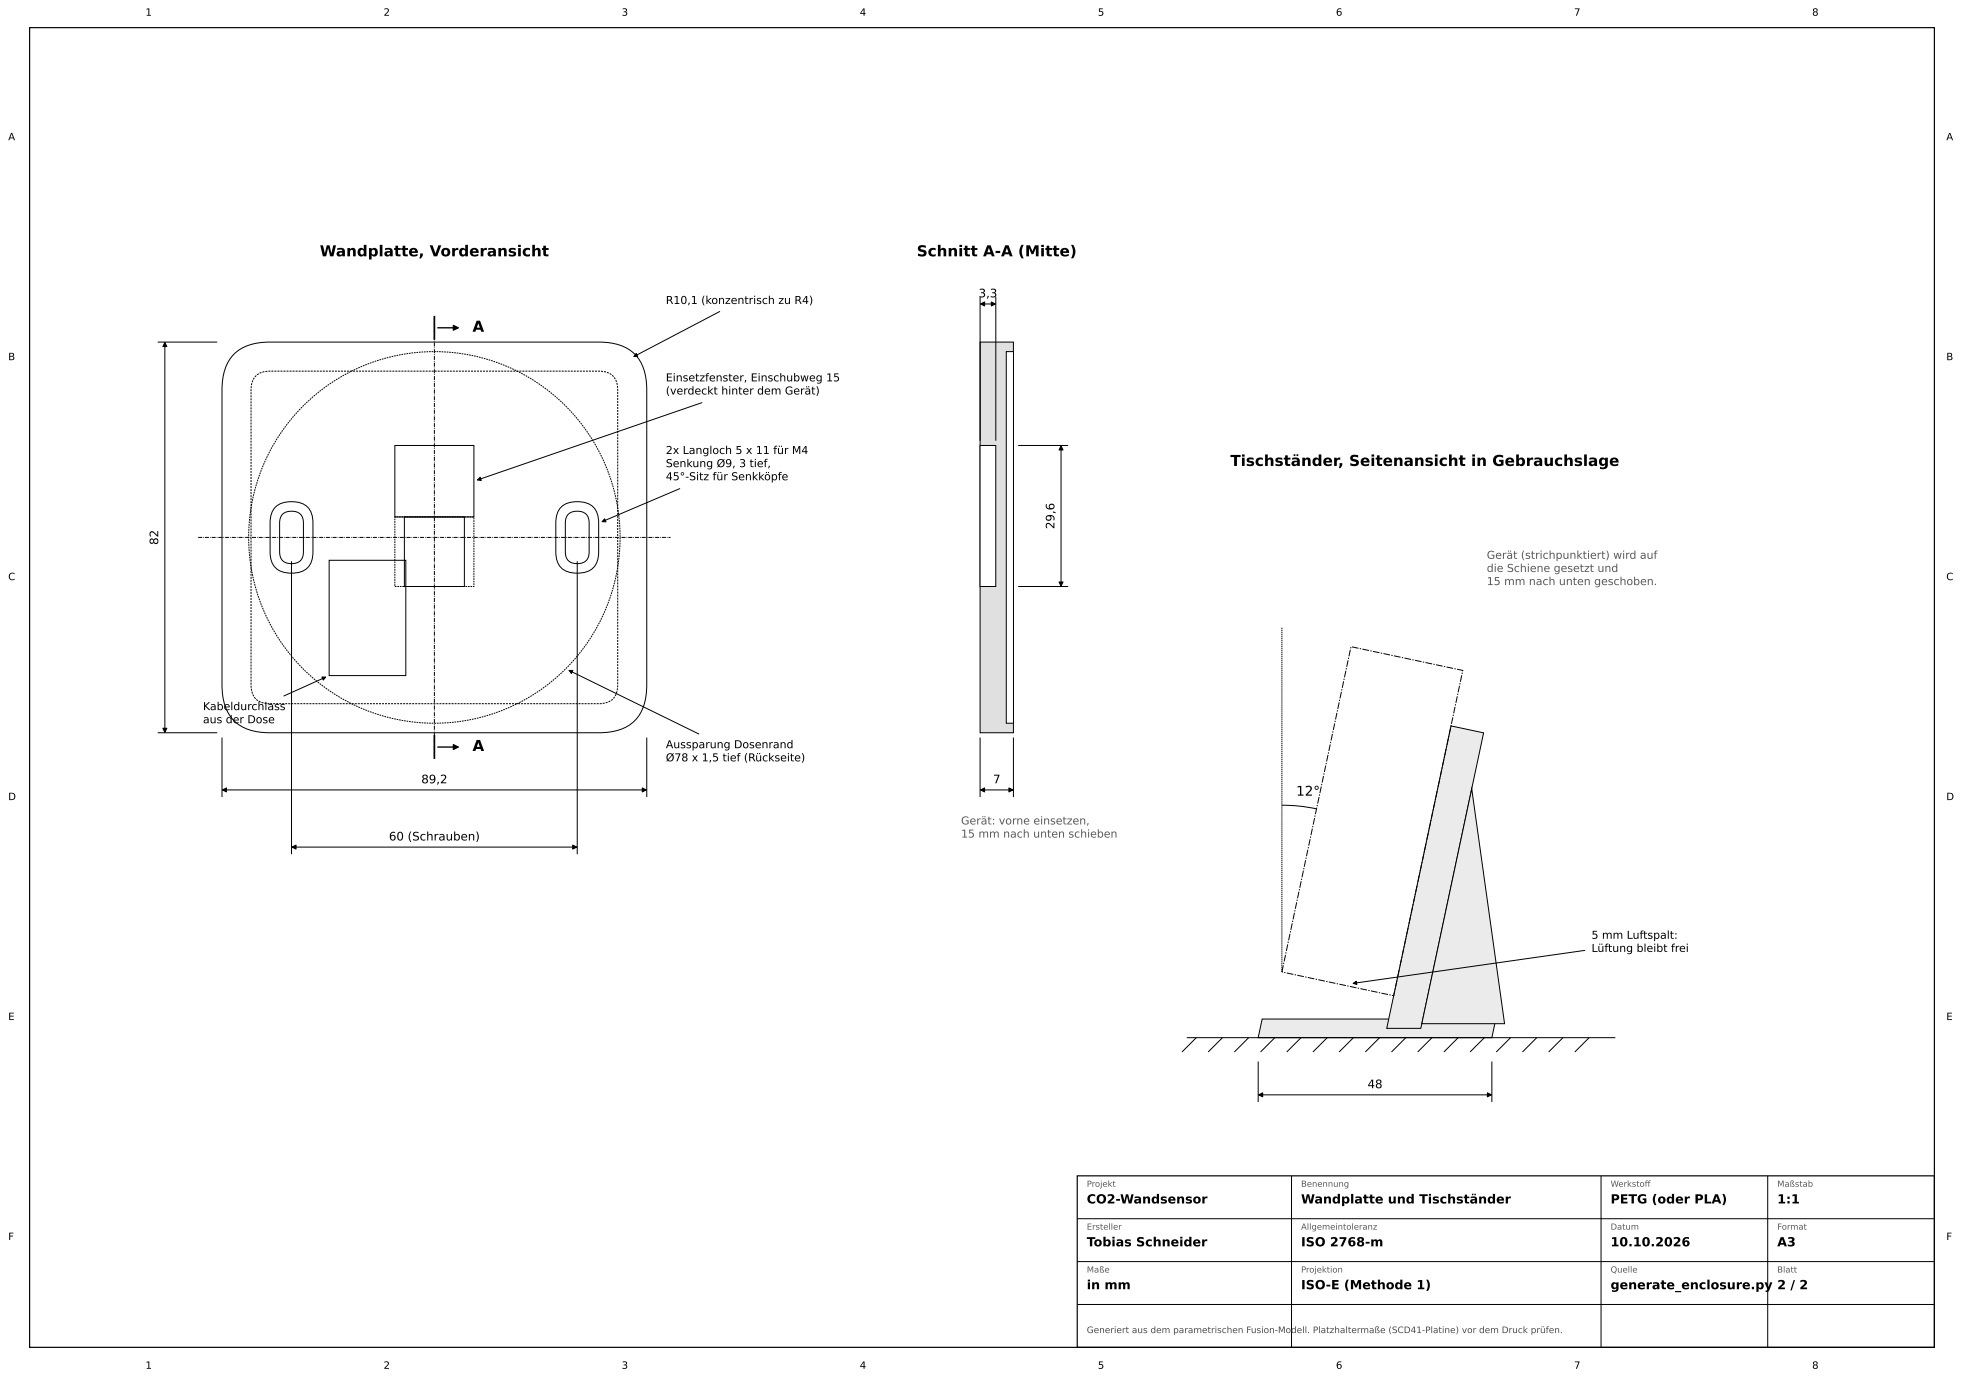
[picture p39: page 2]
Projekt CO2-Wandsensor; Maßstab 1:1; Ersteller Tobias Schneider; Allgemeintoleranz ISO 2768-m; Datum 10.10.2026; Format A3; Maße in mm; Projektion ISO-E (Methode 1); Quelle generate_enclosure.py; Blatt 2 / 2; 60 (Schrauben); R10,1 (konzentrisch zu R4); Aussparung Dosenrand Ø78 x 1,5 tief (Rückseite); Schnitt A-A (Mitte)

Einsetzfenster, Einschubweg 15
(verdeckt hinter dem Gerät)

2x Langloch 5 x 11 für M4
Senkung Ø9, 3 tief,
45°-Sitz für Senkköpfe

Tischständer, Seitenansicht in Gebrauchslage

Gerät (strichpunktiert) wird auf
die Schiene gesetzt und
15 mm nach unten geschoben.

Kabeldurchlass
aus der Dose

Gerät: vorne einsetzen,
15 mm nach unten schieben

5 mm Luftspalt:
Lüftung bleibt frei

Benennung
Wandplatte und Tischständer

Werkstoff
PETG (oder PLA)

Generiert aus dem parametrischen Fusion-Modell. Platzhaltermaße (SCD41-Platine) vor dem Druck prüfen.

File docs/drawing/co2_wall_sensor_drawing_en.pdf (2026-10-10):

## Detail rail (2:1)

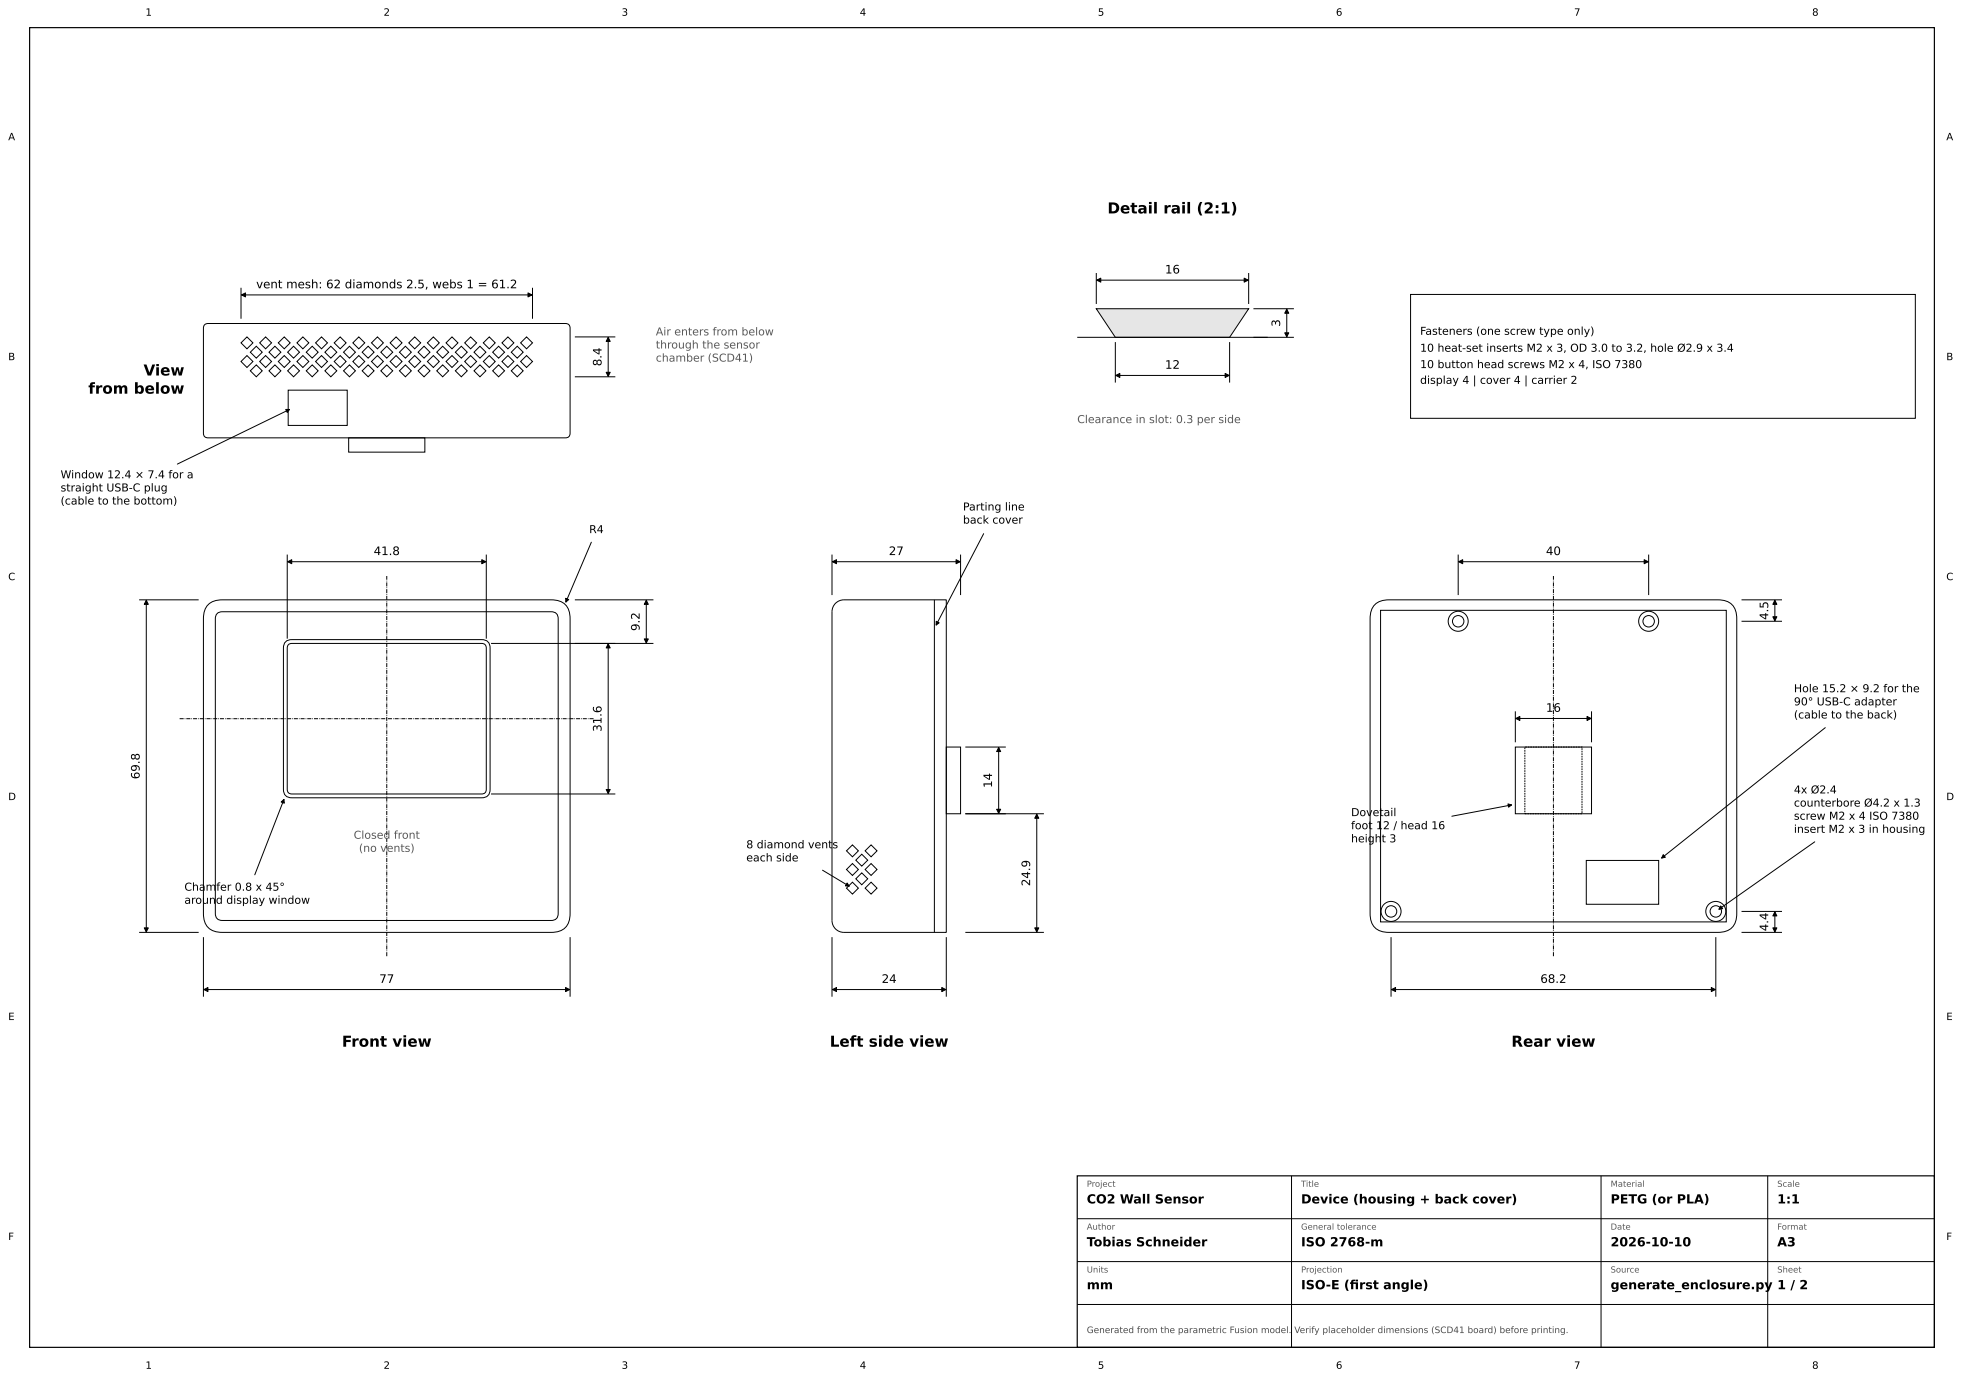
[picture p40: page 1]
Project CO2 Wall Sensor; Scale 1:1; Author Tobias Schneider; General tolerance ISO 2768-m; Date 2026-10-10; Format A3; Units mm; Source generate_enclosure.py; Sheet 1 / 2; Generated from the parametric Fusion model.; Verify placeholder dimensions (SCD41 board) before printing.; Front view; Closed front (no vents); 8 diamond vents each side; Parting line back cover; View from below; Rear view; Dovetail foot 12 / head 16 height 3

vent mesh: 62 diamonds 2.5, webs 1 = 61.2

Air enters from below
through the sensor
chamber (SCD41)

Fasteners (one screw type only)
10 heat-set inserts M2 x 3, OD 3.0 to 3.2, hole Ø2.9 x 3.4
10 button head screws M2 x 4, ISO 7380
display 4 | cover 4 | carrier 2

Clearance in slot: 0.3 per side

Window 12.4 × 7.4 for a
straight USB-C plug
(cable to the bottom)

Hole 15.2 × 9.2 for the
90° USB-C adapter
(cable to the back)

counterbore Ø4.2 x 1.3
screw M2 x 4 ISO 7380
insert M2 x 3 in housing

Chamfer 0.8 x 45°
around display window

Left side view

Title
Device (housing + back cover)

Material
PETG (or PLA)

Projection
ISO-E (first angle)

## Wall plate, front view

A

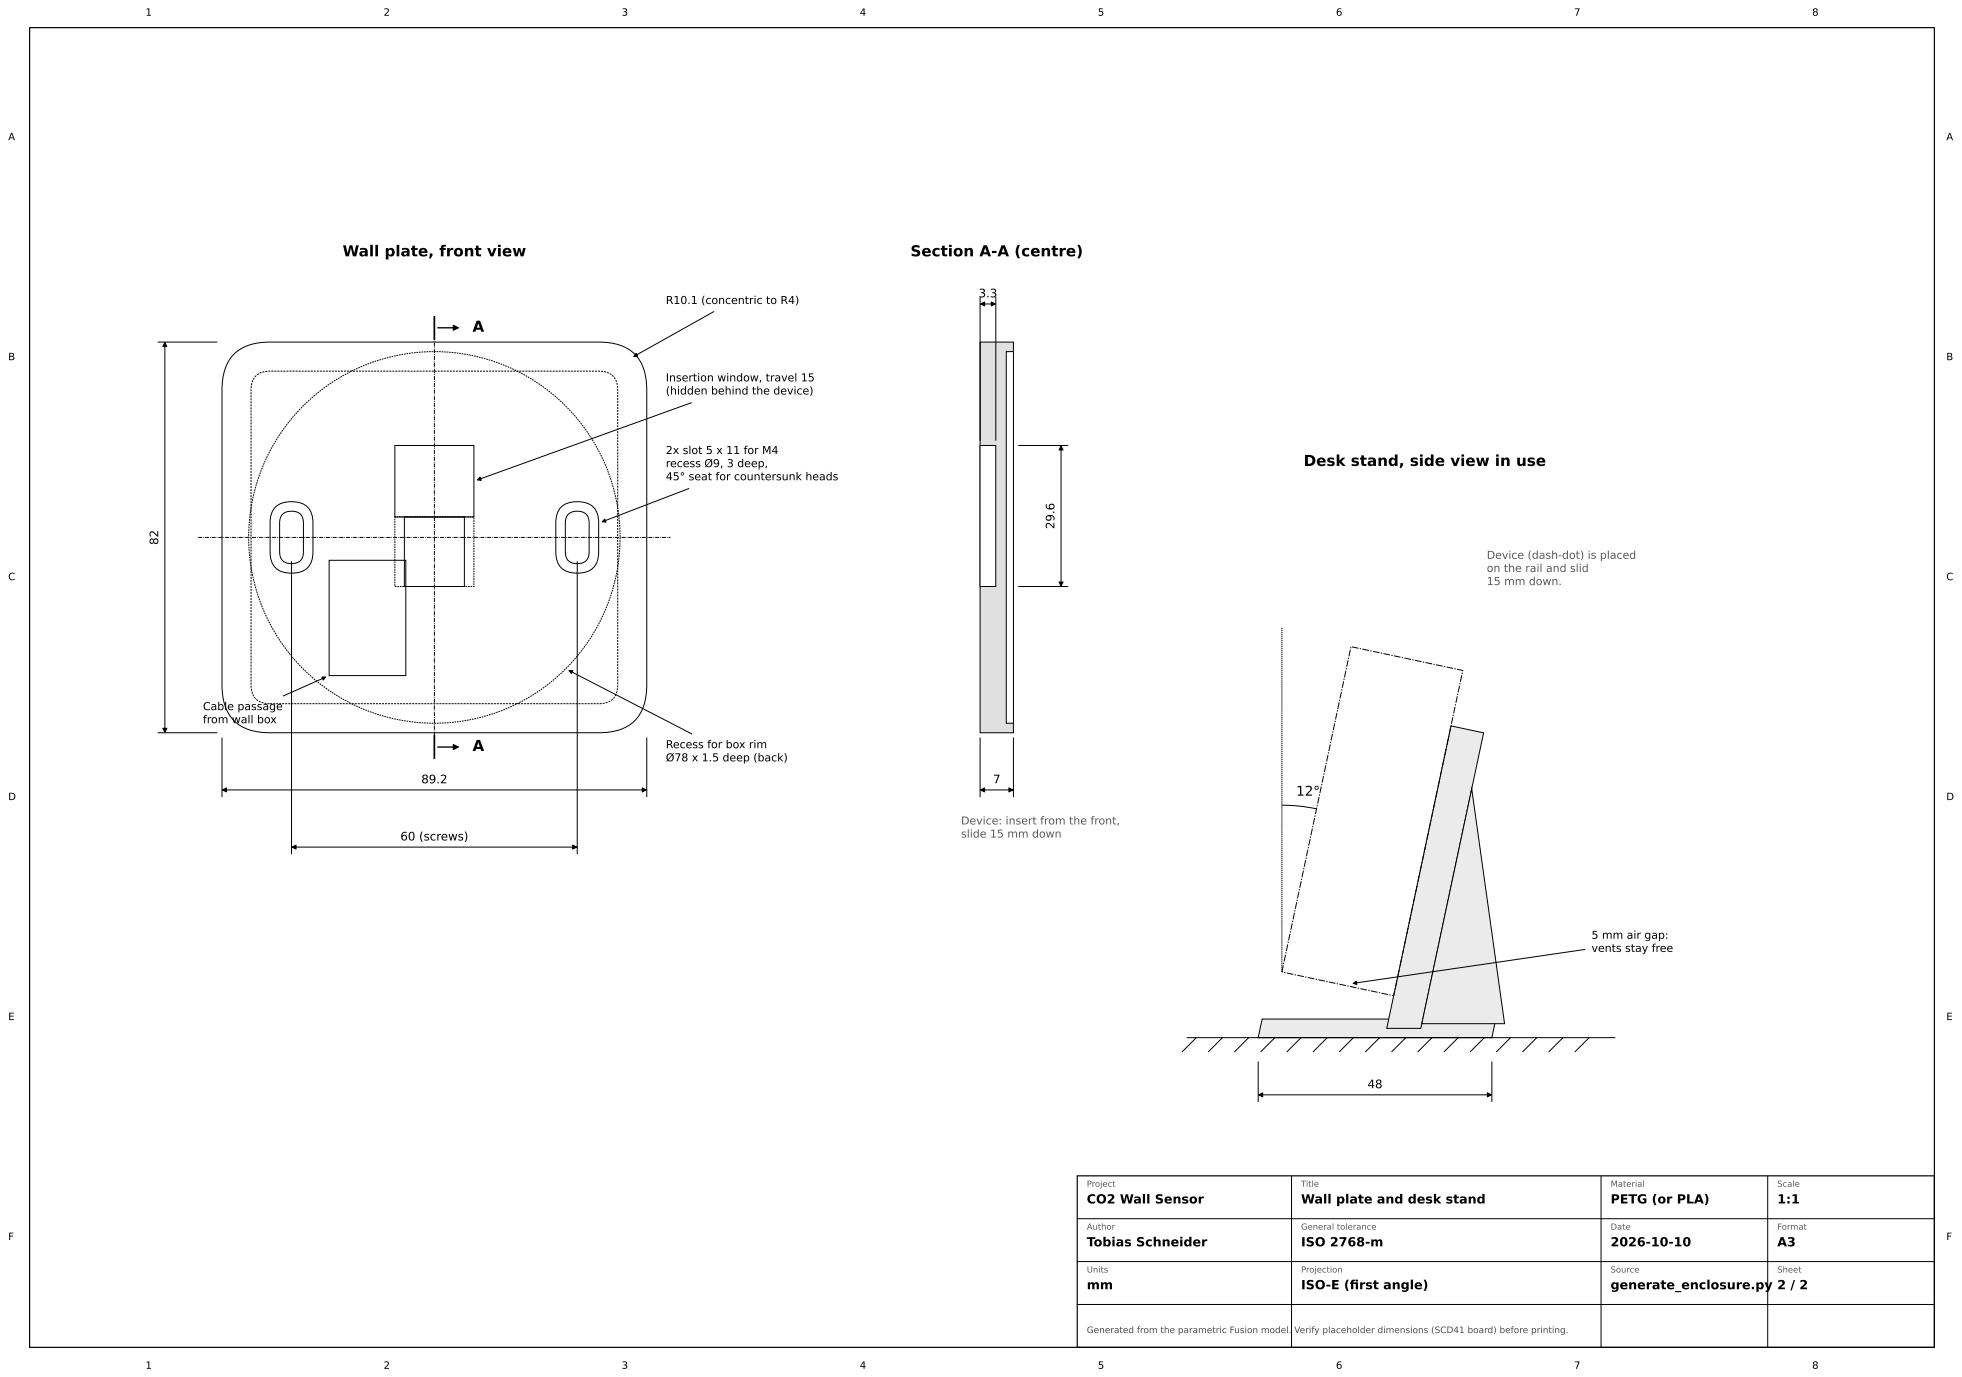
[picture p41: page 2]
Project CO2 Wall Sensor; Scale 1:1; Author Tobias Schneider; General tolerance ISO 2768-m; Date 2026-10-10; Format A3; Units mm; Source generate_enclosure.py; Sheet 2 / 2; Generated from the parametric Fusion model.; Verify placeholder dimensions (SCD41 board) before printing.; 60 (screws); R10.1 (concentric to R4); Section A-A (centre)

Insertion window, travel 15
(hidden behind the device)

2x slot 5 x 11 for M4
recess Ø9, 3 deep,
45° seat for countersunk heads

Desk stand, side view in use

Device (dash-dot) is placed
on the rail and slid
15 mm down.

Cable passage
from wall box

Recess for box rim
Ø78 x 1.5 deep (back)

Device: insert from the front,
slide 15 mm down

5 mm air gap:
vents stay free

Title
Wall plate and desk stand

Material
PETG (or PLA)

Projection
ISO-E (first angle)

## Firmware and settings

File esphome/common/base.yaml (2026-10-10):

# =============================================================================
#  CO2 Wall Sensor  |  shared firmware logic (language independent)
# -----------------------------------------------------------------------------
#  Do not flash this file directly. Use one of the device files:
#    ../co2-wall-sensor.yaml             own build, English interface
#    ../co2-wall-sensor-de.yaml          own build, German interface
#    ../co2-wall-sensor-factory.yaml     browser installer, English interface
#    ../co2-wall-sensor-de-factory.yaml  browser installer, German interface
#  Network settings come from network_secrets.yaml (own build) or
#  network_factory.yaml (browser installer, WiFi set up via Improv or hotspot).
#  All user-visible texts come from substitutions defined in the device files.
#
#  Hardware: ESP32-C3 SuperMini, Sensirion SCD41 (I2C), Waveshare 2inch LCD (ST7789V, SPI)
#  Wiring:   docs/wiring.md
# =============================================================================

substitutions:
  # Defaults, can be overridden in the device file
  co2_yellow_default: "1000"
  co2_red_default: "1400"
  temperature_offset: "2.0"     # self-heating compensation, fine-tune it in Home Assistant (temperature correction)
  altitude: "300"               # altitude above sea level in m (start value, set it in Home Assistant)
  trend_rising: "100"           # ppm per hour: from here the display shows a rising arrow
  day_brightness: "80"          # percent
  # outdoor values: a real sensor (rename its entity ID in Home Assistant) wins over the weather forecast
  outdoor_temperature_entity: sensor.outdoor_temperature
  outdoor_humidity_entity: sensor.outdoor_humidity
  weather_entity: weather.forecast_home

esphome:
  name: ${name}
  friendly_name: ${friendly_name}
  project:
    name: "tobi136b.co2-wall-sensor"
    version: "2.0.2"  # x-release-please-version
  on_boot:
    priority: 600
    then:
      - light.turn_on:
          id: backlight
          brightness: ${day_brightness}%

esp32:
  board: esp32-c3-devkitm-1
  variant: esp32c3
  framework:
    type: esp-idf

logger:
  hardware_uart: USB_SERIAL_JTAG

time:
  - platform: homeassistant
    id: ha_time

# night schedule: applied only when day and night change, so a manual change in Home Assistant stays
interval:
  - interval: 20s
    then:
      - lambda: |-
          static int last = -1;   // 0 day, 1 night dimmed, 2 night off, 3 night off but red warning
          auto now = id(ha_time).now();
          if (!now.is_valid()) return;
          const int m = now.hour * 60 + now.minute;
          const int s = id(night_start).hour * 60 + id(night_start).minute;
          const int e = id(night_end).hour * 60 + id(night_end).minute;
          bool night = s < e ? (m >= s && m < e) : (m >= s || m < e);
          if (!id(night_mode).state || s == e) night = false;
          const bool red = id(co2).has_state() && id(co2).state >= id(threshold_red).state;
          int state = 0;
          if (night) {
            if (id(night_display).active_index() == 1) state = (red && id(night_warning).state) ? 3 : 2;
            else state = 1;
          }
          if (state == last) return;
          last = state;
          if (state == 2) {
            auto call = id(backlight).turn_off();
            call.perform();
          } else {
            auto call = id(backlight).turn_on();
            call.set_brightness(state == 0 ? ${day_brightness} / 100.0f
                                           : id(night_brightness).state / 100.0f);
            call.perform();
          }

# ----------------------------------------------------------------------------- buses
i2c:
  id: i2c_bus
  sda: GPIO0
  scl: GPIO1
  frequency: 100kHz

spi:
  id: spi_bus
  clk_pin: GPIO4
  mosi_pin: GPIO6
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

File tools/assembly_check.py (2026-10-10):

#!/usr/bin/env python3
"""
Collision check of the 3D assembly guide: no part may pass through another one.

Replays every motion of site/assembly.js with the same rules and timing (tools/assembly_model.py):

    enter     the move into every step: groups follow their stage waypoints, then the new parts fly in
    explode   the "take apart" slider, move by move, in every distinct state of the guide

At every sample, all visible parts are tested against each other (triangle intersection, python-fcl).
Parts that touch in the assembled device (a board in its rails, a screw in its insert) may keep
touching while they move apart along a single axis, which is how they are pulled out. Any other
contact is an error. The only exception: the display leaves through the window of the housing.

Usage:   python tools/assembly_check.py          (exit 1 on collisions)
"""

from __future__ import annotations

import json
import sys
from pathlib import Path

import numpy as np
import trimesh

sys.path.insert(0, str(Path(__file__).resolve().parent))
import assembly_model  # noqa: E402
import drawing  # noqa: E402

ROOT = Path(__file__).resolve().parents[1]
HERO = ROOT / "cad" / "fusion" / "hero_motion.json"
STEP_MM = 0.7  # largest distance a part moves between two samples (thinnest wall: 0.8 mm)
# the display leaves through the window to the front, as in the README animation (kept on purpose)
ALLOWED = {frozenset(("display", "housing")), frozenset(("display", "inserts"))}
# the ESP32-C3 slides over the spring hook of its sled: allowed while it moves along its guides only
SLIDING = {frozenset(("carrier", "esp32"))}
WIRE_R = assembly_model.WIRE_R
WIRE_END = 2.0  # mm at both ends of a wire where it may touch its pad, its plug or the other wire on the same pad


def mesh_of(part: dict) -> trimesh.Trimesh | None:
    out = []
    for m in part["meshes"]:
        if m["type"] == "stl":
            out.append(trimesh.load(ROOT / "cad" / "stl" / m["file"], force="mesh"))
        elif m["type"] == "box":
            a, b = np.array(m["min"], float), np.array(m["max"], float)
            out.append(
                trimesh.creation.box(extents=b - a, transform=trimesh.transformations.translation_matrix((a + b) / 2))
            )
        elif m["type"] == "cyl":
            d = np.array(m["d"], float)
            d /= np.linalg.norm(d)
            t = trimesh.geometry.align_vectors([0, 0, 1], d)
            t[:3, 3] = np.array(m["p"], float) + d * m["len"] / 2
            out.append(trimesh.creation.cylinder(radius=m["r"], height=m["len"], transform=t, sections=20))
    return trimesh.util.concatenate(out) if out else None


# ----------------------------------------------------------------------------- motion rules (as in site/assembly.js)
def ease(t: float) -> float:
    return 4 * t**3 if t < 0.5 else 1 - (-2 * t + 2) ** 3 / 2


def stage_waypoints(data: dict, part: dict, stage: str) -> list[np.ndarray]:
    s = data["stages"].get(stage or "", {})
    for g in part["groups"]:
        if g in s:
            return [np.array(w, float) for w in s[g]]
    return []


def stage_path(data: dict, part: dict, a: str, b: str) -> list[np.ndarray]:
    """Waypoints from stage a to stage b: back along the waypoints of a, then out along those of b."""
    wa, wb = stage_waypoints(data, part, a), stage_waypoints(data, part, b)
    if a == b or (not wa and not wb):
        return [wa[-1] if wa else np.zeros(3)]
    pts = [wa[-1] if wa else np.zeros(3)] + wa[-2::-1] + [np.zeros(3)] + wb
    out = [pts[0]]
    for p in pts[1:]:
        if np.linalg.norm(p - out[-1]) > 1e-9:
            out.append(p)
    return out


def length(points: list[np.ndarray]) -> float:
    return float(sum(np.linalg.norm(b - a) for a, b in zip(points, points[1:], strict=False)))


def duration(points: list[np.ndarray], timing: dict) -> float:
    return max(timing["min_time"], length(points) / timing["speed"]) if len(points) > 1 else 0.0


def at(points: list[np.ndarray], u: float) -> np.ndarray:
    """Point at the fraction u of the arc length of the polyline."""
    total = length(points)
    if total == 0:
        return points[-1].copy()
    s = u * total
    for a, b in zip(points, points[1:], strict=False):
        seg = np.linalg.norm(b - a)
        if s <= seg:
            return a + (b - a) * (s / seg if seg else 0)
        s -= seg
    return points[-1].copy()


def enter_motion(data: dict, index: int) -> dict[str, tuple[list[np.ndarray], float, float]]:
    """Path, start time and duration of every visible part while the guide moves from step index-1 to index."""
    timing = data["timing"]
    steps = data["steps"]
    step = steps[index]
    prev = steps[index - 1] if index else {}
    motions = {}
    t_stage = 0.0
    for part in data["parts"]:
        intro = intro_step(data, part["id"])
        if intro < 0 or intro > index or intro == index:
            continue
        path = stage_path(data, part, prev.get("stage", ""), step.get("stage", ""))
        motions[part["id"]] = (path, 0.0, duration(path, timing))
        t_stage = max(t_stage, duration(path, timing))
    start = t_stage + timing["pause"]
    for pid in step.get("new", []):  # one part after the other, each starts when the previous one is in place
        part = part_by_id(data, pid)
        end = stage_path(data, part, step.get("stage", ""), step.get("stage", ""))[-1]
        off = step.get("from_part", {}).get(pid, step.get("from"))
        path = [end + np.array(off, float), end] if off else [end]
        motions[pid] = (path, start, duration(path, timing))
        start += duration(path, timing) + timing["pause"]
    return motions


def intro_step(data: dict, pid: str) -> int:
    for i, s in enumerate(data["steps"]):
        if pid in s.get("new", []):
            return i
    return -1


def part_by_id(data: dict, pid: str) -> dict:
    return next(q for q in data["parts"] if q["id"] == pid)


def explode_moves(data: dict, visible: set[str]) -> list[dict]:
    return [m for m in data["explode"] if set(m) & visible]


# ----------------------------------------------------------------------------- collision test
def eroded(mesh: trimesh.Trimesh, depth: float = 0.15) -> trimesh.Trimesh:
    """The mesh shrunk by about depth: faces that only touch no longer count as a collision."""
    m = mesh.copy()
    m.vertices = m.vertices - m.vertex_normals * depth
    return m


class Scene:
    """
    Three kinds of part pairs:
        touching   faces touch in the assembled device (a board on its ledge): tested shrunk by 0.15 mm,
                   so sliding along each other is fine but running into a boss is not
        nested     overlap even when shrunk (a screw in its insert, a board under spring preload):
                   may only move apart along one axis, the way they are pulled out
        all others tested exactly
    """

    def __init__(self, data: dict):
        self.data = data
        self.meshes = {q["id"]: m for q in data["parts"] if (m := mesh_of(q)) is not None}
        # the desk stand is not part of the guide, it is checked on its own (check_desk_stand)
        self.meshes["desk_stand"] = trimesh.load(ROOT / "cad" / "stl" / "desk_stand.stl", force="mesh")
        self.exact = self._manager(self.meshes)
        self.shrunk = self._manager({pid: eroded(m) for pid, m in self.meshes.items()})
        self.touching = self._pairs(self.exact)
        self.nested = self._pairs(self.shrunk) | SLIDING

    @staticmethod
    def _manager(meshes: dict) -> trimesh.collision.CollisionManager:
        manager = trimesh.collision.CollisionManager()
        for pid, m in meshes.items():
            manager.add_object(pid, m)
        return manager

    @staticmethod
    def _pairs(manager: trimesh.collision.CollisionManager) -> set[frozenset]:
        _, names = manager.in_collision_internal(return_names=True)
        return {frozenset(n) for n in names}

    def _hits(self, manager, offsets: dict[str, np.ndarray]) -> set[frozenset]:
        for k, pid in enumerate(self.meshes):
            # parts that are not shown yet wait far away, each in its own place
            off = offsets.get(pid, np.array([1e5 * (k + 1), 0, 0]))
            manager.set_transform(pid, trimesh.transformations.translation_matrix(off))
        hit, names = manager.in_collision_internal(return_names=True)
        return {frozenset(n) for n in names} if hit else set()

    def collisions(self, offsets: dict[str, np.ndarray]) -> list[tuple[str, str]]:
        exact = self._hits(self.exact, offsets)
        if not exact:
            return []
        shrunk = self._hits(self.shrunk, offsets) if exact & self.touching else set()
        bad = []
        for pair in exact:
            a, b = sorted(pair)
            if pair in ALLOWED:
                continue
            if pair in self.nested:
                if np.count_nonzero(np.abs(offsets[a] - offsets[b]) > 1e-6) <= 1:
                    continue  # pulled out of its seat along one axis
            elif pair in self.touching and pair not in shrunk:
                continue  # only sliding along each other
            bad.append((a, b))
        return bad


def check_enter(scene: Scene, index: int) -> list[str]:
    data = scene.data
    motions = enter_motion(data, index)
    end = max((t0 + d for _, t0, d in motions.values()), default=0.0)
    fastest = max((length(p) / d for p, _, d in motions.values() if d > 0), default=1.0)
    n = max(2, int(np.ceil(end * fastest * 2 / STEP_MM)))  # the eased speed peaks at about twice the mean
    errors = set()
    for t in np.linspace(0, end, n):
        offsets = {}
        for pid, (path, t0, d) in motions.items():
            if t < t0:
                continue  # a new part appears when its move starts
            u = 1.0 if d == 0 else min(1.0, max(0.0, (t - t0) / d))
            offsets[pid] = at(path, ease(u))
        for pair in scene.collisions(offsets):
            errors.add(f"step {index + 1} ({data['steps'][index]['title']['en']}), moving in: {pair[0]} hits {pair[1]}")
    return sorted(errors)


def check_explode(scene: Scene, index: int) -> list[str]:
    data = scene.data
    step = data["steps"][index]
    visible = {q["id"] for q in data["parts"] if 0 <= intro_step(data, q["id"]) <= index}
    base = {
        pid: stage_path(data, part_by_id(data, pid), step.get("stage", ""), step.get("stage", ""))[-1]
        for pid in visible
    }
    errors = set()
    done = {pid: np.zeros(3) for pid in visible}
    for k, move in enumerate(explode_moves(data, visible)):
        dist = max(np.linalg.norm(v) for v in move.values())
        for u in np.linspace(0, 1, max(2, int(np.ceil(dist / STEP_MM)) + 1)):
            offsets = {pid: base[pid] + done[pid] for pid in visible}
            for pid, v in move.items():
                if pid in visible:
                    offsets[pid] = offsets[pid] + np.array(v, float) * u
            for pair in scene.collisions(offsets):
                errors.add(f"step {index + 1}, take apart, move {k + 1} {sorted(move)}: {pair[0]} hits {pair[1]}")
        for pid, v in move.items():
            if pid in visible:
                done[pid] = done[pid] + np.array(v, float)
    return sorted(errors)


def hero_offset(keys: list, t: float) -> np.ndarray:
    """Offset at t of a keyframe track [[t, [x, y, z]], ...], eased between the keyframes (as in render_views.py)."""
    if t <= keys[0][0]:
        return np.array(keys[0][1], float)
    for (t0, a), (t1, b) in zip(keys, keys[1:], strict=False):
        if t <= t1:
            u = ease((t - t0) / (t1 - t0)) if t1 > t0 else 1.0
            return np.array(a, float) + (np.array(b, float) - np.array(a, float)) * u
    return np.array(keys[-1][1], float)


def check_hero(scene: Scene) -> list[str]:
    """The README animation (cad/fusion/hero_motion.json) shows the parts of the Fusion design only."""
    motion = json.loads(HERO.read_text(encoding="utf-8"))
    ids, tracks = motion["ids"], motion["parts"]
    fastest = max(
        np.linalg.norm(np.array(b, float) - np.array(a, float)) / (t1 - t0)
        for keys in tracks.values()
        for (t0, a), (t1, b) in zip(keys, keys[1:], strict=False)
        if t1 > t0
    )
    first: dict[tuple[str, str], float] = {}
    for t in np.linspace(0, 1, int(np.ceil(fastest * 1.5 / STEP_MM)) + 1):  # eased peak speed is 1.5 x the mean
        offsets = {pid: np.zeros(3) for pid in ids.values()}
        for comp, keys in tracks.items():
            offsets[ids[comp]] = hero_offset(keys, t)
        for pair in scene.collisions(offsets):
            first.setdefault(pair, t)
    where = "README animation (cad/fusion/hero_motion.json)"
    return [f"{where} from t = {t:.3f}: {a} hits {b}" for (a, b), t in first.items()]


def check_desk_stand(scene: Scene) -> list[str]:
    """The device slides 15 mm down onto the desk stand, as onto the wall plate."""
    device = [q["id"] for q in scene.data["parts"] if "device" in q["groups"] and not q["id"].startswith("wires")]
    travel = scene.data["stages"]["device_away"]["device"][0][1]
    errors = set()
    for dy in np.linspace(travel, 0, int(np.ceil(travel / STEP_MM)) + 1):
        offsets = {pid: np.array([0, dy, 0]) for pid in device}
        offsets["desk_stand"] = np.zeros(3)
        for a, b in scene.collisions(offsets):
            errors.add(f"desk stand, sliding the device on: {a} hits {b}")
    return sorted(errors)


def _wire_samples(points: list, step: float = 0.3) -> tuple[np.ndarray, np.ndarray]:
    """Points along a wire and their distance from the nearer end."""
    pts = [np.array(points[0], float)]
    for q in points[1:]:
        q = np.array(q, float)
        n = max(1, int(np.ceil(np.linalg.norm(q - pts[-1]) / step)))
        a = pts[-1]
        pts += [a + (q - a) * k / n for k in range(1, n + 1)]
    pts = np.array(pts)
    run = np.concatenate([[0.0], np.cumsum(np.linalg.norm(np.diff(pts, axis=0), axis=1))])
    return pts, np.minimum(run, run[-1] - run)


def check_wires(scene: Scene) -> list[str]:
    """In the assembled device every wire keeps its distance to every other wire and to every part."""
    wires = []
    for q in scene.data["parts"]:
        for m in q["meshes"]:
            if m["type"] == "tube":
                pts, end = _wire_samples(m["points"])
                wires.append((f"{q['id']} {m['label']}", pts[end > WIRE_END], m.get("r", WIRE_R)))
    errors = []
    for i, (na, a, ra) in enumerate(wires):
        for nb, b, rb in wires[i + 1 :]:
            d = np.min(np.linalg.norm(a[:, None, :] - b[None, :, :], axis=2))
            if d < ra + rb - 0.02:
                errors.append(f"wires: {na} and {nb} come {d:.2f} mm close (pass through each other)")
    for pid, mesh in scene.meshes.items():
        if pid == "desk_stand":
            continue
        for name, pts, r in wires:
            inside = trimesh.proximity.signed_distance(mesh, pts)  # positive inside the part
            worst = float(np.max(inside))
            if worst > -(r - 0.05):
                errors.append(f"wires: {name} runs into {pid} ({worst + r:.2f} mm)")
    return errors


def main() -> int:
    data = assembly_model.model(drawing.load_parameters())
    scene = Scene(data)
    errors = check_wires(scene)
    for i in range(len(data["steps"])):
        errors += check_enter(scene, i)
    # the slider in every distinct state: the parts it moves always come in the same order, so a state that
    # shows fewer parts in the same stage cannot collide when the full one does not
    last_of_state = {}
    for i, s in enumerate(data["steps"]):
        last_of_state[s.get("stage", "") or "assembled"] = i
    for i in sorted(set(last_of_state.values())):
        errors += check_explode(scene, i)
    errors += check_hero(scene)
    errors += check_desk_stand(scene)
    for e in errors:
        print(f"::error::{e}")
    print(
        f"assembly guide: {len(data['steps'])} steps, {len(data['explode'])} disassembly moves, "
        f"{'FAIL' if errors else 'no collisions'}"
    )
    return 1 if errors else 0


if __name__ == "__main__":
    sys.exit(main())

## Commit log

2026-10-04 CO2-Wandsensor 1.0.0: Gehaeuse, Wandplatte, Tischstaender, ESPHome-Firmware und Doku
    Claude-Session: https://claude.ai/code/session_015HxB3nZPNGitZsjqH2sYhj
    [co2_wall_sensor.f3d, co2_wall_sensor_baugruppe.step, gehaeuse_front.stl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]
2026-10-04 v1.1.0: English first with full German translation, CI and release builds
    * README, docs, drawing, wiring diagram and firmware in English and German
    * Firmware split into common/base.yaml plus device files (en, de)
    * CAD generator rewritten with English identifiers, direct STL/STEP export
    * Display preview, exploded view and coloured renders
    * Design notes, FAQ, BOM as CSV, contributing guide, issue and PR templates
    * GitHub Actions: firmware compile (en, de), tool checks, release assets
    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
    [back_cover.stl, bom.csv, co2_wall_sensor.f3d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]
2026-10-04 v1.2.0: one screw type, sensor carrier, selectable cable exit
    * All screw connections use M2 x 3 heat-set inserts (OD 3.2) and
    M2 x 4 ISO 7380 button head screws: display 4, back cover 4,
    sensor carrier 2. No plastic screws, no M3 parts.
    * New removable sensor carrier closes the SCD41 chamber and holds
    the ESP32-C3.
    * USB-C socket points down; knock-outs in the bottom wall (straight
    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
    [back_cover.stl, bom.csv, co2_wall_sensor.f3d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]
2026-10-05 feat: v1.3.0 cable port modules, browser installer and release automation
    Enclosure (v1.3)
    * swappable cable port modules (back: right-angle plug with strain relief,
    bottom: straight plug), replacing the knock-outs
    * SCD41 slides into rails, ESP32-C3 held by guides, nothing glued
    * optional lock tab between device and wall plate
    * every dimension is a Fusion user parameter, slider joint in the assembly
    * engraved labels, 45 degree bed foot, insert lead-ins, boss fillets
    * device depth 24 mm, print-ready 3MF plates
    Firmware
    * browser installer variant without credentials (Improv, hotspot,
    ESPHome dashboard import, firmware updates via Home Assistant)
    * network settings split into network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
    [back_cover.stl, bom.csv, cable_port_back.stl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]
2026-10-05 feat: generate shop link tables from hardware/bom.csv
    hardware/bom.csv is now the only place for parts, prices and shop links.
    tools/bom.py writes the tables in README.md and README.de.md, the project
    page reads the same file, and the new Shop links workflow updates the
    README and redeploys the page on every change to bom.csv.
    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
    [bom.csv]
2026-10-05 feat: readable bill of materials in hardware/bom.yaml
    Replace bom.csv with bom.yaml: one block per part, a short explanation at
    the top and clear error messages for typing mistakes. A CSV opened in a
    German Excel ends up in one column and is easily broken on save.
    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
    [bom.csv]
2026-10-05 docs: add sensor carrier profiles and online configurator to the roadmap
    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
2026-10-05 feat(cad): sensor carrier profiles for different SCD41 boards with spring tongue
    Only the sensor carrier depends on the SCD41 breakout. The generator now
    exports one carrier per board profile (14x22 and 15x20, plus a custom one
    from the SCD_* parameters). The board slides in from the top, stands on an
    end stop and a 45 degree hook on a tongue cut out of the carrier presses it
    down, taking up +-0.4 mm without play. Pads on a rail side get an open lip
    and a relief for the solder joints.
    Also: reference parts are see-through and coloured, the generator warns if
    a board does not fit, new docs page and measuring sketch (EN/DE).
    Closes #7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
    [back_cover.stl, cable_port_back.stl, cable_port_bottom.stl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]
2026-10-06 docs: room size and placement of the sensor
    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
2026-10-06 feat(cad): printability for 0.4 mm nozzles and diamond vent mesh (#9)
    * feat(cad): printability for 0.4 mm nozzles and diamond vent mesh
    * tools/print_check.py measures the wall thickness of every STL file and
    fails below 0.8 mm (2 lines of a 0.4 mm nozzle); runs in the CI.
    * Screw head recesses that left a 0.1 to 0.2 mm skin at the edge of the
    back cover and the lock tab are opened towards the edge.
    * SCD41 end stops 0.8 mm, ESP32-C3 groove lips 1.2 x 1.0 mm.
    * Vents are a diamond mesh (2.5 mm, webs 1 mm) instead of slots: prints
    without support on the vertical walls, about 40 % more open area.
    * New parameters MIN_WALL, VENT_HOLE, VENT_WEB; drawing shows the mesh.
    The print files s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
    [back_cover.stl, co2_wall_sensor.f3d, co2_wall_sensor_assembly.step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]
2026-10-06 ci: key the ESPHome build cache by Python version
    A stale build directory pointed to the ninja of an older runner Python
    and broke the de-installer build of release 1.5.0.
    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
2026-10-06 feat(firmware): CO2 trend arrow and ventilation forecast (#11)
    * New sensor CO2 trend (ppm/h): linear fit over the last 15 minutes.
    * New sensor Ventilate in (min): time until the red threshold at the
    current trend, only while rising.
    * Display: trend arrow below the unit, forecast below the 3 h curve.
    * Display preview updated.
    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
2026-10-06 feat: interactive 3D assembly guide and new README animation (#13)
    * docs: README animation with the live display interface
    The device turns, comes apart part by part and assembles itself again,
    the display shows the real interface. Rendered in Fusion
    (render_views.render_hero), the interface is projected onto the glass
    with the Fusion camera (tools/build_gif.py). One GIF per language.
    * docs: README animation swings to the side so every part is visible
    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
2026-10-07 feat: measured ESP32-C3 holder, collision-free assembly and new animation (#14)
    * wip: collision-free assembly guide and CAD fixes found by the new check
    Not pushed on purpose: Tobi wants to see the result before it goes to GitHub.
    Sensor carrier STLs still need the export with LOCK_X = -19.
    * wip: collision-free take apart, CAD fixes exported from Fusion
    * wip: classic README animation, smoother and collision-free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
    [back_cover.stl, cable_port_back.stl, cable_port_bottom.stl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]
2026-10-07 fix(cad): measured right-angle plug and inserts of both diameters (#16)
    * wip(display): preview of the outdoor temperature and the window hint
    * wip(display): instrument-style footer with IN, OUT and humidity
    * docs(drawing): oblong boot slot of the cable port
    * fix(cad): measured right-angle plug, inserts of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
    [back_cover.stl, cable_port_back.stl, cable_port_bottom.stl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]
2026-10-07 fix: shop links, prices and pictures match the current state (#18)
    * docs: current 3D guide screenshots, social preview from the current render, plug and ESP facts
    * fix: shop links and prices of the parts you bought, no empty shop cells
    ---------
    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
    [bom.py, build_site.py, social_preview.py]
2026-10-07 feat(firmware): outdoor values, window hint and settings in Home Assistant (#21)
    Outdoor temperature and humidity from a real sensor or the weather forecast, IN/OUT footer, window hint, night schedule and all settings as HA entities. Step by step guide with pictures generated fro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
2026-10-08 fix(cad): measured display dimensions, enclosure version in README and releases (#23)
    * fix(cad): measured Waveshare 2inch display dimensions
    Display PCB 58.2 x 35.3 x 1.62 mm, glass 47.7 x 34.6 mm and glass thickness
    2.9 mm (2.81 measured + 0.1) replace the datasheet values and the 2.5 mm
    assumption. The display bosses now end exactly on the PCB, the screws no
    longer press the glass against the front lip. Enclosure version 1.7, all
    print files, STEP, 3MF plates and drawings exported again. No interference,
    print check and assembly check pass.
    Claude-Session: https://claude.ai/code/session_012MD8nL62A9pM9vLkMPwVYq
    * docs: show the en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
    [back_cover.stl, co2_wall_sensor.f3d, co2_wall_sensor_assembly.step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]
2026-10-08 feat: cable routing without glue, sensor carrier configurator, smarter window hint (#25)
    * feat: cable routing without glue, sensor carrier configurator, smarter window hint
    Enclosure v1.8:
    * sensor carrier: narrow 1.3 mm wire slot instead of the glued notch, the
    four SCD41 wires fill it; printed wire clip with snap lip on the back
    * display cable path straight across the back of the display, kept free
    by the collision check (new DisplayCable reference body)
    Configurator (#8): site/configurator.html builds the sensor carrier from
    the six board values in the browser (manifold-3d) and offers it as STL.
    tools/configurator_check.py compares it with the Fusion export of every
    known board in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
    [back_cover.stl, co2_wall_sensor.f3d, co2_wall_sensor_assembly.step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]
2026-10-10 feat(enclosure)!: enclosure 2.0 after the first print (#27)
    The housing is 77 mm wide: the display cable stays plugged in, the display only
    fits one way and the electronics strip of the glass stays behind the frame. The
    ESP32-C3 slides onto a sled with a spring hook, a printed bridge holds the
    display cable. A 90 degree USB-C adapter leads the cable to the back, a
    straight plug leaves through a window in the bottom, the loose port module and
    the lock tab are gone. Wall plate with slots for M4 screws. New HA switch to
    turn the picture by 180 degrees. 3D guide with 12 steps and clean wire routes,
    checked for collisions.
    BREAKING CHANGE: enclosure 2.0, the printed parts of 1.x do not fit toget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
    [back_cover.stl, cable_port_back.stl, cable_port_bottom.stl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]
2026-10-10 fix(enclosure): display upright, connector on the left (#29)
    * fix(enclosure): display upright, connector on the left
    The display now sits in its normal orientation: seen from the back the
    PH2.0 connector is on the left, the picture stands upright and the strip
    with the electronics stays hidden behind the frame. The cable bay moved
    to the left, the flat cable folds back at the left wall and runs behind
    the display to the ESP32-C3. The firmware rotation is back to 90, the
    Home Assistant switch stays as a fallback.
    * docs: renders, animation and step pictures for t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
    [co2_wall_sensor.f3d, co2_wall_sensor_assembly.step, co2_wall_sensor_device.3mf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]
2026-10-10 fix(enclosure): bold engraved labels that print cleanly (#31)
    * fix(enclosure): bold engraved labels that print cleanly
    The version labels were too small and too thin to print: 1.5 to 2.2 mm high
    in a light font, 0.4 mm deep. Now they use a heavy font, 0.6 mm deep, start
    at 3.5 mm and shrink only until they fit their field, never below 2.4 mm.
    The texts are shorter: CO2 v2.0, the carrier shows v2.0 and its profile,
    COVER v2.0 / FACE DOWN, WALL PLATE v2.0.
    * docs: renders and pictures with the new labels
    Cla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
    [back_cover.stl, co2_wall_sensor.f3d, co2_wall_sensor_assembly.step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]
2026-10-11 feat(enclosure): version 2.1 (#33)
    * wip(enclosure): prepare 2.1 (more play, slot with blank, closed cover, lead-ins, pull tab, bosses)
    Not built yet, waits for Fusion and a decision on the open points.
    * feat(enclosure): version 2.1 with more play and a clean part for the unused cable opening
    * every sliding and plugged fit 0.4 mm per side, 0.8 mm air above the display
    connector, 1 mm around the 90 degree adapter, 0.4 mm around a straight plug
    * the device is 79.6 mm wide, the bent display cable keeps 2 mm air at the wall
    * slot in the bottom wall, open to th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
2026-10-11 feat: window contacts, insert bosses as corner columns (enclosure 2.2) (#35)
    * feat: window contacts from Home Assistant, insert bosses as corner columns (enclosure 2.2)
    Firmware: a window contact or a binary sensor group from Home Assistant
    (window_entity). While a window is open the display shows a window symbol and
    the hint line counts the airing minutes; once the air is fresh (300 ppm below
    the yellow threshold, at least 600 ppm) it turns green: close the window.
    More windows are added to the group in Home Assistant, no new firmware.
    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
2026-10-12 feat(enclosure): version 2.3, print ready with measured adapter and blank in a T-track (#37)
    * feat(enclosure): version 2.3 with the measured 90 degree adapter and the blank in a T-track
    - Adapter pocket from the measured sonero adapter (19.91 x 12.87 x 8.37 mm, plug 7.77 mm) with 1 mm play
    - Straight cable slot 12.5 x 7 mm for the measured plug overmould
    - Bottom blank slides into a T-track behind a 0.8 mm lip, held by crush ribs and the cover
    - Cover gets a relief over the display wires
    - Docs updated to the measured parts
    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
2026-10-12 feat: window states in colour, more settings in Home Assistant and a blueprint that follows the window (#39)
    * wip: window states, new Home Assistant settings, blueprint with window logic
    Not released yet, continues after the enclosure.
    * feat: window states in colour, more settings and a blueprint that follows the window
    - Blueprint triggers on conditions, so a reminder also comes after the window was shut too early
    and the cooling warning also comes when the window opens in a cold room
    - Home Assistant guide in English and German, step by step
    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
2026-10-15 fix(docs): SCD41 wires only in colours of the wire set, SCL yellow (#44)
    * fix(docs): SCD41 wires only in colours of the silicone wire set, SCL yellow
    The wiring plan showed SCL in turquoise, which the wire set does not have. The footer now says
    the display cable is soldered by its labels, not by colour, and gives 8 cm for the SCD41 wires.
    * docs(images): wiring plan and guide pictures with the yellow SCL wire
    Co-authored-by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
2026-10-15 feat(enclosure): version 2.4, every wire soldered from below with room behind the boards (#46)
    * feat(enclosure): version 2.4, every wire soldered from below with room behind the boards
    Only the sensor carrier changes, all other parts of 2.3 fit.
    - SCD41: channel behind the solder pads up to the top of the carrier, 1.6 mm deep where the joints pass
    while the board slides in, a pad on the back keeps the wall at 0.8 mm
    - ESP32-C3: free space of 1.5 mm under the board, open at the top; the board rests on the middle rail of
    the spring tongue and two short posts; notch in the left guide for the SCD41 wires
    - 3D guide, assembly steps and wiring docs: soldering from below, wire colours, order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
2026-10-15 feat(enclosure): version 2.5, air behind the whole SCD41, rail lead-ins, hide parts in the 3D guide (#48)
    * feat(guide): show and hide single parts, double-click hides a part (work in progress)
    * feat(enclosure): version 2.5, air behind the whole SCD41, rail lead-ins, hide parts in the 3D guide
    - 1 mm of air behind the whole SCD41 over its whole way in, it rests on its edges only
    - 45 degree lead-ins at the top of the SCD41 rails
    - 3D guide: show and hide single parts, double-click hides the part under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
2026-10-16 fix(docs): wiring plan and 3D guide in the real colours of the Waveshare cable (work in progress)
    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
2026-10-16 docs(wiring): wire colours of the display cable in the tables
    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

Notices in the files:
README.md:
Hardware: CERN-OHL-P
